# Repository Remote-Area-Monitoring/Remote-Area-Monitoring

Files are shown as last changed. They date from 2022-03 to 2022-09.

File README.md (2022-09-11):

# Remote-Area-Monitoring

# Product Overview
Remote Area Monitoring is a system designed to reduce the risk of forest fires to populated areas. Our system provides forest management personnel with a data rich view of their environment. The data is collected by a mesh network of sensing nodes and recorded to provide a history of environmental conditions. RAM provides granular insight for the area’s most at risk. Our hope is that the information gathered by our system will aid those responsible for forest management in the prevention of forest fires by prompting preventative actions.

# Design Overview
### YouTube Video:
Design Overview (https://youtu.be/89cSm1rO_VM "Remote Area Monitoring - Design Overview")

# Product Demonstration
### YouTube Video:
Project Demonstration (https://youtu.be/TYpCOS8Fa0I "Remote Area Monitoring - Project Demonstration")

#### Additional Note

This project was completed as part of the University of Central Florida, Department of Electrical and Computer Engineering's senior design program. The project was active from the Spring 2022 semester to the Summer 2022 semester.

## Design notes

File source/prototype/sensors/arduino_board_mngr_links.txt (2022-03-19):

http://arduino.esp8266.com/stable/package_esp8266com_index.json
https://arduino.esp8266.com/stable/package_esp8266com_index.json
https://dl.espressif.com/dl/package_esp32_index.json
https://raw.githubusercontent.com/damellis/attiny/ide-1.6.x-boards-manager/package_damellis_attiny_index.json

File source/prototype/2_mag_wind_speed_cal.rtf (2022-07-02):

⸮⸮⸮⸮⸮⸮⸮⸮⸮⸮⸮⸮⸮⸮⸮⸮⸮0
Calibration Factor: 440000
MPH: 0

0
Calibration Factor: 440000
MPH: 0

697669
Calibration Factor: 440000
MPH: 0

46506
Calibration Factor: 440000
MPH: 9

61710
Calibration Factor: 440000
MPH: 7

68220
Calibration Factor: 440000
MPH: 6

76857
Calibration Factor: 440000
MPH: 5

86480
Calibration Factor: 440000
MPH: 5

97868
Calibration Factor: 440000
MPH: 4

110669
Calibration Factor: 440000
MPH: 3

126365
Calibration Factor: 440000
MPH: 3

144545
Calibration Factor: 440000
MPH: 3

171445
Calibration Factor: 440000
MPH: 2

167685
Calibration Factor: 440000
MPH: 2

203662
Calibration Factor: 440000
MPH: 2

198138
Calibration Factor: 440000
MPH: 2

249998
Calibration Factor: 440000
MPH: 1

243616
Calibration Factor: 440000
MPH: 1

324397
Calibration Factor: 440000
MPH: 1

0
Calibration Factor: 440000
MPH: 0

0
Calibration Factor: 440000
MPH: 0

41045
Calibration Factor: 440000
MPH: 10

53567
Calibration Factor: 440000
MPH: 8

60402
Calibration Factor: 440000
MPH: 7

68616
Calibration Factor: 440000
MPH: 6

77975
Calibration Factor: 440000
MPH: 5

88577
Calibration Factor: 440000
MPH: 4

100935
Calibration Factor: 440000
MPH: 4

115527
Calibration Factor: 440000
MPH: 3

132681
Calibration Factor: 440000
MPH: 3

153295
Calibration Factor: 440000
MPH: 2

187713
Calibration Factor: 440000
MPH: 2

183324
Calibration Factor: 440000
MPH: 2

229262
Calibration Factor: 440000
MPH: 1

216572
Calibration Factor: 440000
MPH: 2

284705
Calibration Factor: 440000
MPH: 1

270662
Calibration Factor: 440000
MPH: 1

407159
Calibration Factor: 440000
MPH: 1

39072
Calibration Factor: 440000
MPH: 11

⸮⸮⸮⸮⸮⸮⸮⸮⸮⸮⸮⸮⸮Calibration Factor: 440000
MPH: 1
ADC Value: 264000

Calibration Factor: 440000
MPH: 1
ADC Value: 403740

Calibration Factor: 440000
MPH: 0
ADC Value: 0

Calibration Factor: 440000
MPH: 0
ADC Value: 0

Calibration Factor: 440000
MPH: 0
ADC Value: 0

Calibration Factor: 440000
MPH: 0
ADC Value: 0

Calibration Factor: 440000
MPH: 13
ADC Value: 33238

Calibration Factor: 440000
MPH: 10
ADC Value: 43509

Calibration Factor: 400000
MPH: 8
ADC Value: 49248

Calibration Factor: 440000
MPH: 5
ADC Value: 73870

Calibration Factor: 440000
MPH: 5
ADC Value: 84664

Calibration Factor: 440000
MPH: 4
ADC Value: 97695

Calibration Factor: 440000
MPH: 3
ADC Value: 112899

Calibration Factor: 440000
MPH: 3
ADC Value: 131107

Calibration Factor: 440000
MPH: 2
ADC Value: 154579

Calibration Factor: 440000
MPH: 0
ADC Value: 0

Calibration Factor: 440000
MPH: 1
ADC Value: 229021

Calibration Factor: 440000
MPH: 1
ADC Value: 320995

Calibration Factor: 440000
MPH: 1
ADC Value: 296799

Calibration Factor: 440000
MPH: 0
ADC Value: 0

Calibration Factor: 440000
MPH: 0
ADC Value: 0

Calibration Factor: 440000
MPH: 1
ADC Value: 424197

Calibration Factor: 400
MPH: 0
ADC Value: 0

Calibration Factor: 440000
MPH: 12
ADC Value: 34989

Calibration Factor: 440000
MPH: 9
ADC Value: 45162

Calibration Factor: 440000
MPH: 7
ADC Value: 60333

Calibration Factor: 440000
MPH: 6
ADC Value: 68371

Calibration Factor: 440000
MPH: 5
ADC Value: 78409

Calibration Factor: 440000
MPH: 4
ADC Value: 90128

Calibration Factor: 440000
MPH: 4
ADC Value: 107041

Calibration Factor: 440000
MPH: 3
ADC Value: 120852

Calibration Factor: 440000
MPH: 3
ADC Value: 146591

Calibration Factor: 440000
MPH: 2
ADC Value: 175896

Calibration Factor: 440000
MPH: 2
ADC Value: 167221

Calibration Factor: 440000
MPH: 2
ADC Value: 208370

Calibration Factor: 440000
MPH: 2
ADC Value: 206740

Calibration Factor: 440000
MPH: 1
ADC Value: 279189

Calibration Factor: 440000
MPH: 1
ADC Value: 268962

Calibration Factor: 440000
MPH: 0
ADC Value: 0

⸮⸮⸮⸮⸮⸮⸮⸮⸮⸮⸮⸮⸮⸮⸮⸮
MPH: 0
ADC Value: 0

Calibration Factor: 440000
MPH: 0
ADC Value: 0

Calibration Factor: 440000
MPH: 0
ADC Value: 0

Calibration Factor: 440000
MPH: 0
ADC Value: 0

Calibration Factor: 440000
MPH: 0
ADC Value: 0

Calibration Factor: 440000
MPH: 0
ADC Value: 0

Calibration Factor: 100
MPH: 0
ADC Value: 0

Calibration Factor: 100
MPH: 0
ADC Value: 0

Calibration Factor: 100
MPH: 0
ADC Value: 0

Calibration Factor: 100
MPH: 0
ADC Value: 0

Calibration Factor: 100
MPH: 0
ADC Value: 0

Calibration Factor: 440000
MPH: 0
ADC Value: 0

Calibration Factor: 440000
MPH: 0
ADC Value: 0

Calibration Factor: 440000
MPH: 0
ADC Value: 0

Calibration Factor: 440000
MPH: 0
ADC Value: 0

Calibration Factor: 440000
MPH: 0
ADC Value: 0

Calibration Factor: 440000
MPH: 1
ADC Value: 413428

Calibration Factor: 440000
MPH: 0
ADC Value: 0

Calibration Factor: 440000
MPH: 0
ADC Value: 0

Calibration Factor: 440000
MPH: 0
ADC Value: 0

Calibration Factor: 440000
MPH: 0
ADC Value: 0

Calibration Factor: 440000
MPH: 0
ADC Value: 629723

Calibration Factor: 440000
MPH: 0
ADC Value: 0

Calibration Factor: 440000
MPH: 1
ADC Value: 297886

Calibration Factor: 440000
MPH: 0
ADC Value: 0

Calibration Factor: 440000
MPH: 0
ADC Value: 0

Calibration Factor: 440000
MPH: 0
ADC Value: 0

Calibration Factor: 440000
MPH: 0
ADC Value: 0

Calibration Factor: 440000
MPH: 1
ADC Value: 328663

Calibration Factor: 440000
MPH: 0
ADC Value: 0

Calibration Factor: 440000
MPH: 0
ADC Value: 0

Calibration Factor: 440000
MPH: 0
ADC Value: 0

Calibration Factor: 440000
MPH: 0
ADC Value: 0

Calibration Factor: 440000
MPH: 0
ADC Value: 0

Calibration Factor: 440000
MPH: 0
ADC Value: 0

Calibration Factor: 440000
MPH: 0
ADC Value: 0

Calibration Factor: 440000
MPH: 0
ADC Value: 0

Calibration Factor: 440000
MPH: 0
ADC Value: 0

Calibration Factor: 440000
MPH: 0
ADC Value: 0

Calibration Factor: 440000
MPH: 0
ADC Value: 0

Calibration Factor: 440000
MPH: 0
ADC Value: 0

Calibration Factor: 440000
MPH: 0
ADC Value: 0

Calibration Factor: 440000
MPH: 0
ADC Value: 0

Calibration Factor: 440000
MPH: 0
ADC Value: 0

Calibration Factor: 440000
MPH: 0
ADC Value: 0

Calibration Factor: 440000
MPH: 0
ADC Value: 0

Calibration Factor: 440000
MPH: 0
ADC Value: 0

Calibration Factor: 440000
MPH: 0
ADC Value: 0

Calibration Factor: 440000
MPH: 0
ADC Value: 0

Calibration Factor: 440000
MPH: 0
ADC Value: 0

Calibration Factor: 440000
MPH: 0
ADC Value: 0

Calibration Factor: 440000
MPH: 0
ADC Value: 827596

Calibration Factor: 440000
MPH: 0
ADC Value: 0

Calibration Factor: 440000
MPH: 0
ADC Value: 0

Calibration Factor: 440000
MPH: 0
ADC Value: 0

Calibration Factor: 440000
MPH: 0
ADC Value: 0

Calibration Factor: 440000
MPH: 0
ADC Value: 852647

Calibration Factor: 440000
MPH: 0
ADC Value: 0

Calibration Factor: 440000
MPH: 0
ADC Value: 0

Calibration Factor: 440000
MPH: 0
ADC Value: 0

Calibration Factor: 440000
MPH: 0
ADC Value: 0

Calibration Factor: 440000
MPH: 0
ADC Value: 0

Calibration Factor: 440000
MPH: 0
ADC Value: 0

Calibration Factor: 440000
MPH: 0
ADC Value: 0

Calibration Factor: 440000
MPH: 0
ADC Value: 0

Calibration Factor: 440000
MPH: 0
ADC Value: 0

Calibration Factor: 440000
MPH: 0
ADC Value: 0

Calibration Factor: 440000
MPH: 0
ADC Value: 0

Calibration Factor: 440000
MPH: 0
ADC Value: 0

Calibration Factor: 440000
MPH: 0
ADC Value: 0

Calibration Factor: 440000
MPH: 0
ADC Value: 0

Calibration Factor: 440000
MPH: 0
ADC Value: 0

Calibration Factor: 440000
MPH: 0
ADC Value: 0

Calibration Factor: 440000
MPH: 0
ADC Value: 0

Calibration Factor: 440000
MPH: 0
ADC Value: 0

Calibration Factor: 440000
MPH: 0
ADC Value: 0

Calibration Factor: 440000
MPH: 0
ADC Value: 0

Calibration Factor: 440000
MPH: 1
ADC Value: 297017

Calibration Factor: 440000
MPH: 1
ADC Value: 232478

Calibration Factor: 440000
MPH: 1
ADC Value: 249034

Calibration Factor: 440000
MPH: 1
ADC Value: 337816

Calibration Factor: 440000
MPH: 0
ADC Value: 0

Calibration Factor: 440000
MPH: 0
ADC Value: 0

Calibration Factor: 440000
MPH: 0
ADC Value: 0

Calibration Factor: 440000
MPH: 0
ADC Value: 0

Calibration Factor: 440000
MPH: 0
ADC Value: 0

Calibration Factor: 440000
MPH: 0
ADC Value: 0

Calibration Factor: 440000
MPH: 0
ADC Value: 0

Calibration Factor: 440000
MPH: 0
ADC Value: 0

Calibration Factor: 440000
MPH: 0
ADC Value: 0

Calibration Factor: 440000
MPH: 0
ADC Value: 0

Calibration Factor: 440000
MPH: 0
ADC Value: 0

Calibration Factor: 440000
MPH: 0
ADC Value: 0

Calibration Factor: 440000
MPH: 0
ADC Value: 0

Calibration Factor: 440000
MPH: 3
ADC Value: 138251

Calibration Factor: 440000
MPH: 4
ADC Value: 90866

Calibration Factor: 440000
MPH: 5
ADC Value: 76495

Calibration Factor: 440000
MPH: 6
ADC Value: 68814

Calibration Factor: 440000
MPH: 6
ADC Value: 65779

Calibration Factor: 440000
MPH: 7
ADC Value: 62370

Calibration Factor: 440000
MPH: 6
ADC Value: 63720

Calibration Factor: 440000
MPH: 7
ADC Value: 56697

Calibration Factor: 440000
MPH: 7
ADC Value: 59416

Calibration Factor: 440000
MPH: 8
ADC Value: 54256

Calibration Factor: 440000
MPH: 7
ADC Value: 57383

Calibration Factor: 440000
MPH: 8
ADC Value: 53621

Calibration Factor: 440000
MPH: 7
ADC Value: 57124

Calibration Factor: 440000
MPH: 8
ADC Value: 53689

Calibration Factor: 440000
MPH: 7
ADC Value: 55016

Calibration Factor: 440000
MPH: 9
ADC Value: 47786

Calibration Factor: 440000
MPH: 8
ADC Value: 50380

Calibration Factor: 440000
MPH: 9
ADC Value: 46503

Calibration Factor: 440000
MPH: 8
ADC Value: 51317

Calibration Factor: 440000
MPH: 9
ADC Value: 47460

Calibration Factor: 440000
MPH: 8
ADC Value: 50912

Calibration Factor: 440000
MPH: 9
ADC Value: 48383

Calibration Factor: 440000
MPH: 8
ADC Value: 53628

Calibration Factor: 440000
MPH: 8
ADC Value: 52656

Calibration Factor: 440000
MPH: 8
ADC Value: 54645

Calibration Factor: 440000
MPH: 8
ADC Value: 50753

Calibration Factor: 440000
MPH: 8
ADC Value: 52085

Calibration Factor: 440000
MPH: 8
ADC Value: 49964

Calibration Factor: 440000
MPH: 8
ADC Value: 54000

Calibration Factor: 440000
MPH: 8
ADC Value: 52060

Calibration Factor: 440000
MPH: 7
ADC Value: 57375

Calibration Factor: 440000
MPH: 8
ADC Value: 54666

Calibration Factor: 440000
MPH: 7
ADC Value: 59769

Calibration Factor: 440000
MPH: 8
ADC Value: 53638

Calibration Factor: 440000
MPH: 7
ADC Value: 56216

Calibration Factor: 440000
MPH: 8
ADC Value: 49760

Calibration Factor: 440000
MPH: 8
ADC Value: 51353

Calibration Factor: 440000
MPH: 9
ADC Value: 46710

Calibration Factor: 440000
MPH: 8
ADC Value: 50500

Calibration Factor: 440000
MPH: 8
ADC Value: 48985

Calibration Factor: 440000
MPH: 8
ADC Value: 51606

Calibration Factor: 440000
MPH: 9
ADC Value: 46519

Calibration Factor: 440000
MPH: 8
ADC Value: 50575

Calibration Factor: 440000
MPH: 9
ADC Value: 46438

Calibration Factor: 440000
MPH: 8
ADC Value: 49724

Calibration Factor: 440000
MPH: 9
ADC Value: 45640

Calibration Factor: 440000
MPH: 8
ADC Value: 52134

Calibration Factor: 440000
MPH: 8
ADC Value: 51470

Calibration Factor: 440000
MPH: 7
ADC Value: 56753

Calibration Factor: 440000
MPH: 7
ADC Value: 55058

Calibration Factor: 440000
MPH: 7
ADC Value: 59278

Calibration Factor: 440000
MPH: 7
ADC Value: 56957

Calibration Factor: 440000
MPH: 7
ADC Value: 57993

Calibration Factor: 440000
MPH: 8
ADC Value: 53978

Calibration Factor: 440000
MPH: 7
ADC Value: 55894

Calibration Factor: 440000
MPH: 8
ADC Value: 52595

Calibration Factor: 440000
MPH: 7
ADC Value: 56569

Calibration Factor: 440000
MPH: 8
ADC Value: 52979

Calibration Factor: 440000
MPH: 7
ADC Value: 57048

Calibration Factor: 440000
MPH: 8
ADC Value: 53905

Calibration Factor: 440000
MPH: 7
ADC Value: 57776

Calibration Factor: 440000
MPH: 8
ADC Value: 54166

Calibration Factor: 440000
MPH: 7
ADC Value: 57539

Calibration Factor: 440000
MPH: 8
ADC Value: 54046

Calibration Factor: 440000
MPH: 7
ADC Value: 59211

Calibration Factor: 440000
MPH: 7
ADC Value: 55390

Calibration Factor: 440000
MPH: 7
ADC Value: 59659

Calibration Factor: 440000
MPH: 7
ADC Value: 55741

Calibration Factor: 440000
MPH: 7
ADC Value: 59294

Calibration Factor: 440000
MPH: 8
ADC Value: 54155

Calibration Factor: 440000
MPH: 7
ADC Value: 60061

Calibration Factor: 440000
MPH: 8
ADC Value: 54347

Calibration Factor: 440000
MPH: 7
ADC Value: 57579

Calibration Factor: 440000
MPH: 8
ADC Value: 51984

Calibration Factor: 440000
MPH: 8
ADC Value: 54128

Calibration Factor: 440000
MPH: 8
ADC Value: 49530

Calibration Factor: 440000
MPH: 8
ADC Value: 52668

Calibration Factor: 440000
MPH: 8
ADC Value: 49856

Calibration Factor: 440000
MPH: 7
ADC Value: 55154

Calibration Factor: 440000
MPH: 8
ADC Value: 52337

Calibration Factor: 440000
MPH: 7
ADC Value: 58661

Calibration Factor: 440000
MPH: 8
ADC Value: 53464

Calibration Factor: 440000
MPH: 7
ADC Value: 57097

Calibration Factor: 440000
MPH: 8
ADC Value: 52696

Calibration Factor: 440000
MPH: 7
ADC Value: 55896

Calibration Factor: 440000
MPH: 8
ADC Value: 51822

Calibration Factor: 440000
MPH: 7
ADC Value: 57787

Calibration Factor: 440000
MPH: 7
ADC Value: 55284

Calibration Factor: 440000
MPH: 7
ADC Value: 59953

Calibration Factor: 440000
MPH: 7
ADC Value: 56728

Calibration Factor: 440000
MPH: 7
ADC Value: 61077

Calibration Factor: 440000
MPH: 7
ADC Value: 55896

Calibration Factor: 440000
MPH: 7
ADC Value: 61715

Calibration Factor: 440000
MPH: 7
ADC Value: 57327

Calibration Factor: 440000
MPH: 7
ADC Value: 61162

Calibration Factor: 440000
MPH: 7
ADC Value: 55230

Calibration Factor: 440000
MPH: 7
ADC Value: 59225

Calibration Factor: 440000
MPH: 7
ADC Value: 55996

Calibration Factor: 440000
MPH: 7
ADC Value: 62493

Calibration Factor: 440000
MPH: 6
ADC Value: 63624

Calibration Factor: 440000
MPH: 6
ADC Value: 72723

Calibration Factor: 440000
MPH: 5
ADC Value: 83683

Calibration Factor: 440000
MPH: 4
ADC Value: 98997

Calibration Factor: 440000
MPH: 3
ADC Value: 126621

Calibration Factor: 440000
MPH: 2
ADC Value: 155741

Calibration Factor: 440000
MPH: 2
ADC Value: 189949

Calibration Factor: 440000
MPH: 2
ADC Value: 215852

Calibration Factor: 440000
MPH: 1
ADC Value: 341838

Calibration Factor: 440000
MPH: 0
ADC Value: 0

Calibration Factor: 530000
MPH: 0
ADC Value: 0

Calibration Factor: 530000
MPH: 0
ADC Value: 0

Calibration Factor: 530000
MPH: 0
ADC Value: 0

Calibration Factor: 530000
MPH: 0
ADC Value: 0

Calibration Factor: 530000
MPH: 4
ADC Value: 128226

Calibration Factor: 530000
MPH: 5
ADC Value: 97248

Calibration Factor: 530000
MPH: 5
ADC Value: 94814

Calibration Factor: 530000
MPH: 5
ADC Value: 95546

Calibration Factor: 530000
MPH: 5
ADC Value: 90325

Calibration Factor: 530000
MPH: 5
ADC Value: 89734

Calibration Factor: 530000
MPH: 5
ADC Value: 88677

Calibration Factor: 530000
MPH: 6
ADC Value: 77934

Calibration Factor: 530000
MPH: 7
ADC Value: 68154

Calibration Factor: 530000
MPH: 8
ADC Value: 62226

Calibration Factor: 530000
MPH: 8
ADC Value: 60702

Calibration Factor: 530000
MPH: 8
ADC Value: 64002

Calibration Factor: 530000
MPH: 9
ADC Value: 57741

Calibration Factor: 530000
MPH: 8
ADC Value: 60883

Calibration Factor: 530000
MPH: 9
ADC Value: 54624

Calibration Factor: 530000
MPH: 8
ADC Value: 58916

Calibration Factor: 530000
MPH: 9
ADC Value: 55230

Calibration Factor: 530000
MPH: 8
ADC Value: 58932

Calibration Factor: 530000
MPH: 9
ADC Value: 57962

Calibration Factor: 530000
MPH: 8
ADC Value: 63332

Calibration Factor: 530000
MPH: 8
ADC Value: 61984

Calibration Factor: 530000
MPH: 8
ADC Value: 62073

Calibration Factor: 530000
MPH: 8
ADC Value: 62070

Calibration Factor: 530000
MPH: 8
ADC Value: 63076

Calibration Factor: 530000
MPH: 8
ADC Value: 63835

Calibration Factor: 530000
MPH: 8
ADC Value: 62956

Calibration Factor: 530000
MPH: 8
ADC Value: 61484

Calibration Factor: 530000
MPH: 8
ADC Value: 62117

Calibration Factor: 530000
MPH: 8
ADC Value: 61454

Calibration Factor: 530000
MPH: 8
ADC Value: 64422

Calibration Factor: 530000
MPH: 8
ADC Value: 59221

Calibration Factor: 530000
MPH: 8
ADC Value: 61446

Calibration Factor: 530000
MPH: 9
ADC Value: 58042

Calibration Factor: 530000
MPH: 8
ADC Value: 63765

Calibration Factor: 530000
MPH: 8
ADC Value: 61871

Calibration Factor: 530000
MPH: 7
ADC Value: 68666

Calibration Factor: 530000
MPH: 6
ADC Value: 80689

Calibration Factor: 530000
MPH: 5
ADC Value: 99190

Calibration Factor: 530000
MPH: 4
ADC Value: 118714

Calibration Factor: 530000
MPH: 3
ADC Value: 149599

Calibration Factor: 530000
MPH: 3
ADC Value: 160725

Calibration Factor: 530000
MPH: 4
ADC Value: 131872

Calibration Factor: 530000
MPH: 6
ADC Value: 82141

Calibration Factor: 530000
MPH: 7
ADC Value: 66719

Calibration Factor: 530000
MPH: 8
ADC Value: 59491

Calibration Factor: 530000
MPH: 9
ADC Value: 57498

Calibration Factor: 530000
MPH: 9
ADC Value: 55934

Calibration Factor: 530000
MPH: 8
ADC Value: 60503

Calibration Factor: 530000
MPH: 9
ADC Value: 56987

Calibration Factor: 530000
MPH: 8
ADC Value: 60592

Calibration Factor: 530000
MPH: 9
ADC Value: 53930

Calibration Factor: 530000
MPH: 9
ADC Value: 54839

Calibration Factor: 530000
MPH: 11
ADC Value: 47084

Calibration Factor: 530000
MPH: 10
ADC Value: 48911

Calibration Factor: 530000
MPH: 11
ADC Value: 44825

Calibration Factor: 530000
MPH: 10
ADC Value: 50206

Calibration Factor: 530000
MPH: 11
ADC Value: 45306

Calibration Factor: 530000
MPH: 11
ADC Value: 47292

Calibration Factor: 530000
MPH: 12
ADC Value: 43532

Calibration Factor: 530000
MPH: 11
ADC Value: 47789

Calibration Factor: 530000
MPH: 11
ADC Value: 45996

Calibration Factor: 530000
MPH: 10
ADC Value: 49371

Calibration Factor: 530000
MPH: 11
ADC Value: 47612

Calibration Factor: 530000
MPH: 10
ADC Value: 51307

Calibration Factor: 530000
MPH: 10
ADC Value: 48668

Calibration Factor: 530000
MPH: 10
ADC Value: 52813

Calibration Factor: 530000
MPH: 10
ADC Value: 49965

Calibration Factor: 530000
MPH: 9
ADC Value: 54976

Calibration Factor: 530000
MPH: 10
ADC Value: 50708

Calibration Factor: 530000
MPH: 10
ADC Value: 50898

Calibration Factor: 530000
MPH: 11
ADC Value: 46425

Calibration Factor: 530000
MPH: 11
ADC Value: 47613

Calibration Factor: 530000
MPH: 12
ADC Value: 43031

Calibration Factor: 530000
MPH: 11
ADC Value: 47312

Calibration Factor: 530000
MPH: 11
ADC Value: 45468

Calibration Factor: 530000
MPH: 10
ADC Value: 49294

Calibration Factor: 530000
MPH: 12
ADC Value: 41682

Calibration Factor: 530000
MPH: 11
ADC Value: 45499

Calibration Factor: 530000
MPH: 12
ADC Value: 41766

Calibration Factor: 530000
MPH: 11
ADC Value: 45457

Calibration Factor: 530000
MPH: 12
ADC Value: 42749

Calibration Factor: 530000
MPH: 11
ADC Value: 45678

Calibration Factor: 530000
MPH: 12
ADC Value: 42692

Calibration Factor: 530000
MPH: 10
ADC Value: 49180

Calibration Factor: 530000
MPH: 11
ADC Value: 47774

Calibration Factor: 530000
MPH: 9
ADC Value: 53337

Calibration Factor: 530000
MPH: 10
ADC Value: 50845

Calibration Factor: 530000
MPH: 9
ADC Value: 57886

Calibration Factor: 530000
MPH: 9
ADC Value: 57763

Calibration Factor: 530000
MPH: 7
ADC Value: 70426

Calibration Factor: 530000
MPH: 7
ADC Value: 68802

Calibration Factor: 530000
MPH: 7
ADC Value: 66662

Calibration Factor: 530000
MPH: 9
ADC Value: 57727

Calibration Factor: 530000
MPH: 8
ADC Value: 60089

Calibration Factor: 530000
MPH: 9
ADC Value: 55241

Calibration Factor: 530000
MPH: 8
ADC Value: 59854

Calibration Factor: 530000
MPH: 9
ADC Value: 56344

Calibration Factor: 530000
MPH: 9
ADC Value: 58503

Calibration Factor: 530000
MPH: 9
ADC Value: 55647

Calibration Factor: 530000
MPH: 8
ADC Value: 59715

Calibration Factor: 530000
MPH: 9
ADC Value: 56426

Calibration Factor: 530000
MPH: 8
ADC Value: 61067

Calibration Factor: 530000
MPH: 9
ADC Value: 57389

Calibration Factor: 530000
MPH: 8
ADC Value: 61714

Calibration Factor: 530000
MPH: 9
ADC Value: 55697

Calibration Factor: 530000
MPH: 8
ADC Value: 59572

Calibration Factor: 530000
MPH: 9
ADC Value: 54264

Calibration Factor: 530000
MPH: 9
ADC Value: 58277

Calibration Factor: 530000
MPH: 9
ADC Value: 53387

Calibration Factor: 530000
MPH: 9
ADC Value: 56965

Calibration Factor: 530000
MPH: 9
ADC Value: 54553

Calibration Factor: 530000
MPH: 9
ADC Value: 58480

Calibration Factor: 530000
MPH: 9
ADC Value: 54761

Calibration Factor: 530000
MPH: 8
ADC Value: 59678

Calibration Factor: 570000
MPH: 10
ADC Value: 55684

Calibration Factor: 570000
MPH: 9
ADC Value: 61521

Calibration Factor: 570000
MPH: 9
ADC Value: 60771

Calibration Factor: 570000
MPH: 9
ADC Value: 61604

Calibration Factor: 570000
MPH: 9
ADC Value: 61245

Calibration Factor: 570000
MPH: 9
ADC Value: 60522

Calibration Factor: 570000
MPH: 9
ADC Value: 61024

Calibration Factor: 570000
MPH: 8
ADC Value: 65451

Calibration Factor: 570000
MPH: 7
ADC Value: 72301

Calibration Factor: 570000
MPH: 6
ADC Value: 83826

Calibration Factor: 570000
MPH: 5
ADC Value: 103102

Calibration Factor: 570000
MPH: 4
ADC Value: 132351

Calibration Factor: 570000
MPH: 3
ADC Value: 174855

Calibration Factor: 570000
MPH: 3
ADC Value: 183121

Calibration Factor: 570000
MPH: 3
ADC Value: 173233

Calibration Factor: 580000
MPH: 4
ADC Value: 134309

Calibration Factor: 580000
MPH: 7
ADC Value: 78256

Calibration Factor: 580000
MPH: 8
ADC Value: 70435

Calibration Factor: 580000
MPH: 8
ADC Value: 69094

Calibration Factor: 580000
MPH: 8
ADC Value: 65270

Calibration Factor: 580000
MPH: 8
ADC Value: 65672

Calibration Factor: 580000
MPH: 9
ADC Value: 62444

Calibration Factor: 580000
MPH: 9
ADC Value: 59863

Calibration Factor: 580000
MPH: 9
ADC Value: 61030

Calibration Factor: 580000
MPH: 10
ADC Value: 57414

Calibration Factor: 580000
MPH: 9
ADC Value: 62040

Calibration Factor: 580000
MPH: 10
ADC Value: 57850

Calibration Factor: 580000
MPH: 9
ADC Value: 59508

Calibration Factor: 580000
MPH: 10
ADC Value: 55102

Calibration Factor: 580000
MPH: 9
ADC Value: 59756

Calibration Factor: 580000
MPH: 10
ADC Value: 53017

Calibration Factor: 580000
MPH: 10
ADC Value: 54042

Calibration Factor: 580000
MPH: 11
ADC Value: 49289

Calibration Factor: 580000
MPH: 10
ADC Value: 54350

Calibration Factor: 585000
MPH: 11
ADC Value: 51596

Calibration Factor: 585000
MPH: 10
ADC Value: 55457

Calibration Factor: 585000
MPH: 10
ADC Value: 53212

Calibration Factor: 585000
MPH: 10
ADC Value: 57279

Calibration Factor: 585000
MPH: 10
ADC Value: 54375

Calibration Factor: 585000
MPH: 9
ADC Value: 58738

Calibration Factor: 585000
MPH: 10
ADC Value: 57427

Calibration Factor: 585000
MPH: 9
ADC Value: 60301

Calibration Factor: 585000
MPH: 10
ADC Value: 55475

Calibration Factor: 585000
MPH: 9
ADC Value: 58719

Calibration Factor: 585000
MPH: 11
ADC Value: 52903

Calibration Factor: 585000
MPH: 10
ADC Value: 54161

Calibration Factor: 585000
MPH: 11
ADC Value: 50619

Calibration Factor: 585000
MPH: 11
ADC Value: 53046

Calibration Factor: 585000
MPH: 12
ADC Value: 47472

Calibration Factor: 585000
MPH: 12
ADC Value: 46818

Calibration Factor: 585000
MPH: 14
ADC Value: 39994

Calibration Factor: 585000
MPH: 16
ADC Value: 35616

Calibration Factor: 585000
MPH: 18
ADC Value: 32497

Calibration Factor: 585000
MPH: 19
ADC Value: 30120

Calibration Factor: 585000
MPH: 20
ADC Value: 28617

Calibration Factor: 585000
MPH: 19
ADC Value: 29344

Calibration Factor: 585000
MPH: 21
ADC Value: 27295

Calibration Factor: 585000
MPH: 20
ADC Value: 27869

Calibration Factor: 585000
MPH: 22
ADC Value: 25691

Calibration Factor: 585000
MPH: 21
ADC Value: 26647

Calibration Factor: 585000
MPH: 24
ADC Value: 24315

Calibration Factor: 585000
MPH: 22
ADC Value: 26521

Calibration Factor: 585000
MPH: 24
ADC Value: 24033

Calibration Factor: 585000
MPH: 22
ADC Value: 26520

Calibration Factor: 585000
MPH: 23
ADC Value: 24817

Calibration Factor: 585000
MPH: 21
ADC Value: 27590

Calibration Factor: 585000
MPH: 22
ADC Value: 26087

Calibration Factor: 585000
MPH: 20
ADC Value: 28171

Calibration Factor: 585000
MPH: 22
ADC Value: 26402

Calibration Factor: 585000
MPH: 21
ADC Value: 27345

Calibration Factor: 585000
MPH: 22
ADC Value: 25719

Calibration Factor: 585000
MPH: 20
ADC Value: 28152

Calibration Factor: 585000
MPH: 22
ADC Value: 26369

Calibration Factor: 585000
MPH: 20
ADC Value: 28246

Calibration Factor: 585000
MPH: 21
ADC Value: 27520

Calibration Factor: 585000
MPH: 19
ADC Value: 30419

Calibration Factor: 585000
MPH: 20
ADC Value: 27903

Calibration Factor: 585000
MPH: 19
ADC Value: 30097

Calibration Factor: 585000
MPH: 20
ADC Value: 28017

Calibration Factor: 585000
MPH: 20
ADC Value: 28744

Calibration Factor: 585000
MPH: 21
ADC Value: 26926

Calibration Factor: 585000
MPH: 19
ADC Value: 29551

Calibration Factor: 585000
MPH: 20
ADC Value: 28016

Calibration Factor: 585000
MPH: 19
ADC Value: 30445

Calibration Factor: 585000
MPH: 20
ADC Value: 28189

Calibration Factor: 585000
MPH: 19
ADC Value: 30087

Calibration Factor: 585000
MPH: 20
ADC Value: 29160

Calibration Factor: 585000
MPH: 19
ADC Value: 30461

Calibration Factor: 585000
MPH: 19
ADC Value: 30055

Calibration Factor: 585000
MPH: 19
ADC Value: 30753

Calibration Factor: 585000
MPH: 18
ADC Value: 31006

Calibration Factor: 585000
MPH: 19
ADC Value: 29939

Calibration Factor: 585000
MPH: 19
ADC Value: 29555

Calibration Factor: 585000
MPH: 19
ADC Value: 29257

Calibration Factor: 585000
MPH: 19
ADC Value: 29712

Calibration Factor: 585000
MPH: 19
ADC Value: 29591

Calibration Factor: 585000
MPH: 20
ADC Value: 29065

Calibration Factor: 585000
MPH: 20
ADC Value: 28978

Calibration Factor: 585000
MPH: 19
ADC Value: 29308

Calibration Factor: 585000
MPH: 19
ADC Value: 29288

Calibration Factor: 585000
MPH: 20
ADC Value: 28585

Calibration Factor: 585000
MPH: 19
ADC Value: 30156

Calibration Factor: 585000
MPH: 20
ADC Value: 28362

Calibration Factor: 585000
MPH: 18
ADC Value: 30949

Calibration Factor: 585000
MPH: 18
ADC Value: 31738

Calibration Factor: 585000
MPH: 18
ADC Value: 31993

Calibration Factor: 585000
MPH: 18
ADC Value: 31208

Calibration Factor: 585000
MPH: 19
ADC Value: 30599

Calibration Factor: 585000
MPH: 21
ADC Value: 27780

Calibration Factor: 585000
MPH: 19
ADC Value: 30367

Calibration Factor: 585000
MPH: 19
ADC Value: 29848

Calibration Factor: 585000
MPH: 18
ADC Value: 32167

Calibration Factor: 585000
MPH: 16
ADC Value: 34821

Calibration Factor: 585000
MPH: 14
ADC Value: 40272

Calibration Factor: 585000
MPH: 11
ADC Value: 48891

Calibration Factor: 585000
MPH: 10
ADC Value: 54437

Calibration Factor: 585000
MPH: 8
ADC Value: 72719

Calibration Factor: 585000
MPH: 6
ADC Value: 88122

Calibration Factor: 585000
MPH: 5
ADC Value: 107776

Calibration Factor: 585000
MPH: 4
ADC Value: 123509

Calibration Factor: 585000
MPH: 3
ADC Value: 151420

Calibration Factor: 585000
MPH: 3
ADC Value: 158649

Calibration Factor: 585000
MPH: 3
ADC Value: 188285

Calibration Factor: 585000
MPH: 2
ADC Value: 197718

Calibration Factor: 585000
MPH: 2
ADC Value: 246102

Calibration Factor: 585000
MPH: 2
ADC Value: 276399

Calibration Factor: 585000
MPH: 1
ADC Value: 344962

Calibration Factor: 585000
MPH: 3
ADC Value: 167498

Calibration Factor: 585000
MPH: 7
ADC Value: 75835

Calibration Factor: 585000
MPH: 10
ADC Value: 55669

Calibration Factor: 585000
MPH: 11
ADC Value: 49999

Calibration Factor: 585000
MPH: 11
ADC Value: 50898

Calibration Factor: 585000
MPH: 13
ADC Value: 43787

Calibration Factor: 585000
MPH: 11
ADC Value: 52340

Calibration Factor: 585000
MPH: 11
ADC Value: 52048

Calibration Factor: 585000
MPH: 10
ADC Value: 53888

Calibration Factor: 585000
MPH: 11
ADC Value: 52667

Calibration Factor: 585000
MPH: 9
ADC Value: 64051

Calibration Factor: 585000
MPH: 8
ADC Value: 72136

Calibration Factor: 585000
MPH: 7
ADC Value: 80476

Calibration Factor: 585000
MPH: 6
ADC Value: 95987

Calibration Factor: 585000
MPH: 5
ADC Value: 115744

Calibration Factor: 585000
MPH: 4
ADC Value: 143149

Calibration Factor: 585000
MPH: 3
ADC Value: 157721

Calibration Factor: 585000
MPH: 3
ADC Value: 187558

Calibration Factor: 585000
MPH: 2
ADC Value: 228328

Calibration Factor: 585000
MPH: 2
ADC Value: 285291

Calibration Factor: 585000
MPH: 3
ADC Value: 169607

Calibration Factor: 585000
MPH: 8
ADC Value: 69617

Calibration Factor: 585000
MPH: 10
ADC Value: 53455

Calibration Factor: 585000
MPH: 14
ADC Value: 39226

Calibration Factor: 585000
MPH: 18
ADC Value: 31369

Calibration Factor: 585000
MPH: 21
ADC Value: 26865

Calibration Factor: 585000
MPH: 22
ADC Value: 26372

Calibration Factor: 585000
MPH: 25
ADC Value: 23368

Calibration Factor: 585000
MPH: 28
ADC Value: 20412

Calibration Factor: 585000
MPH: 29
ADC Value: 19923

Calibration Factor: 585000
MPH: 30
ADC Value: 19285

Calibration Factor: 585000
MPH: 29
ADC Value: 19662

Calibration Factor: 585000
MPH: 32
ADC Value: 18044

Calibration Factor: 585000
MPH: 30
ADC Value: 18924

Calibration Factor: 585000
MPH: 35
ADC Value: 16549

Calibration Factor: 585000
MPH: 33
ADC Value: 17679

Calibration Factor: 585000
MPH: 35
ADC Value: 16606

Calibration Factor: 585000
MPH: 34
ADC Value: 16739

Calibration Factor: 585000
MPH: 37
ADC Value: 15696

Calibration Factor: 585000
MPH: 38
ADC Value: 15028

Calibration Factor: 585000
MPH: 43
ADC Value: 13506

Calibration Factor: 585000
MPH: 40
ADC Value: 14513

Calibration Factor: 585000
MPH: 43
ADC Value: 13352

Calibration Factor: 585000
MPH: 39
ADC Value: 14671

Calibration Factor: 585000
MPH: 42
ADC Value: 13771

Calibration Factor: 585000
MPH: 39
ADC Value: 14929

Calibration Factor: 585000
MPH: 42
ADC Value: 13694

Calibration Factor: 585000
MPH: 39
ADC Value: 14914

Calibration Factor: 585000
MPH: 37
ADC Value: 15524

Calibration Factor: 585000
MPH: 37
ADC Value: 15396

Calibration Factor: 585000
MPH: 37
ADC Value: 15423

Calibration Factor: 585000
MPH: 40
ADC Value: 14582

Calibration Factor: 585000
MPH: 42
ADC Value: 13755

Calibration Factor: 585000
MPH: 39
ADC Value: 14874

Calibration Factor: 585000
MPH: 43
ADC Value: 13491

Calibration Factor: 585000
MPH: 39
ADC Value: 14695

Calibration Factor: 585000
MPH: 43
ADC Value: 13491

Calibration Factor: 585000
MPH: 39
ADC Value: 15000

Calibration Factor: 585000
MPH: 43
ADC Value: 13559

Calibration Factor: 585000
MPH: 40
ADC Value: 14620

Calibration Factor: 585000
MPH: 41
ADC Value: 13950

Calibration Factor: 585000
MPH: 40
ADC Value: 14507

Calibration Factor: 585000
MPH: 43
ADC Value: 13433

Calibration Factor: 585000
MPH: 39
ADC Value: 14697

Calibration Factor: 585000
MPH: 41
ADC Value: 14070

Calibration Factor: 585000
MPH: 40
ADC Value: 14361

Calibration Factor: 585000
MPH: 42
ADC Value: 13822

Calibration Factor: 585000
MPH: 39
ADC Value: 14901

Calibration Factor: 585000
MPH: 41
ADC Value: 14150

Calibration Factor: 585000
MPH: 40
ADC Value: 14322

Calibration Factor: 585000
MPH: 41
ADC Value: 14034

Calibration Factor: 585000
MPH: 40
ADC Value: 14325

Calibration Factor: 585000
MPH: 39
ADC Value: 14943

Calibration Factor: 585000
MPH: 39
ADC Value: 14937

Calibration Factor: 585000
MPH: 38
ADC Value: 15346

Calibration Factor: 585000
MPH: 41
ADC Value: 14033

Calibration Factor: 585000
MPH: 41
ADC Value: 14119

Calibration Factor: 585000
MPH: 40
ADC Value: 14573

Calibration Factor: 585000
MPH: 41
ADC Value: 14125

Calibration Factor: 585000
MPH: 40
ADC Value: 14617

Calibration Factor: 585000
MPH: 44
ADC Value: 13271

Calibration Factor: 585000
MPH: 40
ADC Value: 14380

Calibration Factor: 585000
MPH: 43
ADC Value: 13314

Calibration Factor: 585000
MPH: 40
ADC Value: 14408

Calibration Factor: 585000
MPH: 43
ADC Value: 13318

Calibration Factor: 585000
MPH: 40
ADC Value: 14333

Calibration Factor: 585000
MPH: 43
ADC Value: 13389

Calibration Factor: 585000
MPH: 40
ADC Value: 14299

Calibration Factor: 585000
MPH: 43
ADC Value: 13501

Calibration Factor: 585000
MPH: 39
ADC Value: 14873

Calibration Factor: 585000
MPH: 42
ADC Value: 13761

Calibration Factor: 585000
MPH: 39
ADC Value: 14991

Calibration Factor: 585000
MPH: 44
ADC Value: 13036

Calibration Factor: 585000
MPH: 41
ADC Value: 14235

Calibration Factor: 585000
MPH: 43
ADC Value: 13441

Calibration Factor: 585000
MPH: 39
ADC Value: 14957

Calibration Factor: 585000
MPH: 42
ADC Value: 13762

Calibration Factor: 585000
MPH: 41
ADC Value: 14098

Calibration Factor: 585000
MPH: 40
ADC Value: 14483

Calibration Factor: 585000
MPH: 40
ADC Value: 14566

Calibration Factor: 585000
MPH: 40
ADC Value: 14360

Calibration Factor: 585000
MPH: 39
ADC Value: 14793

Calibration Factor: 585000
MPH: 38
ADC Value: 15040

Calibration Factor: 585000
MPH: 38
ADC Value: 15183

Calibration Factor: 585000
MPH: 38
ADC Value: 15094

Calibration Factor: 585000
MPH: 37
ADC Value: 15697

Calibration Factor: 585000
MPH: 38
ADC Value: 15367

Calibration Factor: 585000
MPH: 36
ADC Value: 15977

Calibration Factor: 585000
MPH: 37
ADC Value: 15656

Calibration Factor: 585000
MPH: 36
ADC Value: 15879

Calibration Factor: 585000
MPH: 37
ADC Value: 15657

Calibration Factor: 585000
MPH: 37
ADC Value: 15447

Calibration Factor: 585000
MPH: 38
ADC Value: 15110

Calibration Factor: 585000
MPH: 36
ADC Value: 15955

Calibration Factor: 585000
MPH: 36
ADC Value: 16077

Calibration Factor: 585000
MPH: 33
ADC Value: 17289

Calibration Factor: 585000
MPH: 34
ADC Value: 16766

Calibration Factor: 585000
MPH: 34
ADC Value: 17068

Calibration Factor: 585000
MPH: 35
ADC Value: 16708

Calibration Factor: 585000
MPH: 34
ADC Value: 17015

Calibration Factor: 585000
MPH: 36
ADC Value: 16204

Calibration Factor: 585000
MPH: 34
ADC Value: 17037

Calibration Factor: 585000
MPH: 36
ADC Value: 16045

Calibration Factor: 585000
MPH: 33
ADC Value: 17587

Calibration Factor: 585000
MPH: 36
ADC Value: 15864

Calibration Factor: 585000
MPH: 33
ADC Value: 17466

Calibration Factor: 585000
MPH: 35
ADC Value: 16398

Calibration Factor: 585000
MPH: 33
ADC Value: 17562

Calibration Factor: 585000
MPH: 37
ADC Value: 15480

Calibration Factor: 585000
MPH: 38
ADC Value: 15338

Calibration Factor: 585000
MPH: 39
ADC Value: 14967

Calibration Factor: 585000
MPH: 39
ADC Value: 14987

Calibration Factor: 585000
MPH: 38
ADC Value: 15249

Calibration Factor: 585000
MPH: 37
ADC Value: 15598

Calibration Factor: 585000
MPH: 37
ADC Value: 15485

Calibration Factor: 585000
MPH: 37
ADC Value: 15609

Calibration Factor: 585000
MPH: 38
ADC Value: 15217

Calibration Factor: 585000
MPH: 38
ADC Value: 15028

Calibration Factor: 585000
MPH: 38
ADC Value: 15141

Calibration Factor: 585000
MPH: 39
ADC Value: 14797

Calibration Factor: 585000
MPH: 38
ADC Value: 15082

Calibration Factor: 585000
MPH: 39
ADC Value: 14928

Calibration Factor: 585000
MPH: 38
ADC Value: 15228

Calibration Factor: 585000
MPH: 38
ADC Value: 15156

Calibration Factor: 585000
MPH: 38
ADC Value: 15307

Calibration Factor: 585000
MPH: 39
ADC Value: 14849

Calibration Factor: 585000
MPH: 39
ADC Value: 14960

Calibration Factor: 585000
MPH: 38
ADC Value: 15331

Calibration Factor: 585000
MPH: 38
ADC Value: 15163

Calibration Factor: 585000
MPH: 36
ADC Value: 15847

Calibration Factor: 585000
MPH: 36
ADC Value: 16213

Calibration Factor: 585000
MPH: 33
ADC Value: 17369

Calibration Factor: 585000
MPH: 35
ADC Value: 16372

Calibration Factor: 585000
MPH: 32
ADC Value: 17902

Calibration Factor: 585000
MPH: 34
ADC Value: 16972

Calibration Factor: 585000
MPH: 32
ADC Value: 18172

Calibration Factor: 585000
MPH: 33
ADC Value: 17298

Calibration Factor: 585000
MPH: 30
ADC Value: 19078

Calibration Factor: 585000
MPH: 32
ADC Value: 17985

Calibration Factor: 585000
MPH: 29
ADC Value: 19783

Calibration Factor: 585000
MPH: 31
ADC Value: 18612

Calibration Factor: 585000
MPH: 29
ADC Value: 19620

Calibration Factor: 585000
MPH: 28
ADC Value: 20627

Calibration Factor: 585000
MPH: 27
ADC Value: 21384

Calibration Factor: 585000
MPH: 25
ADC Value: 22853

Calibration Factor: 585000
MPH: 22
ADC Value: 25804

Calibration Factor: 585000
MPH: 22
ADC Value: 25476

Calibration Factor: 585000
MPH: 19
ADC Value: 29889

Calibration Factor: 585000
MPH: 17
ADC Value: 33162

Calibration Factor: 585000
MPH: 17
ADC Value: 34312

Calibration Factor: 585000
MPH: 15
ADC Value: 37626

Calibration Factor: 585000
MPH: 12
ADC Value: 45760

Calibration Factor: 585000
MPH: 12
ADC Value: 48358

Calibration Factor: 585000
MPH: 10
ADC Value: 53449

Calibration Factor: 585000
MPH: 10
ADC Value: 54473

Calibration Factor: 585000
MPH: 10
ADC Value: 57687

Calibration Factor: 585000
MPH: 10
ADC Value: 56068

Calibration Factor: 585000
MPH: 9
ADC Value: 64616

Calibration Factor: 585000
MPH: 9
ADC Value: 61457

Calibration Factor: 585000
MPH: 9
ADC Value: 61163

Calibration Factor: 585000
MPH: 9
ADC Value: 60331

Calibration Factor: 585000
MPH: 10
ADC Value: 55222

Calibration Factor: 585000
MPH: 10
ADC Value: 55512

Calibration Factor: 585000
MPH: 11
ADC Value: 49559

Calibration Factor: 585000
MPH: 11
ADC Value: 50090

Calibration Factor: 585000
MPH: 12
ADC Value: 45136

Calibration Factor: 585000
MPH: 12
ADC Value: 45959

Calibration Factor: 585000
MPH: 14
ADC Value: 41440

Calibration Factor: 585000
MPH: 13
ADC Value: 43027

Calibration Factor: 585000
MPH: 15
ADC Value: 38393

Calibration Factor: 585000
MPH: 16
ADC Value: 36168

Calibration Factor: 585000
MPH: 16
ADC Value: 35146

Calibration Factor: 585000
MPH: 16
ADC Value: 34428

Calibration Factor: 585000
MPH: 18
ADC Value: 32287

Calibration Factor: 585000
MPH: 18
ADC Value: 32137

Calibration Factor: 585000
MPH: 18
ADC Value: 31609

Calibration Factor: 585000
MPH: 19
ADC Value: 30395

Calibration Factor: 585000
MPH: 19
ADC Value: 29731

Calibration Factor: 585000
MPH: 19
ADC Value: 30444

Calibration Factor: 585000
MPH: 19
ADC Value: 30631

Calibration Factor: 585000
MPH: 19
ADC Value: 30502

Calibration Factor: 585000
MPH: 19
ADC Value: 30640

Calibration Factor: 585000
MPH: 18
ADC Value: 31175

Calibration Factor: 585000
MPH: 18
ADC Value: 31347

Calibration Factor: 585000
MPH: 18
ADC Value: 31823

Calibration Factor: 585000
MPH: 18
ADC Value: 31808

Calibration Factor: 585000
MPH: 18
ADC Value: 31551

Calibration Factor: 585000
MPH: 18
ADC Value: 32270

Calibration Factor: 585000
MPH: 17
ADC Value: 32896

Calibration Factor: 585000
MPH: 17
ADC Value: 33391

Calibration Factor: 585000
MPH: 18
ADC Value: 32298

Calibration Factor: 585000
MPH: 18
ADC Value: 32012

Calibration Factor: 585000
MPH: 17
ADC Value: 33527

Calibration Factor: 585000
MPH: 18
ADC Value: 31985

Calibration Factor: 585000
MPH: 18
ADC Value: 31835

Calibration Factor: 585000
MPH: 19
ADC Value: 30507

Calibration Factor: 585000
MPH: 19
ADC Value: 29911

Calibration Factor: 585000
MPH: 19
ADC Value: 29608

Calibration Factor: 585000
MPH: 20
ADC Value: 28857

Calibration Factor: 585000
MPH: 19
ADC Value: 30585

Calibration Factor: 585000
MPH: 20
ADC Value: 29157

Calibration Factor: 585000
MPH: 19
ADC Value: 30275

Calibration Factor: 585000
MPH: 18
ADC Value: 31205

Calibration Factor: 585000
MPH: 18
ADC Value: 30885

Calibration Factor: 585000
MPH: 18
ADC Value: 30834

Calibration Factor: 585000
MPH: 19
ADC Value: 30092

Calibration Factor: 585000
MPH: 19
ADC Value: 29298

Calibration Factor: 585000
MPH: 19
ADC Value: 29522

Calibration Factor: 585000
MPH: 18
ADC Value: 31123

Calibration Factor: 585000
MPH: 18
ADC Value: 31925

Calibration Factor: 585000
MPH: 18
ADC Value: 30972

Calibration Factor: 585000
MPH: 18
ADC Value: 30917

Calibration Factor: 585000
MPH: 19
ADC Value: 30478

Calibration Factor: 585000
MPH: 19
ADC Value: 30576

Calibration Factor: 585000
MPH: 19
ADC Value: 30542

Calibration Factor: 585000
MPH: 19
ADC Value: 30734

Calibration Factor: 585000
MPH: 19
ADC Value: 30119

Calibration Factor: 585000
MPH: 19
ADC Value: 29989

Calibration Factor: 585000
MPH: 19
ADC Value: 29742

Calibration Factor: 585000
MPH: 19
ADC Value: 29710

Calibration Factor: 585000
MPH: 19
ADC Value: 30082

Calibration Factor: 585000
MPH: 19
ADC Value: 30436

Calibration Factor: 585000
MPH: 18
ADC Value: 32119

Calibration Factor: 585000
MPH: 17
ADC Value: 34175

Calibration Factor: 585000
MPH: 16
ADC Value: 36479

Calibration Factor: 585000
MPH: 14
ADC Value: 40900

Calibration Factor: 585000
MPH: 11
ADC Value: 49035

Calibration Factor: 585000
MPH: 10
ADC Value: 53327

⸮⸮⸮⸮⸮⸮⸮⸮⸮⸮⸮⸮⸮⸮⸮⸮⸮
MPH: 13
ADC Value: 43399

Calibration Factor: 585000
MPH: 14
ADC Value: 40350

Calibration Factor: 585000
MPH: 15
ADC Value: 37939

Calibration Factor: 585000
MPH: 16
ADC Value: 35105

Calibration Factor: 585000
MPH: 16
ADC Value: 35248

Calibration Factor: 585000
MPH: 16
ADC Value: 35517

Calibration Factor: 585000
MPH: 16
ADC Value: 36260

Calibration Factor: 585000
MPH: 16
ADC Value: 36301

Calibration Factor: 585000
MPH: 15
ADC Value: 36793

Calibration Factor: 585000
MPH: 16
ADC Value: 36240

Calibration Factor: 585000
MPH: 15
ADC Value: 36792

Calibration Factor: 585000
MPH: 15
ADC Value: 37547

Calibration Factor: 585000
MPH: 15
ADC Value: 37451

Calibration Factor: 585000
MPH: 15
ADC Value: 38260

Calibration Factor: 585000
MPH: 14
ADC Value: 41453

Calibration Factor: 585000
MPH: 12
ADC Value: 46232

Calibration Factor: 585000
MPH: 10
ADC Value: 53333

Calibration Factor: 585000
MPH: 8
ADC Value: 73040

Calibration Factor: 585000
MPH: 6
ADC Value: 97424

Calibration Factor: 585000
MPH: 4
ADC Value: 118383

Calibration Factor: 585000
MPH: 5
ADC Value: 108920

Calibration Factor: 585000
MPH: 6
ADC Value: 91054

Calibration Factor: 585000
MPH: 7
ADC Value: 80081

Calibration Factor: 585000
MPH: 7
ADC Value: 78037

Calibration Factor: 585000
MPH: 7
ADC Value: 75285

Calibration Factor: 585000
MPH: 7
ADC Value: 73194

Calibration Factor: 585000
MPH: 8
ADC Value: 71409

Calibration Factor: 585000
MPH: 8
ADC Value: 67247

Calibration Factor: 585000
MPH: 8
ADC Value: 67877

Calibration Factor: 585000
MPH: 8
ADC Value: 66475

Calibration Factor: 585000
MPH: 8
ADC Value: 67362

Calibration Factor: 585000
MPH: 9
ADC Value: 64516

Calibration Factor: 585000
MPH: 9
ADC Value: 61388

Calibration Factor: 585000
MPH: 9
ADC Value: 63419

Calibration Factor: 585000
MPH: 8
ADC Value: 65705

Calibration Factor: 585000
MPH: 7
ADC Value: 75366

Calibration Factor: 585000
MPH: 7
ADC Value: 79785

Calibration Factor: 585000
MPH: 7
ADC Value: 74956

Calibration Factor: 585000
MPH: 8
ADC Value: 71293

Calibration Factor: 585000
MPH: 8
ADC Value: 68336

Calibration Factor: 585000
MPH: 8
ADC Value: 67985

Calibration Factor: 585000
MPH: 8
ADC Value: 66538

Calibration Factor: 585000
MPH: 8
ADC Value: 65678

Calibration Factor: 585000
MPH: 8
ADC Value: 66671

Calibration Factor: 585000
MPH: 8
ADC Value: 66775

Calibration Factor: 585000
MPH: 9
ADC Value: 63146

Calibration Factor: 585000
MPH: 9
ADC Value: 59806

Calibration Factor: 585000
MPH: 9
ADC Value: 58709

Calibration Factor: 585000
MPH: 9
ADC Value: 59485

Calibration Factor: 585000
MPH: 9
ADC Value: 61690

Calibration Factor: 585000
MPH: 9
ADC Value: 61824

Calibration Factor: 585000
MPH: 8
ADC Value: 65539

Calibration Factor: 585000
MPH: 7
ADC Value: 79836

Calibration Factor: 585000
MPH: 5
ADC Value: 103594

Calibration Factor: 585000
MPH: 5
ADC Value: 116861

Calibration Factor: 585000
MPH: 7
ADC Value: 82475

Calibration Factor: 585000
MPH: 9
ADC Value: 64354

Calibration Factor: 585000
MPH: 11
ADC Value: 51484

Calibration Factor: 585000
MPH: 12
ADC Value: 48540

Calibration Factor: 585000
MPH: 11
ADC Value: 50672

Calibration Factor: 585000
MPH: 11
ADC Value: 51771

Calibration Factor: 585000
MPH: 11
ADC Value: 52781

Calibration Factor: 585000
MPH: 11
ADC Value: 53015

Calibration Factor: 585000
MPH: 10
ADC Value: 55793

Calibration Factor: 585000
MPH: 10
ADC Value: 57602

Calibration Factor: 585000
MPH: 9
ADC Value: 61243

Calibration Factor: 585000
MPH: 8
ADC Value: 65544

Calibration Factor: 585000
MPH: 9
ADC Value: 63558

Calibration Factor: 585000
MPH: 9
ADC Value: 63953

Calibration Factor: 585000
MPH: 9
ADC Value: 61751

Calibration Factor: 585000
MPH: 10
ADC Value: 56210

Calibration Factor: 585000
MPH: 10
ADC Value: 55541

Calibration Factor: 585000
MPH: 10
ADC Value: 57362

Calibration Factor: 585000
MPH: 10
ADC Value: 56881

Calibration Factor: 585000
MPH: 10
ADC Value: 57771

Calibration Factor: 585000
MPH: 9
ADC Value: 59081

Calibration Factor: 585000
MPH: 9
ADC Value: 60349

Calibration Factor: 585000
MPH: 9
ADC Value: 60989

Calibration Factor: 585000
MPH: 9
ADC Value: 61047

Calibration Factor: 585000
MPH: 10
ADC Value: 58468

Calibration Factor: 585000
MPH: 10
ADC Value: 57004

Calibration Factor: 585000
MPH: 10
ADC Value: 57329

Calibration Factor: 585000
MPH: 9
ADC Value: 59797

Calibration Factor: 585000
MPH: 9
ADC Value: 60050

Calibration Factor: 585000
MPH: 9
ADC Value: 59793

Calibration Factor: 585000
MPH: 10
ADC Value: 56374

Calibration Factor: 585000
MPH: 10
ADC Value: 56192

Calibration Factor: 585000
MPH: 9
ADC Value: 60067

Calibration Factor: 585000
MPH: 9
ADC Value: 59235

Calibration Factor: 585000
MPH: 10
ADC Value: 55468

Calibration Factor: 585000
MPH: 9
ADC Value: 58977

Calibration Factor: 585000
MPH: 9
ADC Value: 60958

Calibration Factor: 585000
MPH: 9
ADC Value: 64248

Calibration Factor: 585000
MPH: 8
ADC Value: 68697

Calibration Factor: 585000
MPH: 8
ADC Value: 66418

Calibration Factor: 585000
MPH: 9
ADC Value: 64448

Calibration Factor: 585000
MPH: 8
ADC Value: 65396

Calibration Factor: 585000
MPH: 8
ADC Value: 65696

Calibration Factor: 585000
MPH: 8
ADC Value: 66274

Calibration Factor: 585000
MPH: 9
ADC Value: 64893

Calibration Factor: 585000
MPH: 9
ADC Value: 63831

Calibration Factor: 585000
MPH: 8
ADC Value: 65234

Calibration Factor: 585000
MPH: 8
ADC Value: 65162

Calibration Factor: 585000
MPH: 8
ADC Value: 67069

Calibration Factor: 585000
MPH: 8
ADC Value: 70801

Calibration Factor: 585000
MPH: 7
ADC Value: 75752

Calibration Factor: 585000
MPH: 7
ADC Value: 75163

Calibration Factor: 585000
MPH: 7
ADC Value: 78688

Calibration Factor: 585000
MPH: 7
ADC Value: 75976

Calibration Factor: 585000
MPH: 8
ADC Value: 71701

Calibration Factor: 585000
MPH: 8
ADC Value: 72526

Calibration Factor: 585000
MPH: 7
ADC Value: 74773

Calibration Factor: 670000
MPH: 8
ADC Value: 76050

Calibration Factor: 670000
MPH: 9
ADC Value: 70389

Calibration Factor: 670000
MPH: 10
ADC Value: 63073

Calibration Factor: 670000
MPH: 11
ADC Value: 57022

Calibration Factor: 670000
MPH: 12
ADC Value: 52764

Calibration Factor: 670000
MPH: 13
ADC Value: 48706

Calibration Factor: 670000
MPH: 14
ADC Value: 47778

Calibration Factor: 670000
MPH: 14
ADC Value: 46099

Calibration Factor: 670000
MPH: 14
ADC Value: 45365

Calibration Factor: 670000
MPH: 14
ADC Value: 45763

Calibration Factor: 670000
MPH: 14
ADC Value: 45163

Calibration Factor: 670000
MPH: 14
ADC Value: 46263

Calibration Factor: 670000
MPH: 13
ADC Value: 48847

Calibration Factor: 670000
MPH: 13
ADC Value: 49697

Calibration Factor: 670000
MPH: 14
ADC Value: 46960

Calibration Factor: 670000
MPH: 14
ADC Value: 46958

Calibration Factor: 670000
MPH: 13
ADC Value: 48288

Calibration Factor: 670000
MPH: 12
ADC Value: 51983

Calibration Factor: 670000
MPH: 11
ADC Value: 56477

Calibration Factor: 670000
MPH: 11
ADC Value: 60261

Calibration Factor: 670000
MPH: 10
ADC Value: 65285

Calibration Factor: 670000
MPH: 10
ADC Value: 65661

Calibration Factor: 670000
MPH: 10
ADC Value: 61303

Calibration Factor: 670000
MPH: 12
ADC Value: 55417

Calibration Factor: 670000
MPH: 12
ADC Value: 52186

Calibration Factor: 670000
MPH: 13
ADC Value: 50671

Calibration Factor: 670000
MPH: 13
ADC Value: 51159

Calibration Factor: 670000
MPH: 14
ADC Value: 47493

Calibration Factor: 670000
MPH: 14
ADC Value: 45183

Calibration Factor: 670000
MPH: 14
ADC Value: 45354

Calibration Factor: 670000
MPH: 14
ADC Value: 45498

Calibration Factor: 670000
MPH: 14
ADC Value: 46442

Calibration Factor: 670000
MPH: 13
ADC Value: 49201

Calibration Factor: 670000
MPH: 11
ADC Value: 57595

Calibration Factor: 670000
MPH: 9
ADC Value: 73159

Calibration Factor: 670000
MPH: 7
ADC Value: 84063

Calibration Factor: 670000
MPH: 7
ADC Value: 90995

Calibration Factor: 670000
MPH: 7
ADC Value: 84092

Calibration Factor: 670000
MPH: 9
ADC Value: 73654

Calibration Factor: 670000
MPH: 10
ADC Value: 63593

Calibration Factor: 670000
MPH: 11
ADC Value: 56077

Calibration Factor: 670000
MPH: 12
ADC Value: 55039

Calibration Factor: 670000
MPH: 13
ADC Value: 50782

Calibration Factor: 670000
MPH: 13
ADC Value: 48473

Calibration Factor: 670000
MPH: 14
ADC Value: 46996

Calibration Factor: 670000
MPH: 14
ADC Value: 45446

Calibration Factor: 670000
MPH: 14
ADC Value: 45206

Calibration Factor: 670000
MPH: 14
ADC Value: 44806

Calibration Factor: 670000
MPH: 14
ADC Value: 44703

Calibration Factor: 670000
MPH: 13
ADC Value: 47861

Calibration Factor: 670000
MPH: 13
ADC Value: 49851

Calibration Factor: 670000
MPH: 12
ADC Value: 53849

Calibration Factor: 670000
MPH: 9
ADC Value: 69477

Calibration Factor: 670000
MPH: 7
ADC Value: 89461

Calibration Factor: 670000
MPH: 5
ADC Value: 120286

Calibration Factor: 670000
MPH: 4
ADC Value: 141939

Calibration Factor: 670000
MPH: 6
ADC Value: 111245

Calibration Factor: 670000
MPH: 7
ADC Value: 88834

Calibration Factor: 670000
MPH: 7
ADC Value: 84201

Calibration Factor: 600000
MPH: 7
ADC Value: 78387

Calibration Factor: 600000
MPH: 8
ADC Value: 72063

Calibration Factor: 600000
MPH: 8
ADC Value: 71273

Calibration Factor: 600000
MPH: 8
ADC Value: 68663

Calibration Factor: 600000
MPH: 9
ADC Value: 66616

Calibration Factor: 600000
MPH: 9
ADC Value: 63595

Calibration Factor: 600000
MPH: 10
ADC Value: 59515

Calibration Factor: 600000
MPH: 9
ADC Value: 60003

Calibration Factor: 600000
MPH: 10
ADC Value: 56342

Calibration Factor: 600000
MPH: 11
ADC Value: 53237

Calibration Factor: 600000
MPH: 11
ADC Value: 52879

Calibration Factor: 600000
MPH: 11
ADC Value: 51137

Calibration Factor: 600000
MPH: 12
ADC Value: 49090

Calibration Factor: 600000
MPH: 12
ADC Value: 49894

Calibration Factor: 600000
MPH: 10
ADC Value: 54665

Calibration Factor: 585000
MPH: 9
ADC Value: 58616

Calibration Factor: 585000
MPH: 9
ADC Value: 60132

Calibration Factor: 585000
MPH: 10
ADC Value: 58268

Calibration Factor: 585000
MPH: 10
ADC Value: 57917

Calibration Factor: 585000
MPH: 10
ADC Value: 56763

Calibration Factor: 585000
MPH: 9
ADC Value: 59538

Calibration Factor: 585000
MPH: 9
ADC Value: 60159

Calibration Factor: 585000
MPH: 9
ADC Value: 62365

Calibration Factor: 585000
MPH: 9
ADC Value: 60565

Calibration Factor: 590000
MPH: 10
ADC Value: 56254

Calibration Factor: 590000
MPH: 10
ADC Value: 56556

Calibration Factor: 590000
MPH: 10
ADC Value: 55671

Calibration Factor: 590000
MPH: 10
ADC Value: 55579

Calibration Factor: 590000
MPH: 10
ADC Value: 58873

Calibration Factor: 590000
MPH: 9
ADC Value: 59954

Calibration Factor: 590000
MPH: 10
ADC Value: 56234

Calibration Factor: 590000
MPH: 11
ADC Value: 53492

Calibration Factor: 590000
MPH: 11
ADC Value: 52813

Calibration Factor: 590000
MPH: 11
ADC Value: 52768

Calibration Factor: 590000
MPH: 11
ADC Value: 53338

Calibration Factor: 590000
MPH: 11
ADC Value: 51663

Calibration Factor: 590000
MPH: 11
ADC Value: 52607

Calibration Factor: 590000
MPH: 10
ADC Value: 55705

Calibration Factor: 590000
MPH: 8
ADC Value: 66808

Calibration Factor: 590000
MPH: 8
ADC Value: 67035

Calibration Factor: 590000
MPH: 8
ADC Value: 73007

Calibration Factor: 590000
MPH: 7
ADC Value: 80863

Calibration Factor: 590000
MPH: 7
ADC Value: 83192

Calibration Factor: 590000
MPH: 7
ADC Value: 78034

Calibration Factor: 590000
MPH: 7
ADC Value: 76631

Calibration Factor: 590000
MPH: 7
ADC Value: 78411

Calibration Factor: 590000
MPH: 7
ADC Value: 81014

Calibration Factor: 590000
MPH: 6
ADC Value: 85158

Calibration Factor: 585000
MPH: 7
ADC Value: 81041

Calibration Factor: 585000
MPH: 7
ADC Value: 78065

Calibration Factor: 585000
MPH: 7
ADC Value: 79320

Calibration Factor: 585000
MPH: 7
ADC Value: 79565

Calibration Factor: 585000
MPH: 7
ADC Value: 74605

Calibration Factor: 585000
MPH: 8
ADC Value: 66448

Calibration Factor: 585000
MPH: 11
ADC Value: 52224

Calibration Factor: 585000
MPH: 12
ADC Value: 46470

Calibration Factor: 585000
MPH: 13
ADC Value: 43037

Calibration Factor: 585000
MPH: 13
ADC Value: 42547

Calibration Factor: 585000
MPH: 13
ADC Value: 43186

Calibration Factor: 585000
MPH: 13
ADC Value: 42533

Calibration Factor: 585000
MPH: 14
ADC Value: 41772

Calibration Factor: 585000
MPH: 13
ADC Value: 43722

Calibration Factor: 585000
MPH: 14
ADC Value: 41649

Calibration Factor: 585000
MPH: 14
ADC Value: 40477

Calibration Factor: 585000
MPH: 14
ADC Value: 41706

Calibration Factor: 585000
MPH: 13
ADC Value: 44656

Calibration Factor: 585000
MPH: 12
ADC Value: 48738

Calibration Factor: 585000
MPH: 11
ADC Value: 50516

Calibration Factor: 585000
MPH: 12
ADC Value: 48517

Calibration Factor: 585000
MPH: 11
ADC Value: 50510

Calibration Factor: 585000
MPH: 10
ADC Value: 54459

Calibration Factor: 585000
MPH: 10
ADC Value: 58080

Calibration Factor: 585000
MPH: 10
ADC Value: 56901

Calibration Factor: 585000
MPH: 10
ADC Value: 56920

Calibration Factor: 585000
MPH: 10
ADC Value: 55857

Calibration Factor: 585000
MPH: 10
ADC Value: 56400

Calibration Factor: 585000
MPH: 10
ADC Value: 58331

Calibration Factor: 585000
MPH: 10
ADC Value: 54431

Calibration Factor: 610000
MPH: 12
ADC Value: 50690

Calibration Factor: 610000
MPH: 12
ADC Value: 48918

Calibration Factor: 610000
MPH: 12
ADC Value: 47614

Calibration Factor: 610000
MPH: 13
ADC Value: 44531

Calibration Factor: 610000
MPH: 15
ADC Value: 38993

Calibration Factor: 610000
MPH: 17
ADC Value: 34944

Calibration Factor: 610000
MPH: 18
ADC Value: 32304

Calibration Factor: 610000
MPH: 19
ADC Value: 31147

Calibration Factor: 610000
MPH: 21
ADC Value: 29031

Calibration Factor: 610000
MPH: 21
ADC Value: 28415

Calibration Factor: 610000
MPH: 20
ADC Value: 30017

Calibration Factor: 610000
MPH: 20
ADC Value: 30043

Calibration Factor: 610000
MPH: 19
ADC Value: 30655

Calibration Factor: 610000
MPH: 19
ADC Value: 30660

Calibration Factor: 610000
MPH: 20
ADC Value: 29853

Calibration Factor: 610000
MPH: 19
ADC Value: 31414

Calibration Factor: 610000
MPH: 17
ADC Value: 35329

Calibration Factor: 610000
MPH: 15
ADC Value: 39738

Calibration Factor: 600000
MPH: 13
ADC Value: 46068

Calibration Factor: 600000
MPH: 7
ADC Value: 77079

Calibration Factor: 600000
MPH: 6
ADC Value: 99450

Calibration Factor: 600000
MPH: 6
ADC Value: 96175

Calibration Factor: 600000
MPH: 8
ADC Value: 73923

Calibration Factor: 600000
MPH: 9
ADC Value: 64542

Calibration Factor: 600000
MPH: 10
ADC Value: 55938

Calibration Factor: 600000
MPH: 11
ADC Value: 51711

Calibration Factor: 600000
MPH: 13
ADC Value: 44887

Calibration Factor: 600000
MPH: 15
ADC Value: 38550

Calibration Factor: 600000
MPH: 18
ADC Value: 33294

Calibration Factor: 600000
MPH: 19
ADC Value: 30365

Calibration Factor: 600000
MPH: 22
ADC Value: 27151

Calibration Factor: 600000
MPH: 24
ADC Value: 24397

Calibration Factor: 600000
MPH: 25
ADC Value: 23528

Calibration Factor: 600000
MPH: 27
ADC Value: 21849

Calibration Factor: 600000
MPH: 28
ADC Value: 20702

Calibration Factor: 600000
MPH: 28
ADC Value: 20897

Calibration Factor: 600000
MPH: 27
ADC Value: 22098

Calibration Factor: 600000
MPH: 26
ADC Value: 22890

Calibration Factor: 600000
MPH: 25
ADC Value: 23864

Calibration Factor: 600000
MPH: 24
ADC Value: 24155

Calibration Factor: 600000
MPH: 24
ADC Value: 24353

Calibration Factor: 600000
MPH: 25
ADC Value: 23536

Calibration Factor: 600000
MPH: 25
ADC Value: 23558

Calibration Factor: 600000
MPH: 25
ADC Value: 23491

Calibration Factor: 600000
MPH: 26
ADC Value: 22670

Calibration Factor: 600000
MPH: 27
ADC Value: 22025

Calibration Factor: 600000
MPH: 28
ADC Value: 21372

Calibration Factor: 600000
MPH: 28
ADC Value: 21128

Calibration Factor: 600000
MPH: 27
ADC Value: 21455

Calibration Factor: 600000
MPH: 26
ADC Value: 22326

Calibration Factor: 600000
MPH: 26
ADC Value: 22875

Calibration Factor: 600000
MPH: 26
ADC Value: 22414

Calibration Factor: 600000
MPH: 26
ADC Value: 22397

Calibration Factor: 600000
MPH: 26
ADC Value: 22227

Calibration Factor: 600000
MPH: 27
ADC Value: 21631

Calibration Factor: 600000
MPH: 26
ADC Value: 22486

Calibration Factor: 585000
MPH: 25
ADC Value: 22666

Calibration Factor: 585000
MPH: 26
ADC Value: 21995

Calibration Factor: 585000
MPH: 26
ADC Value: 22355

Calibration Factor: 585000
MPH: 25
ADC Value: 23274

Calibration Factor: 585000
MPH: 25
ADC Value: 22965

Calibration Factor: 585000
MPH: 24
ADC Value: 23576

Calibration Factor: 585000
MPH: 24
ADC Value: 23453

Calibration Factor: 585000
MPH: 25
ADC Value: 23275

Calibration Factor: 585000
MPH: 24
ADC Value: 23728

Calibration Factor: 585000
MPH: 23
ADC Value: 25279

Calibration Factor: 590000
MPH: 21
ADC Value: 27020

Calibration Factor: 590000
MPH: 16
ADC Value: 35899

Calibration Factor: 590000
MPH: 12
ADC Value: 45534

Calibration Factor: 590000
MPH: 9
ADC Value: 61845

Calibration Factor: 590000
MPH: 7
ADC Value: 80658

Calibration Factor: 590000
MPH: 5
ADC Value: 103334

Calibration Factor: 590000
MPH: 5
ADC Value: 102597

Calibration Factor: 590000
MPH: 7
ADC Value: 81542

Calibration Factor: 590000
MPH: 9
ADC Value: 60580

Calibration Factor: 590000
MPH: 12
ADC Value: 46794

Calibration Factor: 590000
MPH: 14
ADC Value: 39845

Calibration Factor: 590000
MPH: 17
ADC Value: 33233

Calibration Factor: 590000
MPH: 19
ADC Value: 29830

Calibration Factor: 590000
MPH: 22
ADC Value: 26654

Calibration Factor: 590000
MPH: 23
ADC Value: 25469

Calibration Factor: 590000
MPH: 23
ADC Value: 24753

Calibration Factor: 590000
MPH: 25
ADC Value: 23434

Calibration Factor: 590000
MPH: 27
ADC Value: 21287

Calibration Factor: 590000
MPH: 29
ADC Value: 20017

Calibration Factor: 590000
MPH: 30
ADC Value: 19146

Calibration Factor: 590000
MPH: 32
ADC Value: 18200

Calibration Factor: 590000
MPH: 34
ADC Value: 17147

Calibration Factor: 590000
MPH: 35
ADC Value: 16836

Calibration Factor: 590000
MPH: 35
ADC Value: 16435

Calibration Factor: 590000
MPH: 37
ADC Value: 15703

Calibration Factor: 590000
MPH: 37
ADC Value: 15702

Calibration Factor: 590000
MPH: 41
ADC Value: 14331

Calibration Factor: 590000
MPH: 41
ADC Value: 14164

Calibration Factor: 590000
MPH: 40
ADC Value: 14435

Calibration Factor: 590000
MPH: 39
ADC Value: 14766

Calibration Factor: 590000
MPH: 39
ADC Value: 14769

Calibration Factor: 590000
MPH: 39
ADC Value: 14942

Calibration Factor: 590000
MPH: 42
ADC Value: 13839

Calibration Factor: 590000
MPH: 44
ADC Value: 13407

Calibration Factor: 590000
MPH: 43
ADC Value: 13460

Calibration Factor: 590000
MPH: 42
ADC Value: 13839

Calibration Factor: 590000
MPH: 41
ADC Value: 14129

Calibration Factor: 590000
MPH: 40
ADC Value: 14419

Calibration Factor: 590000
MPH: 40
ADC Value: 14628

Calibration Factor: 590000
MPH: 41
ADC Value: 14212

Calibration Factor: 590000
MPH: 41
ADC Value: 14164

Calibration Factor: 590000
MPH: 41
ADC Value: 14358

Calibration Factor: 590000
MPH: 40
ADC Value: 14398

Calibration Factor: 590000
MPH: 40
ADC Value: 14479

Calibration Factor: 590000
MPH: 40
ADC Value: 14556

Calibration Factor: 590000
MPH: 40
ADC Value: 14571

Calibration Factor: 590000
MPH: 41
ADC Value: 14372

Calibration Factor: 590000
MPH: 40
ADC Value: 14454

Calibration Factor: 590000
MPH: 39
ADC Value: 14813

Calibration Factor: 590000
MPH: 41
ADC Value: 14304

Calibration Factor: 590000
MPH: 39
ADC Value: 14794

Calibration Factor: 590000
MPH: 39
ADC Value: 14924

Calibration Factor: 590000
MPH: 38
ADC Value: 15223

Calibration Factor: 590000
MPH: 39
ADC Value: 15080

Calibration Factor: 590000
MPH: 39
ADC Value: 14978

Calibration Factor: 590000
MPH: 39
ADC Value: 14918

Calibration Factor: 590000
MPH: 39
ADC Value: 14812

Calibration Factor: 590000
MPH: 38
ADC Value: 15210

Calibration Factor: 590000
MPH: 38
ADC Value: 15265

Calibration Factor: 590000
MPH: 39
ADC Value: 14882

Calibration Factor: 590000
MPH: 39
ADC Value: 14957

Calibration Factor: 590000
MPH: 39
ADC Value: 15068

Calibration Factor: 590000
MPH: 37
ADC Value: 15614

Calibration Factor: 590000
MPH: 40
ADC Value: 14433

Calibration Factor: 590000
MPH: 41
ADC Value: 14074

Calibration Factor: 590000
MPH: 42
ADC Value: 13764

Calibration Factor: 590000
MPH: 42
ADC Value: 13958

Calibration Factor: 590000
MPH: 41
ADC Value: 14120

Calibration Factor: 590000
MPH: 40
ADC Value: 14445

Calibration Factor: 590000
MPH: 42
ADC Value: 13851

Calibration Factor: 590000
MPH: 41
ADC Value: 14130

Calibration Factor: 590000
MPH: 39
ADC Value: 14764

Calibration Factor: 590000
MPH: 39
ADC Value: 15025

Calibration Factor: 590000
MPH: 39
ADC Value: 14752

Calibration Factor: 590000
MPH: 40
ADC Value: 14515

Calibration Factor: 590000
MPH: 41
ADC Value: 14263

Calibration Factor: 590000
MPH: 40
ADC Value: 14584

Calibration Factor: 590000
MPH: 40
ADC Value: 14599

Calibration Factor: 590000
MPH: 40
ADC Value: 14487

Calibration Factor: 590000
MPH: 41
ADC Value: 14241

Calibration Factor: 590000
MPH: 40
ADC Value: 14697

Calibration Factor: 590000
MPH: 39
ADC Value: 14913

Calibration Factor: 590000
MPH: 38
ADC Value: 15154

Calibration Factor: 590000
MPH: 38
ADC Value: 15340

Calibration Factor: 590000
MPH: 38
ADC Value: 15317

Calibration Factor: 590000
MPH: 37
ADC Value: 15761

Calibration Factor: 590000
MPH: 38
ADC Value: 15519

Calibration Factor: 590000
MPH: 38
ADC Value: 15423

Calibration Factor: 590000
MPH: 37
ADC Value: 15663

Calibration Factor: 590000
MPH: 37
ADC Value: 15821

Calibration Factor: 590000
MPH: 38
ADC Value: 15261

Calibration Factor: 590000
MPH: 38
ADC Value: 15507

Calibration Factor: 590000
MPH: 39
ADC Value: 15081

Calibration Factor: 590000
MPH: 40
ADC Value: 14571

Calibration Factor: 590000
MPH: 41
ADC Value: 14375

Calibration Factor: 590000
MPH: 41
ADC Value: 14307

Calibration Factor: 590000
MPH: 43
ADC Value: 13611

Calibration Factor: 590000
MPH: 44
ADC Value: 13375

Calibration Factor: 590000
MPH: 45
ADC Value: 13007

Calibration Factor: 590000
MPH: 44
ADC Value: 13150

Calibration Factor: 590000
MPH: 45
ADC Value: 13072

Calibration Factor: 590000
MPH: 44
ADC Value: 13364

Calibration Factor: 600000
MPH: 46
ADC Value: 12894

Calibration Factor: 600000
MPH: 49
ADC Value: 12107

Calibration Factor: 600000
MPH: 48
ADC Value: 12249

Calibration Factor: 600000
MPH: 49
ADC Value: 12009

Calibration Factor: 600000
MPH: 48
ADC Value: 12344

Calibration Factor: 600000
MPH: 48
ADC Value: 12389

Calibration Factor: 600000
MPH: 48
ADC Value: 12334

Calibration Factor: 600000
MPH: 49
ADC Value: 12061

Calibration Factor: 600000
MPH: 48
ADC Value: 12385

Calibration Factor: 600000
MPH: 47
ADC Value: 12519

Calibration Factor: 600000
MPH: 48
ADC Value: 12445

Calibration Factor: 600000
MPH: 49
ADC Value: 12008

Calibration Factor: 600000
MPH: 49
ADC Value: 12239

Calibration Factor: 600000
MPH: 48
ADC Value: 12456

Calibration Factor: 600000
MPH: 47
ADC Value: 12605

Calibration Factor: 600000
MPH: 46
ADC Value: 12773

Calibration Factor: 600000
MPH: 47
ADC Value: 12729

Calibration Factor: 600000
MPH: 47
ADC Value: 12722

Calibration Factor: 600000
MPH: 48
ADC Value: 12402

Calibration Factor: 600000
MPH: 46
ADC Value: 12905

Calibration Factor: 600000
MPH: 46
ADC Value: 12935

Calibration Factor: 600000
MPH: 47
ADC Value: 12709

Calibration Factor: 600000
MPH: 46
ADC Value: 12914

Calibration Factor: 600000
MPH: 46
ADC Value: 12949

Calibration Factor: 600000
MPH: 48
ADC Value: 12415

Calibration Factor: 600000
MPH: 49
ADC Value: 12228

Calibration Factor: 600000
MPH: 48
ADC Value: 12413

Calibration Factor: 600000
MPH: 49
ADC Value: 12205

Calibration Factor: 600000
MPH: 49
ADC Value: 12212

Calibration Factor: 600000
MPH: 49
ADC Value: 12234

Calibration Factor: 600000
MPH: 47
ADC Value: 12546

Calibration Factor: 600000
MPH: 49
ADC Value: 12232

Calibration Factor: 600000
MPH: 48
ADC Value: 12324

Calibration Factor: 600000
MPH: 47
ADC Value: 12562

Calibration Factor: 595000
MPH: 47
ADC Value: 12524

Calibration Factor: 595000
MPH: 46
ADC Value: 12800

Calibration Factor: 595000
MPH: 45
ADC Value: 12935

Calibration Factor: 595000
MPH: 46
ADC Value: 12854

Calibration Factor: 595000
MPH: 47
ADC Value: 12499

Calibration Factor: 595000
MPH: 48
ADC Value: 12280

Calibration Factor: 595000
MPH: 48
ADC Value: 12292

Calibration Factor: 595000
MPH: 48
ADC Value: 12366

Calibration Factor: 595000
MPH: 47
ADC Value: 12488

Calibration Factor: 595000
MPH: 46
ADC Value: 12707

Calibration Factor: 595000
MPH: 47
ADC Value: 12480

Calibration Factor: 595000
MPH: 44
ADC Value: 13419

Calibration Factor: 595000
MPH: 41
ADC Value: 14355

Calibration Factor: 595000
MPH: 39
ADC Value: 15059

Calibration Factor: 595000
MPH: 39
ADC Value: 14989

Calibration Factor: 595000
MPH: 36
ADC Value: 16308

Calibration Factor: 595000
MPH: 34
ADC Value: 17189

Calibration Factor: 595000
MPH: 30
ADC Value: 19199

Calibration Factor: 595000
MPH: 27
ADC Value: 21647

Calibration Factor: 595000
MPH: 24
ADC Value: 24448

Calibration Factor: 595000
MPH: 20
ADC Value: 28334

Calibration Factor: 595000
MPH: 17
ADC Value: 33418

Calibration Factor: 595000
MPH: 14
ADC Value: 42137

Calibration Factor: 595000
MPH: 10
ADC Value: 54334

Calibration Factor: 595000
MPH: 9
ADC Value: 61836

Calibration Factor: 595000
MPH: 9
ADC Value: 60722

Calibration Factor: 595000
MPH: 10
ADC Value: 58526

Calibration Factor: 595000
MPH: 11
ADC Value: 50992

Calibration Factor: 595000
MPH: 13
ADC Value: 43655

Calibration Factor: 595000
MPH: 15
ADC Value: 38616

Calibration Factor: 595000
MPH: 16
ADC Value: 35855

Calibration Factor: 595000
MPH: 17
ADC Value: 34692

Calibration Factor: 595000
MPH: 17
ADC Value: 33665

Calibration Factor: 595000
MPH: 18
ADC Value: 32623

Calibration Factor: 595000
MPH: 18
ADC Value: 31791

Calibration Factor: 595000
MPH: 19
ADC Value: 30033

Calibration Factor: 595000
MPH: 20
ADC Value: 29233

Calibration Factor: 595000
MPH: 20
ADC Value: 29270

Calibration Factor: 595000
MPH: 20
ADC Value: 28945

Calibration Factor: 595000
MPH: 20
ADC Value: 29411

Calibration Factor: 595000
MPH: 20
ADC Value: 29424

Calibration Factor: 595000
MPH: 20
ADC Value: 28787

Calibration Factor: 595000
MPH: 20
ADC Value: 28583

Calibration Factor: 595000
MPH: 20
ADC Value: 29372

Calibration Factor: 595000
MPH: 18
ADC Value: 31549

Calibration Factor: 595000
MPH: 16
ADC Value: 35177

Calibration Factor: 595000
MPH: 14
ADC Value: 40967

Calibration Factor: 595000
MPH: 12
ADC Value: 46848

Calibration Factor: 595000
MPH: 10
ADC Value: 56286

Calibration Factor: 595000
MPH: 10
ADC Value: 58937

Calibration Factor: 595000
MPH: 10
ADC Value: 58316

Calibration Factor: 595000
MPH: 11
ADC Value: 52572

Calibration Factor: 595000
MPH: 13
ADC Value: 45544

Calibration Factor: 595000
MPH: 14
ADC Value: 39986

Calibration Factor: 595000
MPH: 16
ADC Value: 35436

Calibration Factor: 595000
MPH: 17
ADC Value: 33309

Calibration Factor: 595000
MPH: 18
ADC Value: 31436

Calibration Factor: 595000
MPH: 20
ADC Value: 29235

Calibration Factor: 595000
MPH: 21
ADC Value: 28008

Calibration Factor: 595000
MPH: 21
ADC Value: 27252

Calibration Factor: 595000
MPH: 22
ADC Value: 25897

Calibration Factor: 595000
MPH: 23
ADC Value: 25859

Calibration Factor: 595000
MPH: 22
ADC Value: 26074

Calibration Factor: 595000
MPH: 22
ADC Value: 26721

Calibration Factor: 595000
MPH: 22
ADC Value: 26731

Calibration Factor: 595000
MPH: 20
ADC Value: 29032

Calibration Factor: 595000
MPH: 20
ADC Value: 29651

Calibration Factor: 595000
MPH: 19
ADC Value: 29758

Calibration Factor: 595000
MPH: 20
ADC Value: 28728

Calibration Factor: 595000
MPH: 20
ADC Value: 28943

Calibration Factor: 595000
MPH: 20
ADC Value: 29727

Calibration Factor: 595000
MPH: 19
ADC Value: 30056

Calibration Factor: 595000
MPH: 19
ADC Value: 30025

Calibration Factor: 595000
MPH: 19
ADC Value: 31000

Calibration Factor: 595000
MPH: 18
ADC Value: 31584

Calibration Factor: 595000
MPH: 19
ADC Value: 30667

Calibration Factor: 595000
MPH: 19
ADC Value: 29955

Calibration Factor: 595000
MPH: 19
ADC Value: 29951

Calibration Factor: 595000
MPH: 19
ADC Value: 30197

Calibration Factor: 595000
MPH: 19
ADC Value: 30848

Calibration Factor: 595000
MPH: 18
ADC Value: 32548

Calibration Factor: 595000
MPH: 16
ADC Value: 35044

Calibration Factor: 595000
MPH: 17
ADC Value: 34825

Calibration Factor: 595000
MPH: 16
ADC Value: 36428

Calibration Factor: 595000
MPH: 15
ADC Value: 37676

Calibration Factor: 595000
MPH: 14
ADC Value: 41419

Calibration Factor: 595000
MPH: 13
ADC Value: 44341

Calibration Factor: 595000
MPH: 11
ADC Value: 51466

Calibration Factor: 595000
MPH: 8
ADC Value: 66989

Calibration Factor: 595000
MPH: 7
ADC Value: 81234

Calibration Factor: 595000
MPH: 5
ADC Value: 101271

Calibration Factor: 595000
MPH: 5
ADC Value: 118175

Calibration Factor: 595000
MPH: 6
ADC Value: 87059

Calibration Factor: 595000
MPH: 9
ADC Value: 65035

Calibration Factor: 595000
MPH: 10
ADC Value: 55973

Calibration Factor: 595000
MPH: 11
ADC Value: 52063

Calibration Factor: 595000
MPH: 11
ADC Value: 49719

Calibration Factor: 595000
MPH: 12
ADC Value: 47891

Calibration Factor: 595000
MPH: 10
ADC Value: 58295

Calibration Factor: 595000
MPH: 8
ADC Value: 72416

Calibration Factor: 595000
MPH: 6
ADC Value: 91429

Calibration Factor: 595000
MPH: 6
ADC Value: 94370

Calibration Factor: 595000
MPH: 8
ADC Value: 72541

Calibration Factor: 595000
MPH: 9
ADC Value: 60110

Calibration Factor: 595000
MPH: 10
ADC Value: 54690

Calibration Factor: 595000
MPH: 12
ADC Value: 48911

Calibration Factor: 595000
MPH: 12
ADC Value: 48262

Calibration Factor: 595000
MPH: 14
ADC Value: 41798

Calibration Factor: 595000
MPH: 14
ADC Value: 40240

Calibration Factor: 595000
MPH: 14
ADC Value: 41004

Calibration Factor: 595000
MPH: 13
ADC Value: 43579

Calibration Factor: 595000
MPH: 13
ADC Value: 44402

Calibration Factor: 595000
MPH: 13
ADC Value: 44089

Calibration Factor: 595000
MPH: 12
ADC Value: 47426

Calibration Factor: 595000
MPH: 11
ADC Value: 50818

Calibration Factor: 595000
MPH: 10
ADC Value: 57243

Calibration Factor: 595000
MPH: 8
ADC Value: 68914

Calibration Factor: 595000
MPH: 7
ADC Value: 78318

Calibration Factor: 595000
MPH: 8
ADC Value: 73246

Calibration Factor: 595000
MPH: 8
ADC Value: 69010

Calibration Factor: 595000
MPH: 9
ADC Value: 62298

Calibration Factor: 595000
MPH: 12
ADC Value: 49126

Calibration Factor: 595000
MPH: 14
ADC Value: 42274

Calibration Factor: 595000
MPH: 15
ADC Value: 38005

Calibration Factor: 595000
MPH: 16
ADC Value: 35495

Calibration Factor: 595000
MPH: 17
ADC Value: 33889

Calibration Factor: 595000
MPH: 18
ADC Value: 32685

Calibration Factor: 595000
MPH: 18
ADC Value: 31599

Calibration Factor: 595000
MPH: 18
ADC Value: 31359

Calibration Factor: 595000
MPH: 19
ADC Value: 30855

Calibration Factor: 595000
MPH: 19
ADC Value: 30899

Calibration Factor: 595000
MPH: 19
ADC Value: 30328

Calibration Factor: 595000
MPH: 19
ADC Value: 30141

Calibration Factor: 595000
MPH: 19
ADC Value: 31029

Calibration Factor: 595000
MPH: 20
ADC Value: 29273

Calibration Factor: 595000
MPH: 20
ADC Value: 29496

Calibration Factor: 595000
MPH: 20
ADC Value: 29403

Calibration Factor: 595000
MPH: 19
ADC Value: 29950

Calibration Factor: 595000
MPH: 20
ADC Value: 29270

Calibration Factor: 595000
MPH: 20
ADC Value: 28402

Calibration Factor: 595000
MPH: 21
ADC Value: 27280

Calibration Factor: 595000
MPH: 20
ADC Value: 29394

Calibration Factor: 595000
MPH: 18
ADC Value: 31504

Calibration Factor: 595000
MPH: 17
ADC Value: 33182

Calibration Factor: 595000
MPH: 17
ADC Value: 33418

Calibration Factor: 595000
MPH: 18
ADC Value: 31543

Calibration Factor: 595000
MPH: 18
ADC Value: 31490

Calibration Factor: 595000
MPH: 18
ADC Value: 31376

Calibration Factor: 595000
MPH: 18
ADC Value: 31666

Calibration Factor: 595000
MPH: 18
ADC Value: 33032

Calibration Factor: 595000
MPH: 16
ADC Value: 36381

Calibration Factor: 595000
MPH: 15
ADC Value: 39167

Calibration Factor: 595000
MPH: 14
ADC Value: 41315

Calibration Factor: 595000
MPH: 13
ADC Value: 43268

Calibration Factor: 595000
MPH: 12
ADC Value: 45912

Calibration Factor: 595000
MPH: 11
ADC Value: 50474

Calibration Factor: 595000
MPH: 10
ADC Value: 57025

Calibration Factor: 595000
MPH: 9
ADC Value: 64228

Calibration Factor: 595000
MPH: 7
ADC Value: 79828

Calibration Factor: 595000
MPH: 5
ADC Value: 105002

Calibration Factor: 595000
MPH: 4
ADC Value: 143460

Calibration Factor: 595000
MPH: 3
ADC Value: 176728

Calibration Factor: 595000
MPH: 5
ADC Value: 108872

Calibration Factor: 595000
MPH: 3
ADC Value: 160041

Calibration Factor: 595000
MPH: 0
ADC Value: 0

Calibration Factor: 595000
MPH: 0
ADC Value: 0

Calibration Factor: 595000
MPH: 0
ADC Value: 0

Calibration Factor: 595000
MPH: 2
ADC Value: 212454

Calibration Factor: 595000
MPH: 3
ADC Value: 166015

Calibration Factor: 595000
MPH: 3
ADC Value: 156990

Calibration Factor: 595000
MPH: 3
ADC Value: 168958

Calibration Factor: 595000
MPH: 0
ADC Value: 0

Calibration Factor: 595000
MPH: 0
ADC Value: 0

Calibration Factor: 595000
MPH: 0
ADC Value: 0

Calibration Factor: 595000
MPH: 2
ADC Value: 290031

Calibration Factor: 595000
MPH: 0
ADC Value: 0

Calibration Factor: 595000
MPH: 0
ADC Value: 0

Calibration Factor: 595000
MPH: 0
ADC Value: 0

Calibration Factor: 595000
MPH: 0
ADC Value: 0

Calibration Factor: 595000
MPH: 1
ADC Value: 352504

Calibration Factor: 595000
MPH: 0
ADC Value: 0

Calibration Factor: 595000
MPH: 0
ADC Value: 0

Calibration Factor: 595000
MPH: 0
ADC Value: 0

Calibration Factor: 595000
MPH: 0
ADC Value: 0

Calibration Factor: 595000
MPH: 0
ADC Value: 0

Calibration Factor: 595000
MPH: 0
ADC Value: 0

Calibration Factor: 595000
MPH: 0
ADC Value: 0

Calibration Factor: 595000
MPH: 0
ADC Value: 0

Calibration Factor: 595000
MPH: 0
ADC Value: 0

Calibration Factor: 595000
MPH: 0
ADC Value: 0

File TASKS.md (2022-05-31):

# Prep for Demo

## Hardware
- Take / store pictures of hardware creation
- discuss what is working 
- discuss what is not working
## Website
### Pages for Demo
- Map View
  - Point map of all nodes 
  - hexagon map
  - gradient map?
  - any others?
- Graph View
  - line over time 
  - scatter plot with trend line 
- Management 
  - node table 
  - edit node
  - add node 
  - remove node

# Development Tasks
These tasks will be in support of developing our system

## Logging
### Development
Logging is an *integral* part of the development process. The tools developed for this task will be used across all 
modules. 
An easy way to think of logging is as a *replacement for print statements*. 
Each time a log event occurs, the time, date, module, and message are recorded to a *non-volatile* file.
This allows us as developers to look back at the log files and view any issues our program runs into when we are not 
actively monitoring it. 

#### Requirements

| RID | Name | Description |
| --- | ---- | --- |
| 00 | Available from any module | the ability to write events to the/a log file should be available from any module |
| 01 | Organized | whether the logs save to a single file or multiple, the origin module, time and date need to be clear |
| 02 | single instantiation | The logging module should be instantiated once at the beginning of the module creating logs |
| 03 | simple to use | The complexity of use should be no more than a print statement |
| 04 | capture tracebacks | stretch goal -- tracebacks may be created during try/except blocks, look into the details that may be collected to aid the debugging process |

#### Resources

- [Stack Overflow - Logging across modules](https://stackoverflow.com/questions/15727420/using-logging-in-multiple-modules)
- [Python Docs - Logging](https://docs.python.org/3/library/logging.html)
- [Python Docs - Logging Config](https://docs.python.org/3/library/logging.config.html)

## Maps
### Web

Much of the data we will be collecting will need to be displayed on maps. We need to decide what graphs will be useful
(or look useful) and attempt to build them. For now, we may use fake data to verify the functionality of the maps.

The preferred method for creating these maps is to use Plotly. The reason is the integration with dash is fairly 
seamless. Additionally, Plotly has several of the maps built in. 

This task is complex and has many parts. Please dig in and see what we can do with the maps available in the resources 
link. 

#### Requirements

| RID | Name | Description |
| --- | ---- | --- |
| 00 | Examples of useful maps | gradient maps, map of nodes as points, etc |
| 01 | Simple to create | each type of map should be created using a function in the maps module taking the required data as arguments |
| 03 | stretch goal - increased interactivity | look into clickable points for nodes or other data that may be displayed when hovering over an area or point |
| 04 | stretch goal - animated maps | animate the changes over time - like a weather map [see ecample - second map](https://plotly.com/python/bubble-maps/) |
| 05 | stretch goal - one click change map view | [see second map for example - polotical candidate analysis](https://plotly.com/python/mapbox-county-choropleth/)

#### Resources

- [Plotly Documentation](https://plotly.com/python/maps/)
- [Map Module](source/website/map.py)

## Graphs
### Web 

Graphs are another way we may display the data to users. Plotly has an extensive library of graphs. 

The objective of this investigation is two parts.

- Look through the available graphs and determine which graphs may be good for displaying the data we collect
- Create a function to create each type of graph and demonstrate the result with example data

#### Resources
- [Plotly Overview](https://plotly.com/python/)

## Database
### Backend

This task is mainly creating queries for specific cases within the database. 

An example would be to get the temperature values for all nodes in an area between a start and end date. 

We are using a document based database called TinyDB. The specific queries will be developed over the course of the 
project as required. 

#### Resources
- [TinyDB Documentation](https://tinydb.readthedocs.io/en/latest/)
- [Dictionaries in Python](https://www.w3schools.com/python/python_dictionaries.asp)
- [List of Dictionaries in Python](https://pythonexamples.org/python-list-of-dictionaries/)

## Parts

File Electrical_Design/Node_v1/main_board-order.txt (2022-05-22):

Order list for C:/Code_Projects/Remote-Area-Monitoring/Electrical_Design/Node_v1/main_board.sch
Exported from EAGLE with DesignLink

Quantity	Value	Package	Order code	Manufacturer	Manuf. Code	Availability	Price (from)	Description
2	4.7uF	C1206	03AC2666	MURATA	GRM188R61E475KE11D	360000	0.057	MURATA - GRM188R61E475KE11D - CAP, 4.7µF, 25V, 10%, X5R, 0603
2	10uF	C1206	65AH7093	MURATA	GRM188C80G106ME47D	4000	0.03	MURATA - GRM188C80G106ME47D - CAP, 10UF, 4VDC, MLCC, 0603 ROHS COMPLIANT: YES
4	0.1uF	C1206	92AH4371	KEMET	C0805C104M5RACAUTO	56000	0.022	KEMET - C0805C104M5RACAUTO - CAP, AEC-Q200, 0.1UF, 50V, MLCC, 0805 ROHS COMPLIANT: YES
1	0.1uF	R0402	92AH4371	KEMET	C0805C104M5RACAUTO	56000	0.022	KEMET - C0805C104M5RACAUTO - CAP, AEC-Q200, 0.1UF, 50V, MLCC, 0805 ROHS COMPLIANT: YES
1	0.22uF	C1206	71AH3221	TDK	C1005X7R1V224K050BE	19970	0.065	TDK - C1005X7R1V224K050BE - CAP, 0.22UF, 35V, MLCC, 0402 ROHS COMPLIANT: YES
2	T489A106K010ATA2K2	T489A	82AH9186	KEMET	T489A106K010ATA2K2	0	0.531	KEMET - T489A106K010ATA2K2 - CAP, 10UF, 10V, TANT, CASE A ROHS COMPLIANT: YES
1	TP4056	SOP-8	unknown					
1	REG1117	SOT223	unknown		REG1117			
1	DS18B20U+	SOP65P490X110-8N	73Y1392	MAXIM INTEGRATED / ANALOG DEVICES	DS18B20U+T&R	0	3.02	MAXIM INTEGRATED / ANALOG DEVICES - DS18B20U+T&R - Temperature Sensor IC, Digital, &#177; 0.5&#176;C, -55 &#176;C, 125 &#176;C, &#181;SOP, 8 Pins
2		1X02	unknown					
1		1X08	23AK8353	L-COM	PP5P-08BSS-155N	0	229.68	L-COM - PP5P-08BSS-155N - PASSIVE PLC FIELD UNIT PLC SPLITTER, 1X08 STANDARD
2		1X03	06AC4491	APEM	1X03	0	0.576	APEM - 1X03 - MEC SWITCH 10G ROHS COMPLIANT: YES
1		1X06	06AC4492	APEM	1X06	0	0.576	APEM - 1X06 - MEC SWITCH 10G ROHS COMPLIANT: YES
1		1X07	unknown					
2		1X05	unknown					
1	B82462G4472M	B82462G4472M	92AH4102	EPCOS	B82462G4472M000	4500	1.05	EPCOS - B82462G4472M000 - INDUCTOR, 4.7UH, SHIELDED, 2A ROHS COMPLIANT: YES
1	GREEN	CHIPLED_1206	40K0121	BROADCOM	HSMG-C170	3393	0.237	BROADCOM - HSMG-C170 - LED, Green, SMD, 1.25mm x 1.4mm, 20 mA, 2.2 V, 572 nm
1	RED	CHIPLED_1206	96Y9625	ROHM	SML-S13RTT86	1500	0.28	ROHM - SML-S13RTT86 - LED, INFRARED, 850NM, SMD, 1206
1	976k	R1206	24W2533	VISHAY	CRCW0402976KFKED	20000	0.005	VISHAY - CRCW0402976KFKED - Surface Mount Thick Film Resistor, AEC-Q200 CRCW Series, 976 kohm, 63 mW, - 1%, 50 V RoHS Compliant: Yes
1	309k	R1206	85Y6391	PANASONIC	ERJPA3F3093V	78	0.085	PANASONIC - ERJPA3F3093V - RES, 309K, 1%, THICK FILM
1	1M	R1206	47AC0009	MULTICOMP PRO	MCHVR02JTEY1004	20000	0.006	MULTICOMP PRO - MCHVR02JTEY1004 - RES, 1M, 5%, 0.063W, 0402, THICK FILM
3	1k	R1206	96Y9448	VISHAY	MCT06030D1001BP500	3227	0.19	VISHAY - MCT06030D1001BP500 - RES, 1K, 0.1%, 0.1W, 0603, THIN FILM
1	1.2k	R1206	82AH8972	YAGEO	RT0603DRE071K2L	5000	0.02	YAGEO - RT0603DRE071K2L - RES, 1K2, 0.5%, 0.1W, 0603, THIN FILM ROHS COMPLIANT: YES
1	100	R1206	76AH6132	DIODES INC.	ZSR1000GTA	999	0.84	DIODES INC. - ZSR1000GTA - VOLT REG, FIXED, 10V, 0.2A, 125DEG C ROHS COMPLIANT: YES
7	10k	R1206	82AH8869	YAGEO	RT0603BRB0710KL	3713	0.207	YAGEO - RT0603BRB0710KL - RES, 10K, 0.1%, 0.1W, 0603, THIN FILM ROHS COMPLIANT: YES
1	0.1R ±1%(PT2512FK-070R1L)	R2512	82AH7716	YAGEO	PT2512FK-070R1L	0	0.173	YAGEO - PT2512FK-070R1L - RES, AEC-Q200, 0R1, 1%, 1W, 2512 ROHS COMPLIANT: YES
7	4.7k	R1206	54AH6417	MULTICOMP PRO	MP000527	9090	0.01	MULTICOMP PRO - MP000527 - RES, 4K7, 1%, 0.1W, 0402, THICK FILM
2	222AMVAAR	222AMVAAR	unknown					
30	TPPAD1-13	P1-13	unknown					
1	DW01A	SOT23-6	unknown					
1	FS8205A	TSSOP8	unknown					
1	MCP1642B	MCP1642B	29Y7746	MICROCHIP	MCP1642B-ADJI/MS	47	1.02	MICROCHIP - MCP1642B-ADJI/MS - DC-DC Switching Synchronous Boost Regulator, Adjustable, 0.65 V-5.5 V in, 1.8-5.5 V/0.8 A out, MSOP
1	SPARKFUN_HMC5883LSMD	SPARKFUN_16LPCC	unknown					
1		SOT23-8	81Y9547	MAXIM INTEGRATED / ANALOG DEVICES	MAX6369KA+T	180	2.78	MAXIM INTEGRATED / ANALOG DEVICES - MAX6369KA+T - Watchdog Timer, Open Drain, 2.5 V to 5.5 V Supply, 100ms Pulse Width, 1ms to 60s Delay, SOT23-8
1	ESP-WROOM-32	ESP-WROOM-32	unknown					
1	BME280	BME280_LGA	77Y5291	ADAFRUIT	2652	0	14.95	ADAFRUIT - 2652 - Adafruit BME280 I2C or SPI Temperature Humidity Pressure Sensor - STEMMA QT
1	CCS811	LGA10	48AC8695	ADAFRUIT	3566	0	19.95	ADAFRUIT - 3566 - Adafruit CCS811 Air Quality Sensor Breakout - VOC and eCO2 - STEMMA QT / Qwiic

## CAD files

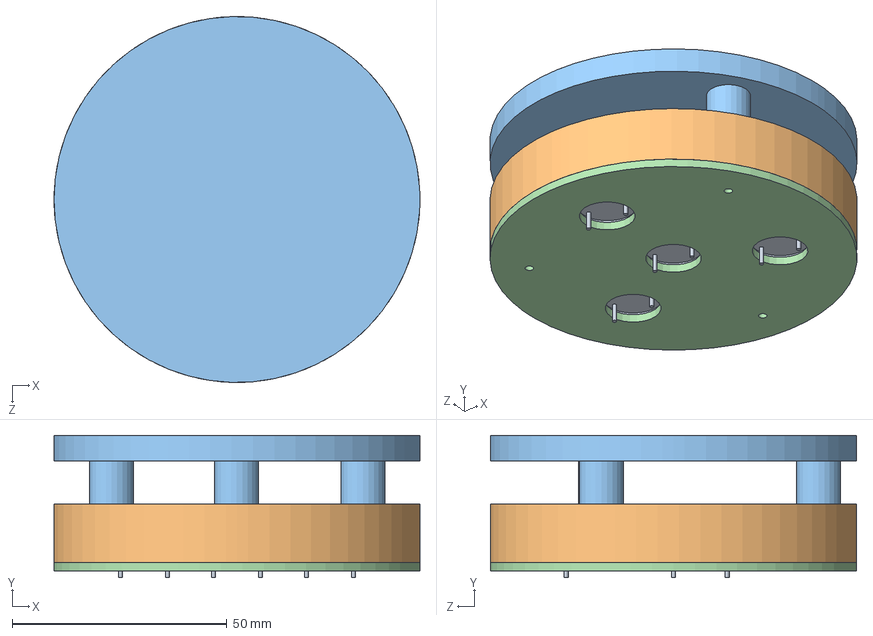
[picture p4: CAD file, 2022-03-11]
3D_Models/Prototype/ultrasonic_anemometer.SLDASM
85.2 x 33.1 x 85.2 mm
ultrasonic_sensor_standalone x 4
ua_body^ultrasonic_anemometer
ua_reflector^ultrasonic_anemometer
ua_lid^ultrasonic_anemometer

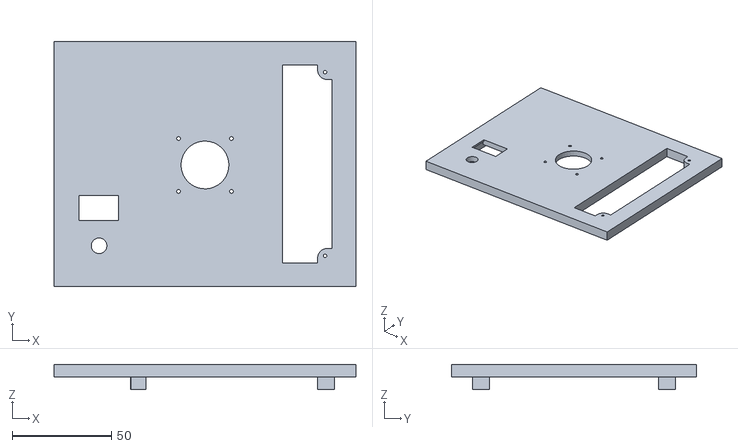
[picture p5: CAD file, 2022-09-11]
3D_Models/Final_Design/main_box_bottom.STL
152.5 x 123.7 x 12.7

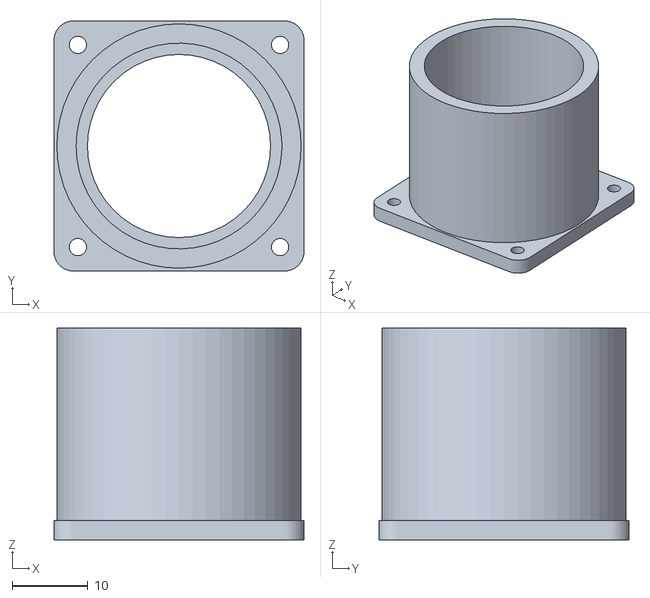
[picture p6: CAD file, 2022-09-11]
3D_Models/Final_Design/pipe mount.STL
33.0 x 33.0 x 27.9

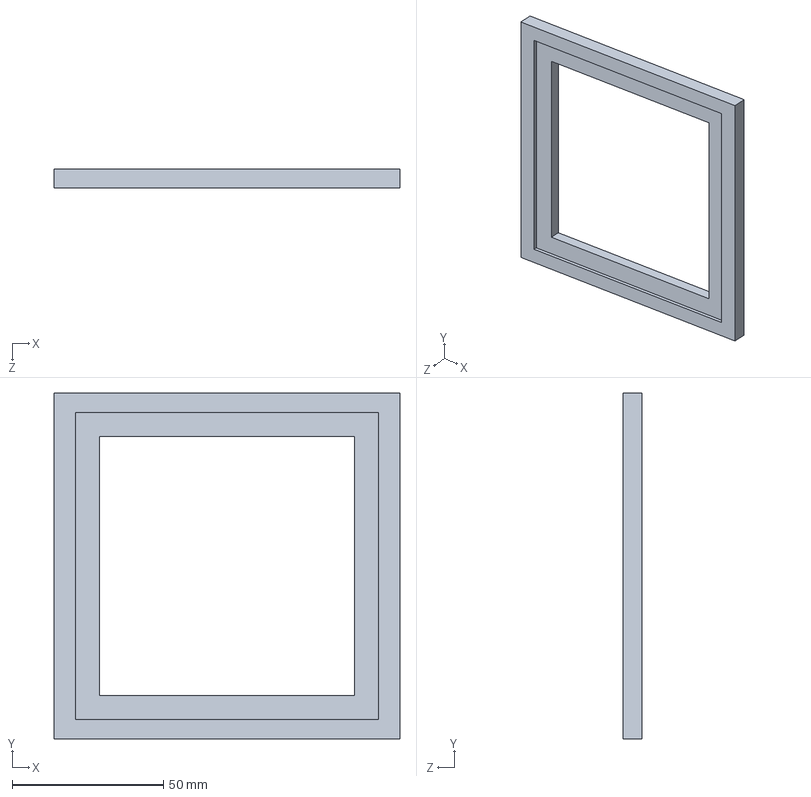
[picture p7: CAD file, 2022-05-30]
3D_Models/tooling/solder_paste_frame.SLDPRT
114.3 x 114.3 x 6.35 mm

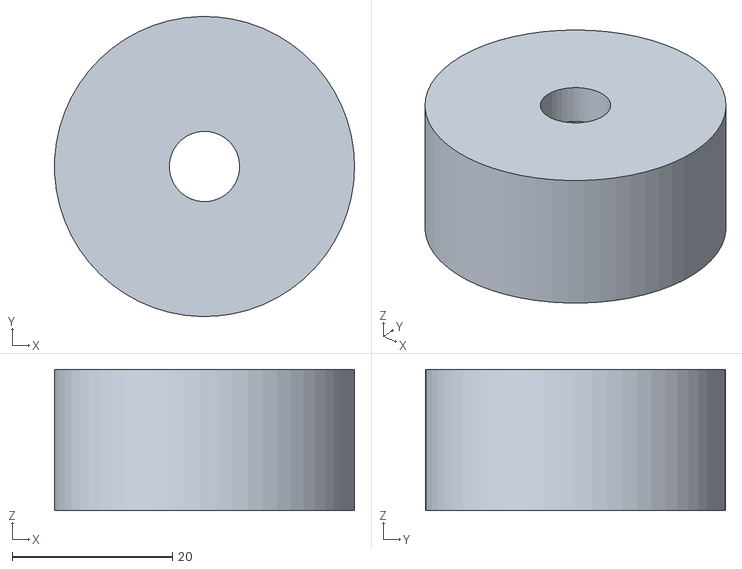
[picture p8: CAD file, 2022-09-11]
3D_Models/Final_Design/berring_mount.STL
37.4 x 37.4 x 17.6

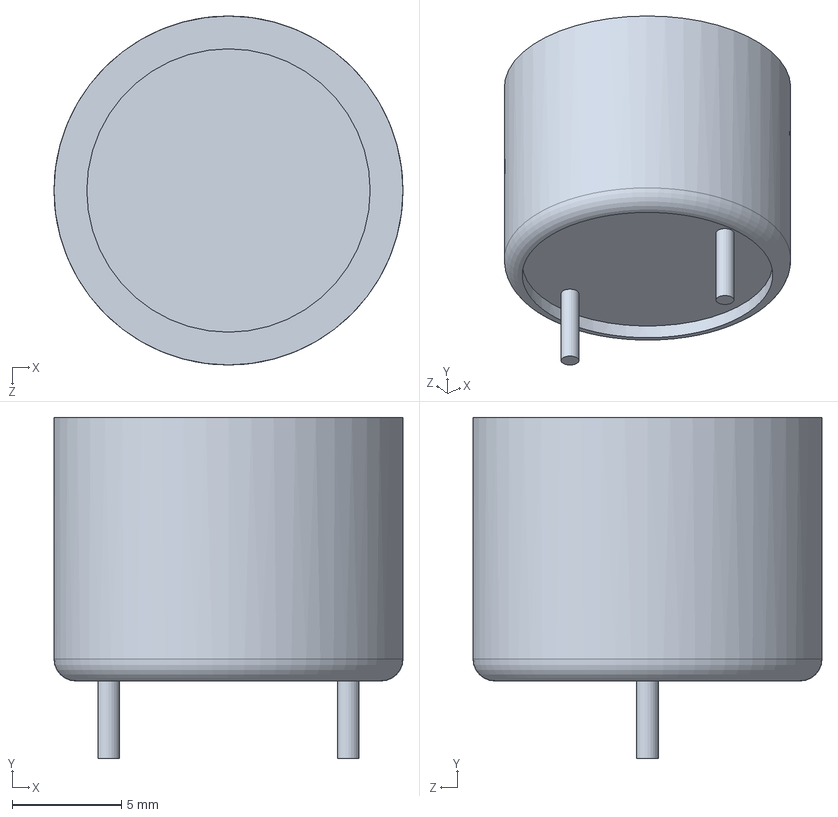
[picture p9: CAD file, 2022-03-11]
3D_Models/Prototype/ultrasonic_sensor_standalone.SLDPRT
15.9 x 15.6 x 15.9 mm

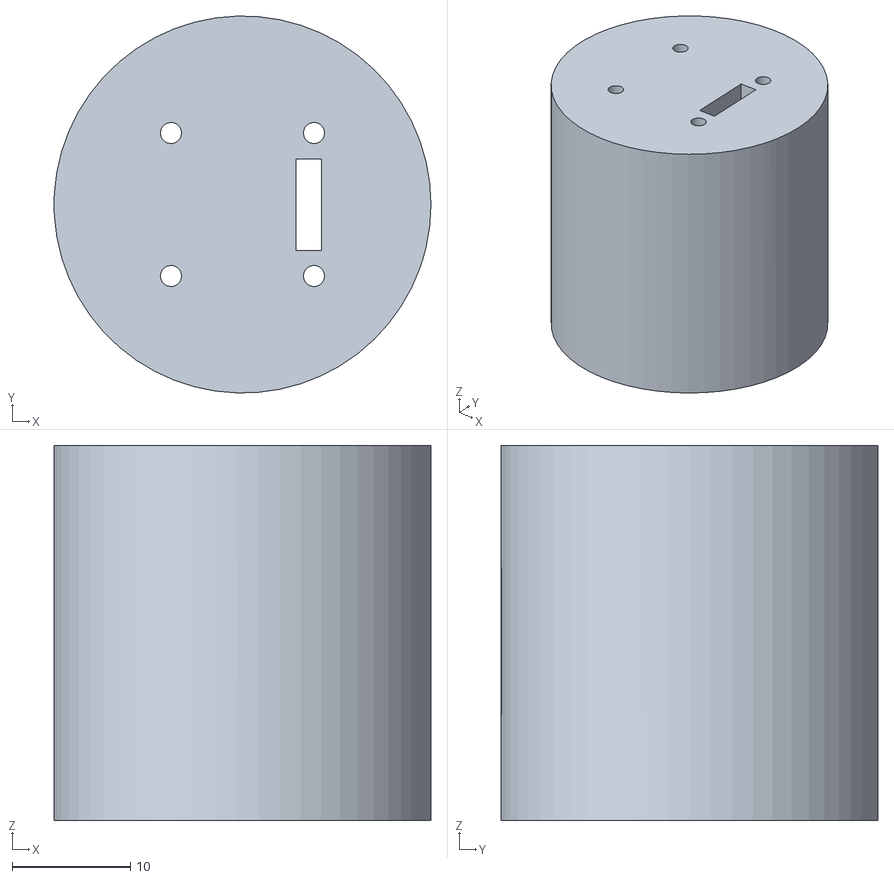
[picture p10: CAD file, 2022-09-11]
3D_Models/Final_Design/an_pole_mount.STL
31.9 x 31.9 x 31.8

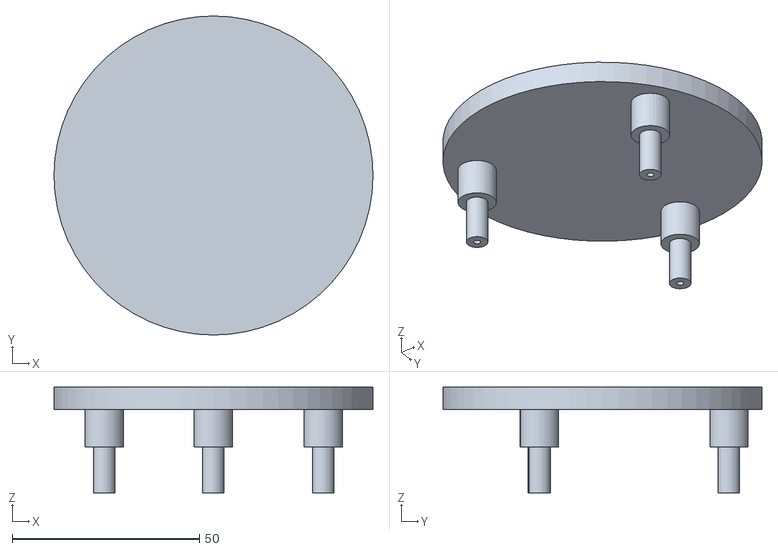
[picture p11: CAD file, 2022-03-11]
3D_Models/Prototype/ua_reflector^ultrasonic_anemometer.STL
85.2 x 85.2 x 28.2

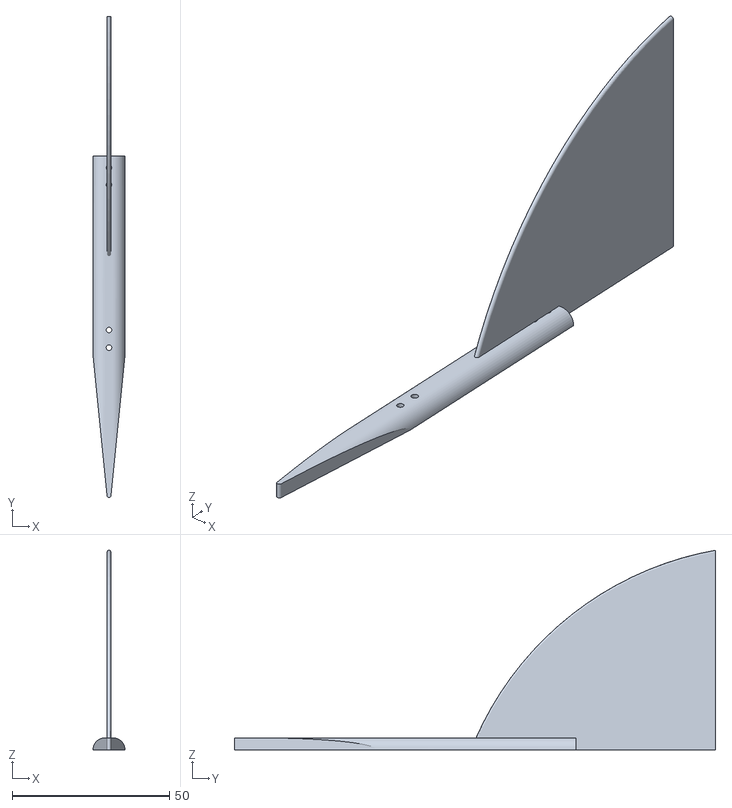
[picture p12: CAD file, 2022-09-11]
3D_Models/Final_Design/an_fin.STL
10.2 x 153.0 x 63.5

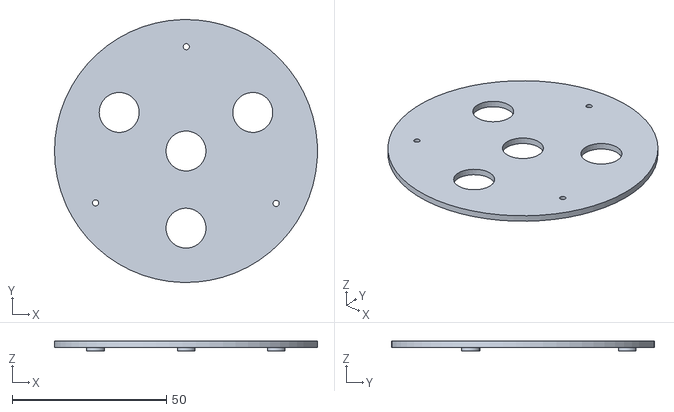
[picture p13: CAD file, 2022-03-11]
3D_Models/Prototype/ua_lid^ultrasonic_anemometer.STL
85.2 x 85.2 x 3.15

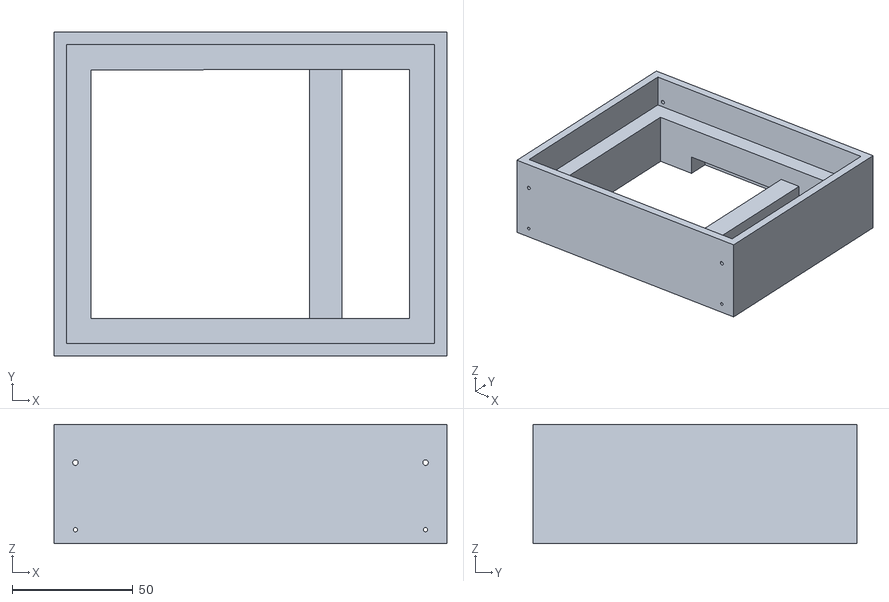
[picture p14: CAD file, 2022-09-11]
3D_Models/Final_Design/box insert.STL
162.9 x 134.1 x 49.3

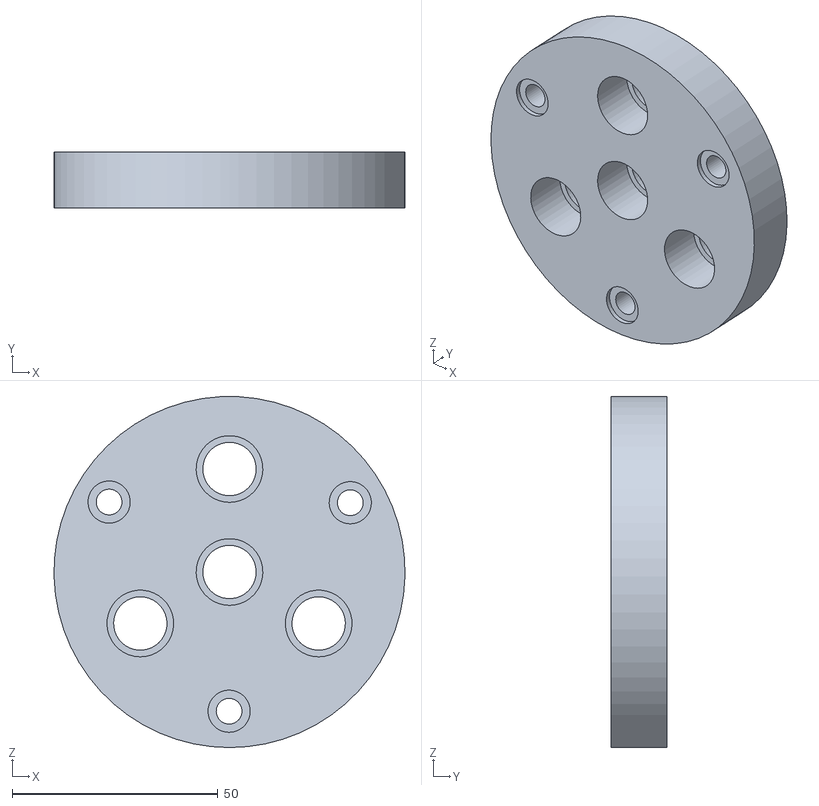
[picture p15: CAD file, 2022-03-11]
3D_Models/Prototype/ua_body^ultrasonic_anemometer.STL
85.2 x 13.6 x 85.2

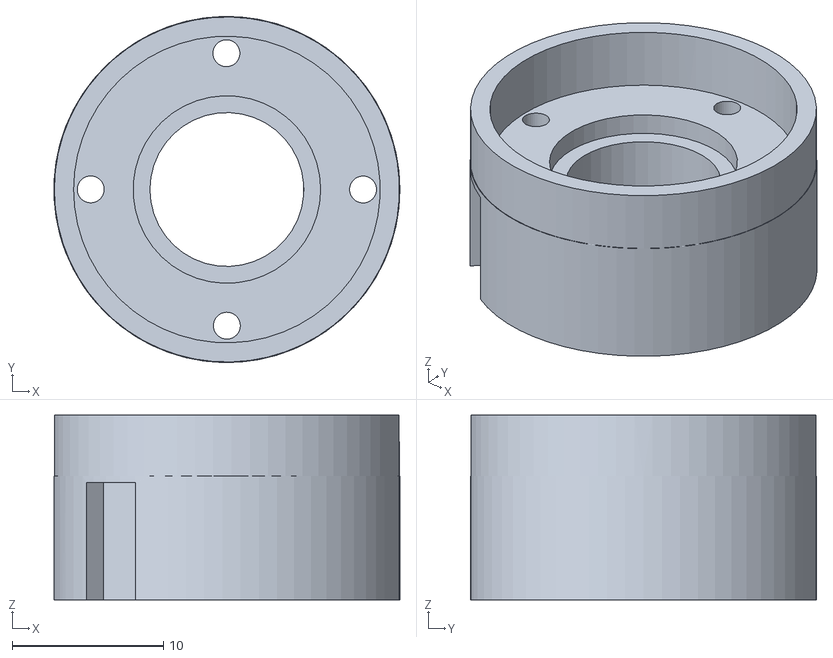
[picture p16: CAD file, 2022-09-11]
3D_Models/Final_Design/an_bearing_holder.STL
22.8 x 22.9 x 12.2

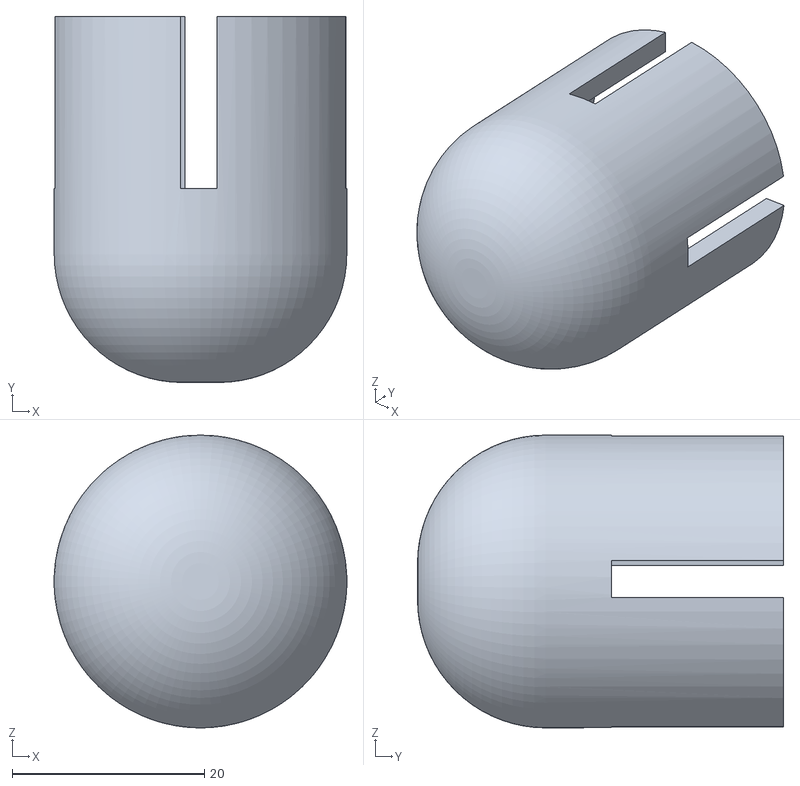
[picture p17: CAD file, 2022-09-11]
3D_Models/Final_Design/Part3^anemometer rev2.STL
30.5 x 38.1 x 30.5

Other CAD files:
3D_Models/Final_Design/box_bottom_a.STL
3D_Models/Final_Design/wind_fin_pipeMnt.STL
3D_Models/Final_Design/aggregator_bottom.STL
3D_Models/Final_Design/cap2mag.STL
3D_Models/Final_Design/Copy of Part1^anemometer rev2.STL
3D_Models/Final_Design/Copy of Part1^anemometer rev3.STL
3D_Models/Final_Design/Copy of Part1^anemometer rev4.STL
3D_Models/Final_Design/Part2^anemometer.STL
3D_Models/Final_Design/Part6^anemo rev3.STL
3D_Models/Final_Design/Part6^anemometer rev2.STL
3D_Models/Final_Design/Part6^anemometer rev3.STL
3D_Models/Final_Design/Part6^anemometer rev4.STL
3D_Models/Final_Design/Part6^anemometer.STL
3D_Models/Final_Design/Top_box.STL
3D_Models/Final_Design/aggregator_top.STL
3D_Models/Final_Design/an_cap.STL
3D_Models/Final_Design/an_cup.STL
3D_Models/Final_Design/an_fin_mount.STL
3D_Models/Final_Design/an_hub.STL
3D_Models/Final_Design/an_sensor_holder.STL
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

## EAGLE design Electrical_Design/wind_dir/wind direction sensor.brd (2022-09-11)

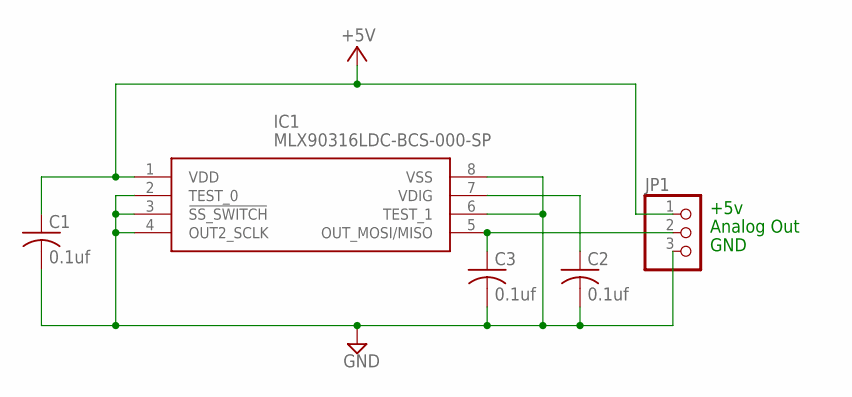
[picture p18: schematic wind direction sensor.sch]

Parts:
C1, C2, C3: 0.1uf; C1206K
IC1: MLX90316LDC-BCS-000-SP; SOIC127P600X172-8N
JP1: PINHD-1X3; 1X03

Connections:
+5V: C1.1, IC1.1 (VDD), JP1.1
GND: C1.2, C2.2, C3.2, IC1.2 (TEST_0), IC1.3 (!SS_SWITCH), IC1.4 (OUT2_SCLK), IC1.6 (TEST_1), IC1.8 (VSS), JP1.3
unnamed: C3.1, IC1.5 (OUT_MOSI/MISO), JP1.2
unnamed: C2.1, IC1.7 (VDIG)

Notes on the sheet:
Analog Out
+5v
GND

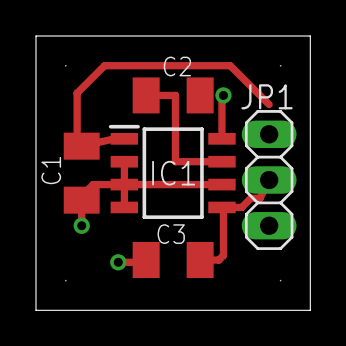
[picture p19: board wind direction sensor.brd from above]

Board: 2 copper layers, 15.2 x 15.2 mm, 5 parts (0 on the bottom side), 4 nets.

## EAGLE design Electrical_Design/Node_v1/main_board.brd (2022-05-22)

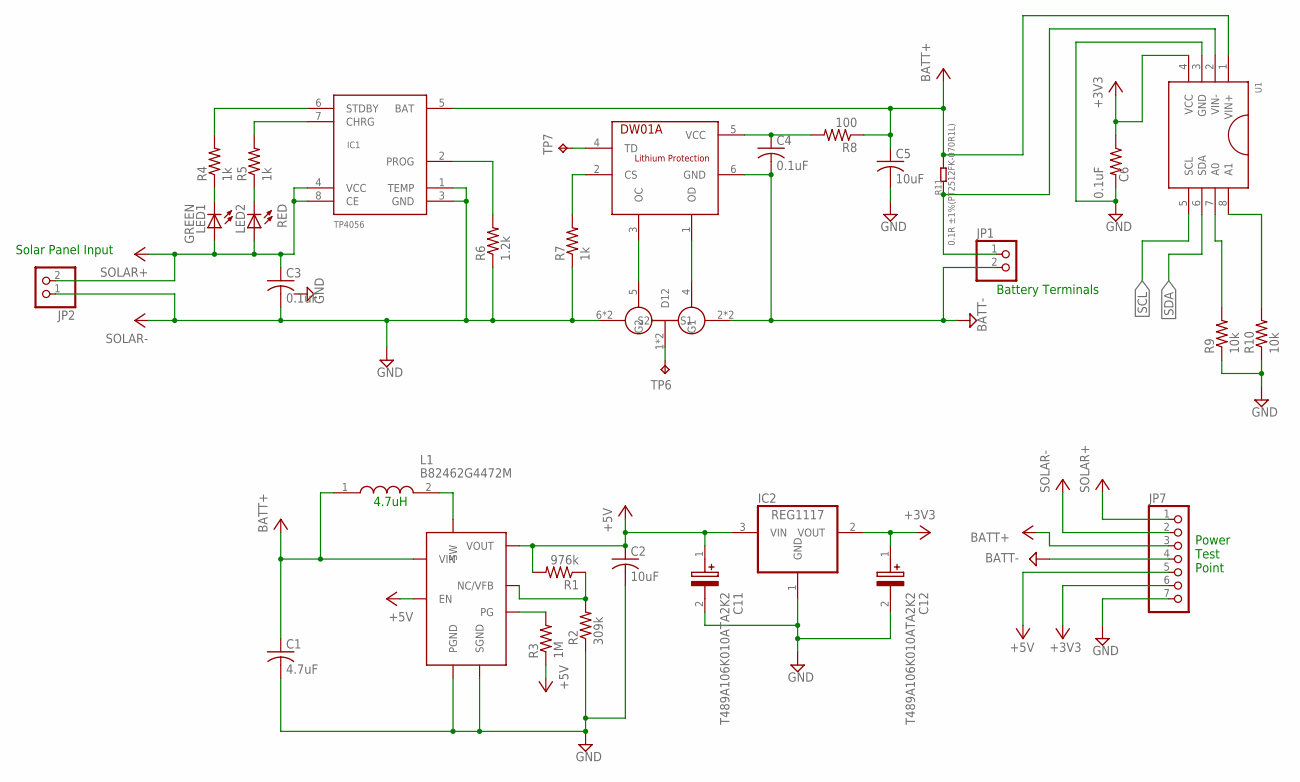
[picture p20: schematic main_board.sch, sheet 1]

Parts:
C1: 4.7uF; C1206; MPN GRM188R61E475KE11D
C2, C5: 10uF; C1206; MPN GRM188C80G106ME47D
C3, C4: 0.1uF; C1206; MPN C0805C104M5RACAUTO
C6: 0.1uF; R0402; MPN C0805C104M5RACAUTO
C11, C12: T489A106K010ATA2K2; T489A; MPN T489A106K010ATA2K2
IC1: TP4056; SOP-8
IC2: REG1117; SOT223
JP1, JP2: PINHD-1X2; 1X02
JP7: PINHD-1X7; 1X07
L1: B82462G4472M; MPN B82462G4472M000
LED1: GREEN; CHIPLED_1206; MPN HSMG-C170
LED2: RED; CHIPLED_1206; MPN SML-S13RTT86
R1: 976k; R1206; MPN CRCW0402976KFKED
R2: 309k; R1206; MPN ERJPA3F3093V
R3: 1M; R1206; MPN MCHVR02JTEY1004
R4, R5, R7: 1k; R1206; MPN MCT06030D1001BP500
R6: 1.2k; R1206; MPN RT0603DRE071K2L
R8: 100; R1206; MPN ZSR1000GTA
R9, R10: 10k; R1206; MPN RT0603BRB0710KL
R11: 0.1R ±1%(PT2512FK-070R1L); R2512; MPN PT2512FK-070R1L
TP6, TP7: TPPAD1-13; P1-13
U1: INA219; SOT23-8; MPN MAX6369KA+T
U$1: DW01A; SOT23-6
U$2: FS8205A; TSSOP8
U$3: MCP1642B; MPN MCP1642B-ADJI/MS

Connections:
+3V3: C6.1, C12.1 (+), IC2.2 (VOUT), JP7.6, U1.4 (VCC); also elsewhere on the board
+5V: C2.1, C11.1 (+), IC2.3 (VIN), JP7.5, R1.2, R3.1, U$3.EN, U$3.VOUT; also elsewhere on the board
BATT+: C1.1, C5.1, IC1.5 (BAT), JP7.3, L1.1, R8.1, R11.2, U1.1 (VIN+), U$3.VIN
BATT-: C4.2, JP1.2, JP7.4, U$1.6 (GND), U$2.2 (S1), U$2.3 (S1)
GND: C1.2, C2.2, C3.2, C5.2, C6.2, C11.2 (-), C12.2 (-), IC1.1 (TEMP), IC1.3 (GND), IC2.1 (GND), JP2.1, JP7.7, R2.1, R6.1, R7.1, R9.1, R10.1, U1.3 (GND), U$2.6 (S2), U$2.7 (S2), U$3.PGND, U$3.SGND; also elsewhere on the board
unnamed: R1.1, R2.2, U$3.NC (NC/VFB)
unnamed: R3.2, U$3.PG
unnamed: L1.2, U$3.SW
unnamed: IC1.6 (STDBY), R4.2
unnamed: IC1.7 (CHRG), R5.2
unnamed: LED2.C, R5.1
unnamed: LED1.C, R4.1
unnamed: U$1.3 (OC), U$2.5 (G2)
unnamed: U$1.1 (OD), U$2.4 (G1)
unnamed: IC1.2 (PROG), R6.2
unnamed: R7.2, U$1.2 (CS)
unnamed: C4.1, R8.2, U$1.5 (VCC)
unnamed: JP1.1, R11.1, U1.2 (VIN-)
unnamed: TP7.TP, U$1.4 (TD)
unnamed: TP6.TP, U$2.1 (D12), U$2.8 (D12)
unnamed: R9.2, U1.7 (A0)
unnamed: R10.2, U1.8 (A1)
SCL: U1.5 (SCL); also elsewhere on the board
SDA: U1.6 (SDA); also elsewhere on the board
SOLAR+: C3.1, IC1.4 (VCC), IC1.8 (CE), JP2.2, JP7.1, LED1.A, LED2.A
SOLAR-: JP7.2

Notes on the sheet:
4.7uH
Solar Panel Input
Battery Terminals
Power Test Point

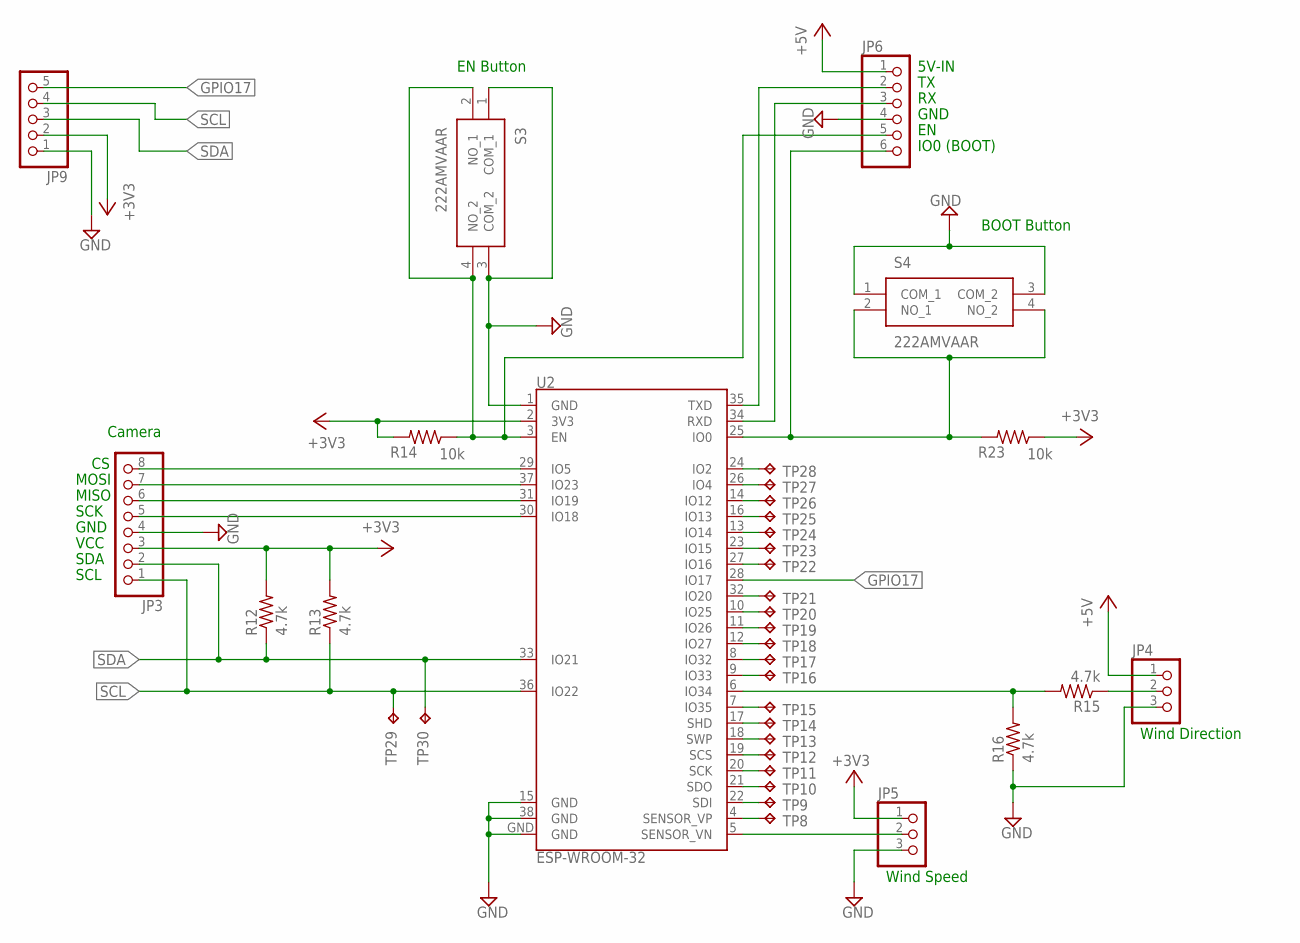
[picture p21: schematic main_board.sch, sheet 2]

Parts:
JP3: PINHD-1X8; 1X08; MPN PP5P-08BSS-155N
JP4, JP5: PINHD-1X3; 1X03; MPN 1X03
JP6: PINHD-1X6; 1X06; MPN 1X06
JP9: PINHD-1X5; 1X05
R12, R13, R15, R16: 4.7k; R1206; MPN MP000527
R14, R23: 10k; R1206; MPN RT0603BRB0710KL
S3, S4: 222AMVAAR
TP8, TP9, TP10, TP11, TP12, TP13, TP14, TP15, TP16, TP17, TP18, TP19, TP20, TP21, TP22, TP23, TP24, TP25, TP26, TP27, TP28, TP29, TP30: TPPAD1-13; P1-13
U2: ESP-WROOM-32

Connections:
+3V3: JP3.3, JP5.1, JP9.2, R12.2, R13.2, R14.2, R23.1, U2.2 (3V3); also elsewhere on the board
+5V: JP4.1, JP6.1; also elsewhere on the board
GND: JP3.4, JP4.3, JP5.3, JP6.4, JP9.1, R16.1, S3.1 (COM_1), S3.3 (COM_2), S4.1 (COM_1), S4.3 (COM_2), U2.1 (GND), U2.15 (GND), U2.38 (GND), U2.GND; also elsewhere on the board
GPIO17: JP9.5, U2.28 (IO17); also elsewhere on the board
unnamed: JP3.8, U2.29 (IO5)
unnamed: JP3.7, U2.37 (IO23)
unnamed: JP3.6, U2.31 (IO19)
unnamed: JP3.5, U2.30 (IO18)
unnamed: JP6.5, R14.1, S3.2 (NO_1), S3.4 (NO_2), U2.3 (EN)
unnamed: JP6.2, U2.35 (TXD)
unnamed: JP6.3, U2.34 (RXD)
unnamed: JP5.2, U2.5 (SENSOR_VN)
unnamed: JP6.6, R23.2, S4.2 (NO_1), S4.4 (NO_2), U2.25 (IO0)
unnamed: JP4.2, R15.1
unnamed: R15.2, R16.2, U2.6 (IO34)
unnamed: TP28.TP, U2.24 (IO2)
unnamed: TP27.TP, U2.26 (IO4)
unnamed: TP26.TP, U2.14 (IO12)
unnamed: TP25.TP, U2.16 (IO13)
unnamed: TP24.TP, U2.13 (IO14)
unnamed: TP23.TP, U2.23 (IO15)
unnamed: TP22.TP, U2.27 (IO16)
unnamed: TP21.TP, U2.32 (IO20)
unnamed: TP20.TP, U2.10 (IO25)
unnamed: TP19.TP, U2.11 (IO26)
unnamed: TP18.TP, U2.12 (IO27)
unnamed: TP17.TP, U2.8 (IO32)
unnamed: TP16.TP, U2.9 (IO33)
unnamed: TP15.TP, U2.7 (IO35)
unnamed: TP14.TP, U2.17 (SHD)
unnamed: TP13.TP, U2.18 (SWP)
unnamed: TP12.TP, U2.19 (SCS)
unnamed: TP11.TP, U2.20 (SCK)
unnamed: TP10.TP, U2.21 (SDO)
unnamed: TP9.TP, U2.22 (SDI)
unnamed: TP8.TP, U2.4 (SENSOR_VP)
SCL: JP3.1, JP9.4, R13.1, TP29.TP, U2.36 (IO22); also elsewhere on the board
SDA: JP3.2, JP9.3, R12.1, TP30.TP, U2.33 (IO21); also elsewhere on the board

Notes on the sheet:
Camera
MOSI
MISO
SCK
GND
VCC
SDA
SCL
5V-IN
IO0 (BOOT)
EN Button
BOOT Button
Wind Speed
Wind Direction

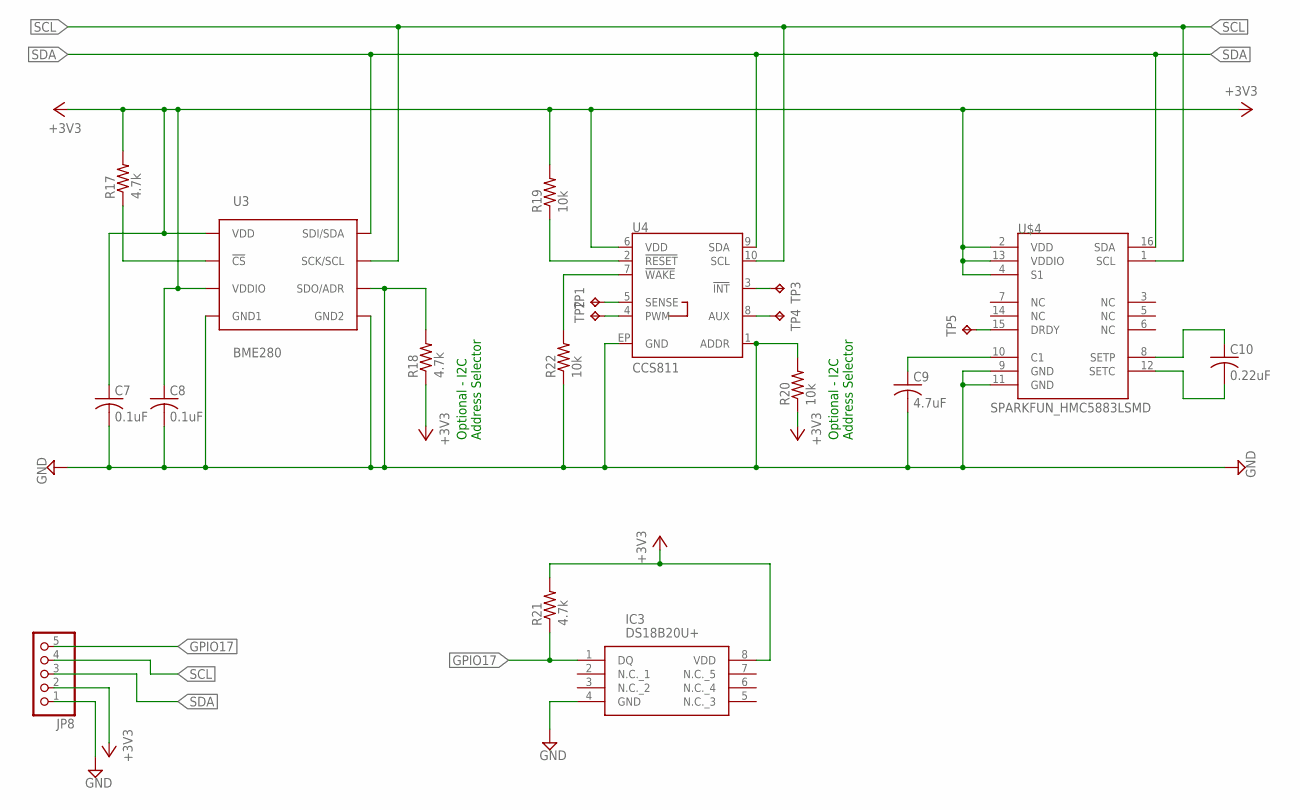
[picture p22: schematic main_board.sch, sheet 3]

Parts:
C7, C8: 0.1uF; C1206; MPN C0805C104M5RACAUTO
C9: 4.7uF; C1206; MPN GRM188R61E475KE11D
C10: 0.22uF; C1206; MPN C1005X7R1V224K050BE
IC3: DS18B20U+; SOP65P490X110-8N; MPN DS18B20U+T&R
JP8: PINHD-1X5; 1X05
R17, R18, R21: 4.7k; R1206; MPN MP000527
R19, R20, R22: 10k; R1206; MPN RT0603BRB0710KL
TP1, TP2, TP3, TP4, TP5: TPPAD1-13; P1-13
U3: BME280; BME280_LGA; MPN 2652
U4: CCS811; LGA10; MPN 3566
U$4: SPARKFUN_HMC5883LSMD; SPARKFUN_16LPCC

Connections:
+3V3: C7.1, C8.1, IC3.8 (VDD), JP8.2, R17.2, R18.1, R19.2, R20.1, R21.2, U3.P$6 (VDDIO), U3.P$8 (VDD), U4.6 (VDD), U$4.2 (VDD), U$4.4 (S1), U$4.13 (VDDIO); also elsewhere on the board
GND: C7.2, C8.2, C9.2, IC3.4 (GND), JP8.1, R18.2, R20.2, R22.1, U3.P$1 (GND1), U3.P$5 (SDO/ADR), U3.P$7 (GND2), U4.1 (ADDR), U4.EP (GND), U$4.9 (GND), U$4.11 (GND); also elsewhere on the board
GPIO17: IC3.1 (DQ), JP8.5, R21.1; also elsewhere on the board
unnamed: R17.1, U3.P$2 (!CS)
unnamed: R19.1, U4.2 (!RESET!)
unnamed: C10.1, U$4.8 (SETP)
unnamed: C10.2, U$4.12 (SETC)
unnamed: R22.2, U4.7 (!WAKE!)
unnamed: C9.1, U$4.10 (C1)
unnamed: TP1.TP, U4.5 (SENSE)
unnamed: TP2.TP, U4.4 (PWM)
unnamed: TP3.TP, U4.3 (!INT!)
unnamed: TP4.TP, U4.8 (AUX)
unnamed: TP5.TP, U$4.15 (DRDY)
SCL: JP8.4, U3.P$4 (SCK/SCL), U4.10 (SCL), U$4.1 (SCL); also elsewhere on the board
SDA: JP8.3, U3.P$3 (SDI/SDA), U4.9 (SDA), U$4.16 (SDA); also elsewhere on the board

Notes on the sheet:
Optional - I2C Address Selector

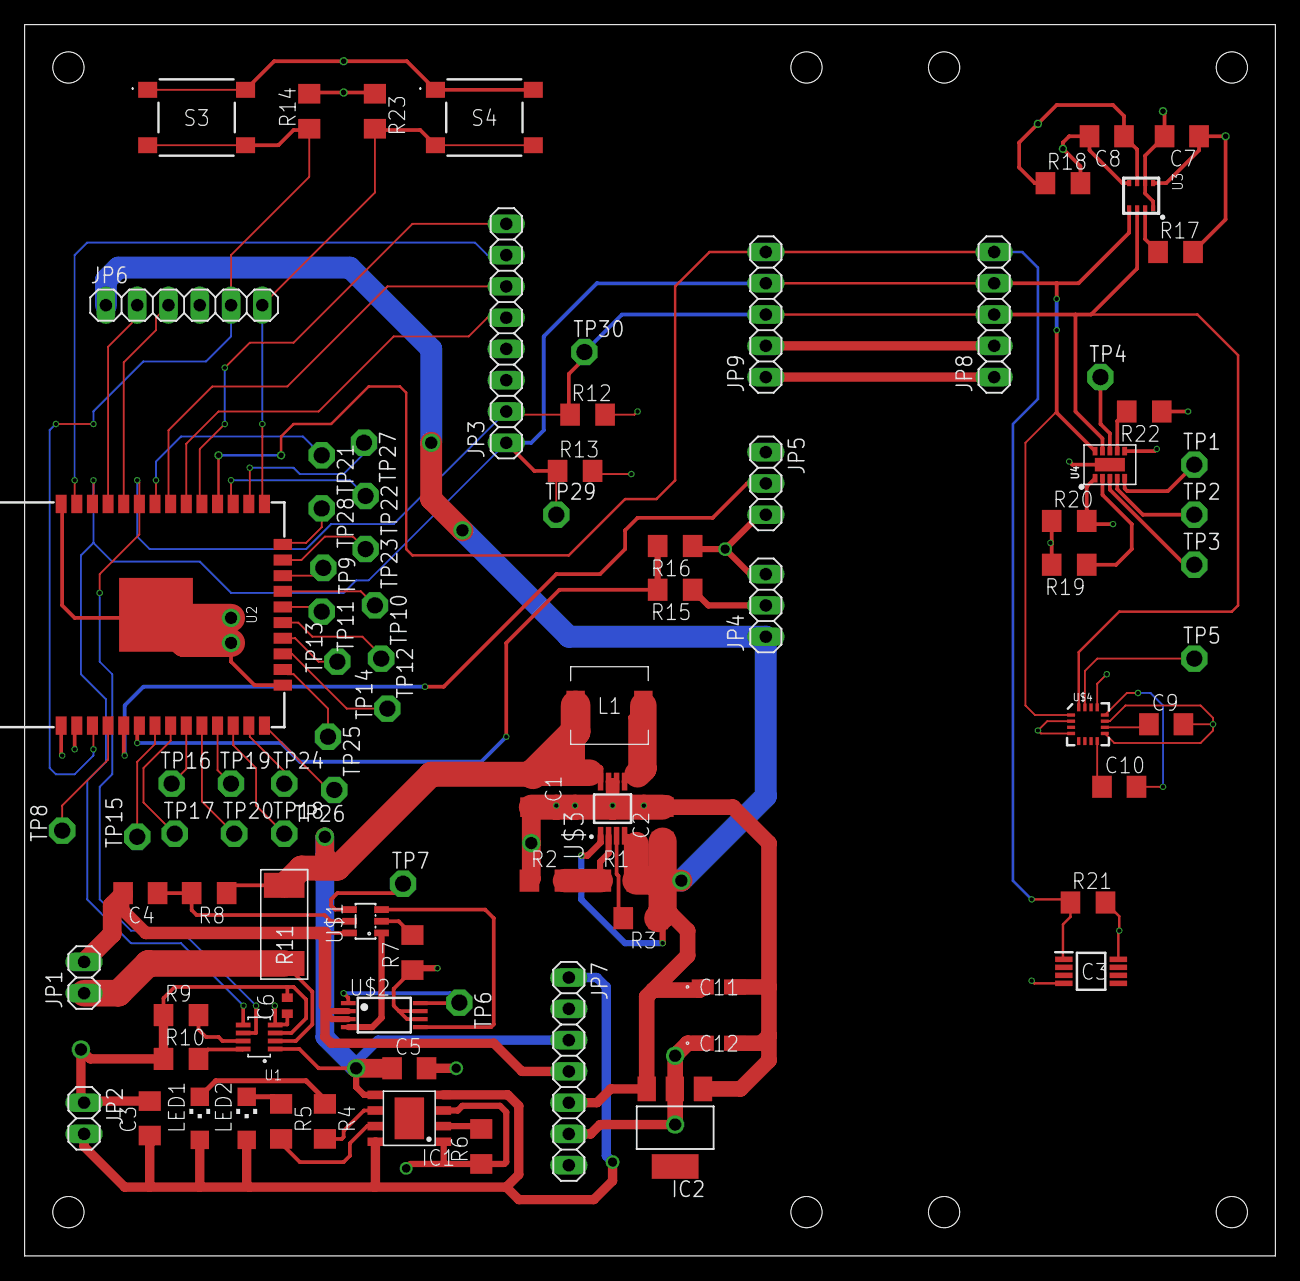
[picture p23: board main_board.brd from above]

Board: 2 copper layers, 101.6 x 100.0 mm, 90 parts (0 on the bottom side), 69 nets.

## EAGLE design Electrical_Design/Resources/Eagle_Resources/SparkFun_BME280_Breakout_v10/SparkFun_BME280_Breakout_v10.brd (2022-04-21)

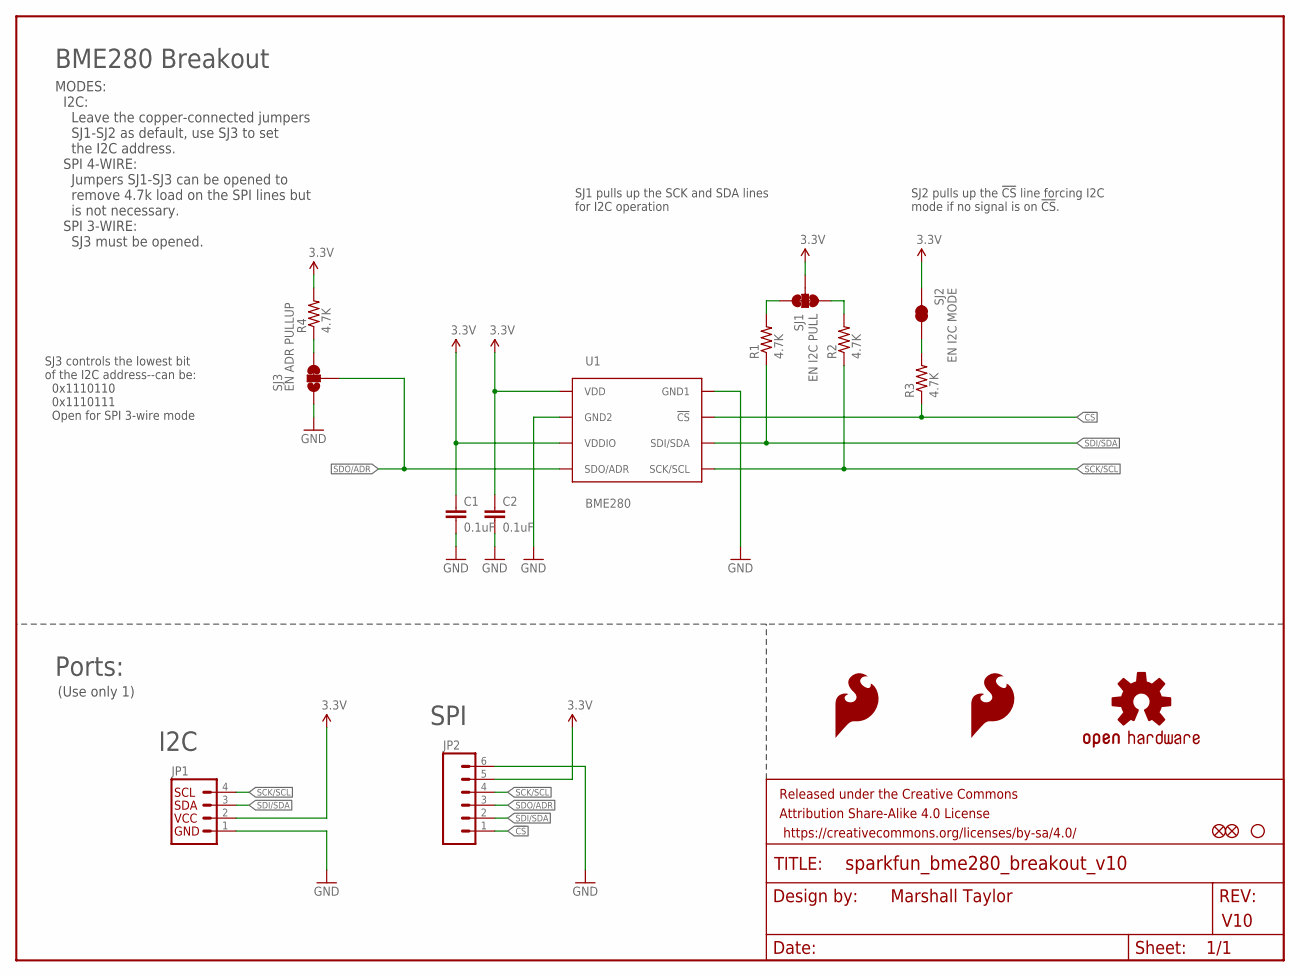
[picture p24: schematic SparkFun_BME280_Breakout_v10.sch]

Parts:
C1, C2: 0.1uF; 0603-CAP
FID1, FID2: FIDUCIAL1X2; FIDUCIAL-1X2
FRAME1: FRAME-LETTER; CREATIVE_COMMONS
JP1: I2C_STANDARD_NO_SILK; 1X04_NO_SILK
JP2: M06NO_SILK_FEMALE_PTH; 1X06_NO_SILK
LOGO1, LOGO2: SFE_LOGO_FLAME.1_INCH; SFE_LOGO_FLAME_.1
LOGO3: OSHW-LOGOS; OSHW-LOGO-S
R1, R2, R3, R4: 4.7K; 0603-RES
SJ1: EN I2C PULL; PAD-JUMPER-3-3OF3_NC_BY_TRACE_YES_SILK_FULL_BOX
SJ2: EN I2C MODE; PAD-JUMPER-2-NC_BY_TRACE_YES_SILK
SJ3: EN ADR PULLUP; PAD-JUMPER-3-2OF3_NC_BY_TRACE_YES_SILK_FULL_BOX
STANDOFF4: STAND-OFF
U1: BME280; BME280_LGA

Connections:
3.3V: C1.1, C2.1, JP1.2, JP2.5, R4.2, SJ1.2, SJ2.2, U1.P$6 (VDDIO), U1.P$8 (VDD)
!CS: JP2.1, R3.1, U1.P$2 (!CS)
GND: C1.2, C2.2, JP1.1, JP2.6, SJ3.1, U1.P$1 (GND1), U1.P$7 (GND2)
unnamed: R1.2, SJ1.3
unnamed: R2.2, SJ1.1
unnamed: R3.2, SJ2.1
unnamed: R4.1, SJ3.3
SCK/SCL: JP1.4, JP2.4, R2.1, U1.P$4 (SCK/SCL)
SDI/SDA: JP1.3, JP2.2, R1.1, U1.P$3 (SDI/SDA)
SDO/ADR: JP2.3, SJ3.2, U1.P$5 (SDO/ADR)

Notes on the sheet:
Marshall Taylor
V10
BME280 Breakout
SJ3 controls the lowest bit of the I2C address--can be: 0x1110110 0x1110111 Open for SPI 3-wire mode
SJ1 pulls up the SCK and SDA lines for I2C operation
Ports:
(Use only 1)
I2C
SPI
MODES: I2C: Leave the copper-connected jumpers SJ1-SJ2 as default, use SJ3 to set the I2C address. SPI 4-WIRE: Jumpers SJ1-SJ3 can be opened to remove 4.7k load on the SPI lines but is not necessary. SPI 3-WIRE: SJ3 must be opened.
SJ2 pulls up the !CS! line forcing I2C mode if no signal is on !CS!.

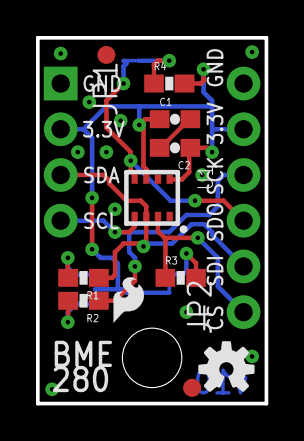
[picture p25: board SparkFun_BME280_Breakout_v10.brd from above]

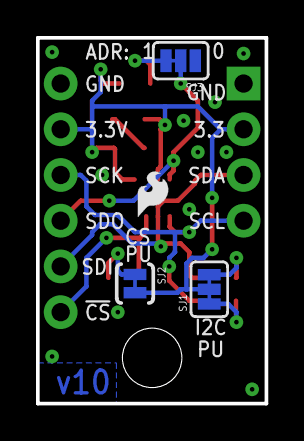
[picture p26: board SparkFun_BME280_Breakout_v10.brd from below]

Board: 2 copper layers, 12.7 x 20.3 mm, 19 parts (4 on the bottom side), 10 nets.

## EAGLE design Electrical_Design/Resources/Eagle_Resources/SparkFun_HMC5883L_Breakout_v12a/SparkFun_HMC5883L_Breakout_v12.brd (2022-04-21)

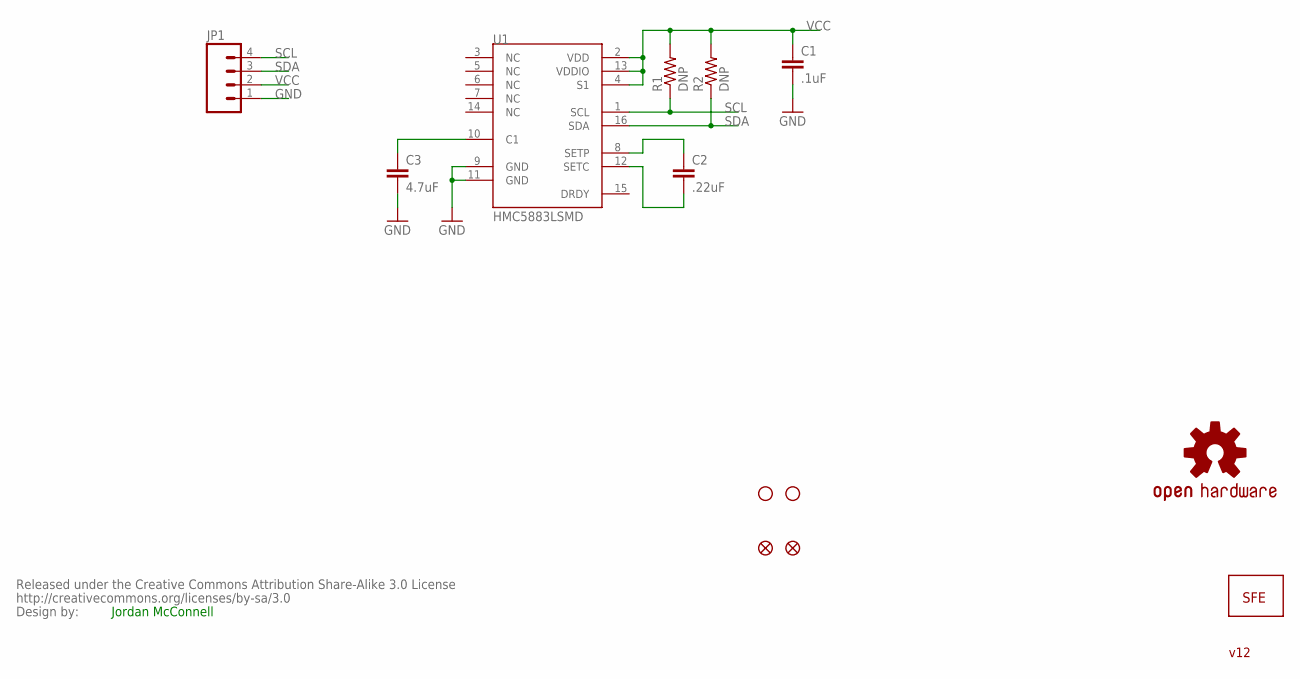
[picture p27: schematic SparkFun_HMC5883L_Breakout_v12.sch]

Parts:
C1: .1uF; 0402-CAP
C2: .22uF; 0402-CAP
C3: 4.7uF; 0402-CAP
JP1: M04PTH; 1X04
JP2, JP3: STAND-OFF
JP4: LOGO-SFESK; SFE-LOGO-FLAME
JP5, JP6: FIDUCIAL1X2.5; FIDUCIAL-1X2.5
R1, R2: DNP; 0402-RES
U1: HMC5883LSMD; 16LPCC
U$1: CREATIVE_COMMONS
U$2: OSHW-LOGOM; OSHW-LOGO-M

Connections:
GND: C1.2, C3.2, JP1.1, U1.9 (GND), U1.11 (GND)
unnamed: C3.1, U1.10 (C1)
unnamed: C2.1, U1.8 (SETP)
unnamed: C2.2, U1.12 (SETC)
SCL: JP1.4, R1.1, U1.1 (SCL)
SDA: JP1.3, R2.1, U1.16 (SDA)
VCC: C1.1, JP1.2, R1.2, R2.2, U1.2 (VDD), U1.4 (S1), U1.13 (VDDIO)

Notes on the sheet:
Jordan McConnell
v12

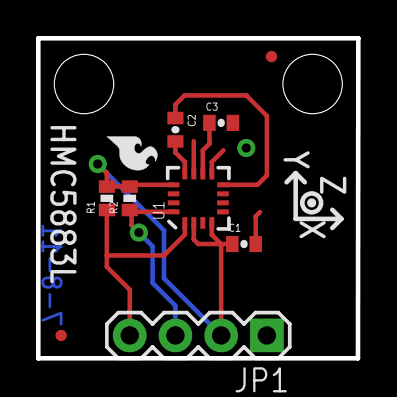
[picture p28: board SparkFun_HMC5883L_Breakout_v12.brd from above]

Board: 2 copper layers, 17.8 x 17.8 mm, 14 parts (1 on the bottom side), 7 nets.

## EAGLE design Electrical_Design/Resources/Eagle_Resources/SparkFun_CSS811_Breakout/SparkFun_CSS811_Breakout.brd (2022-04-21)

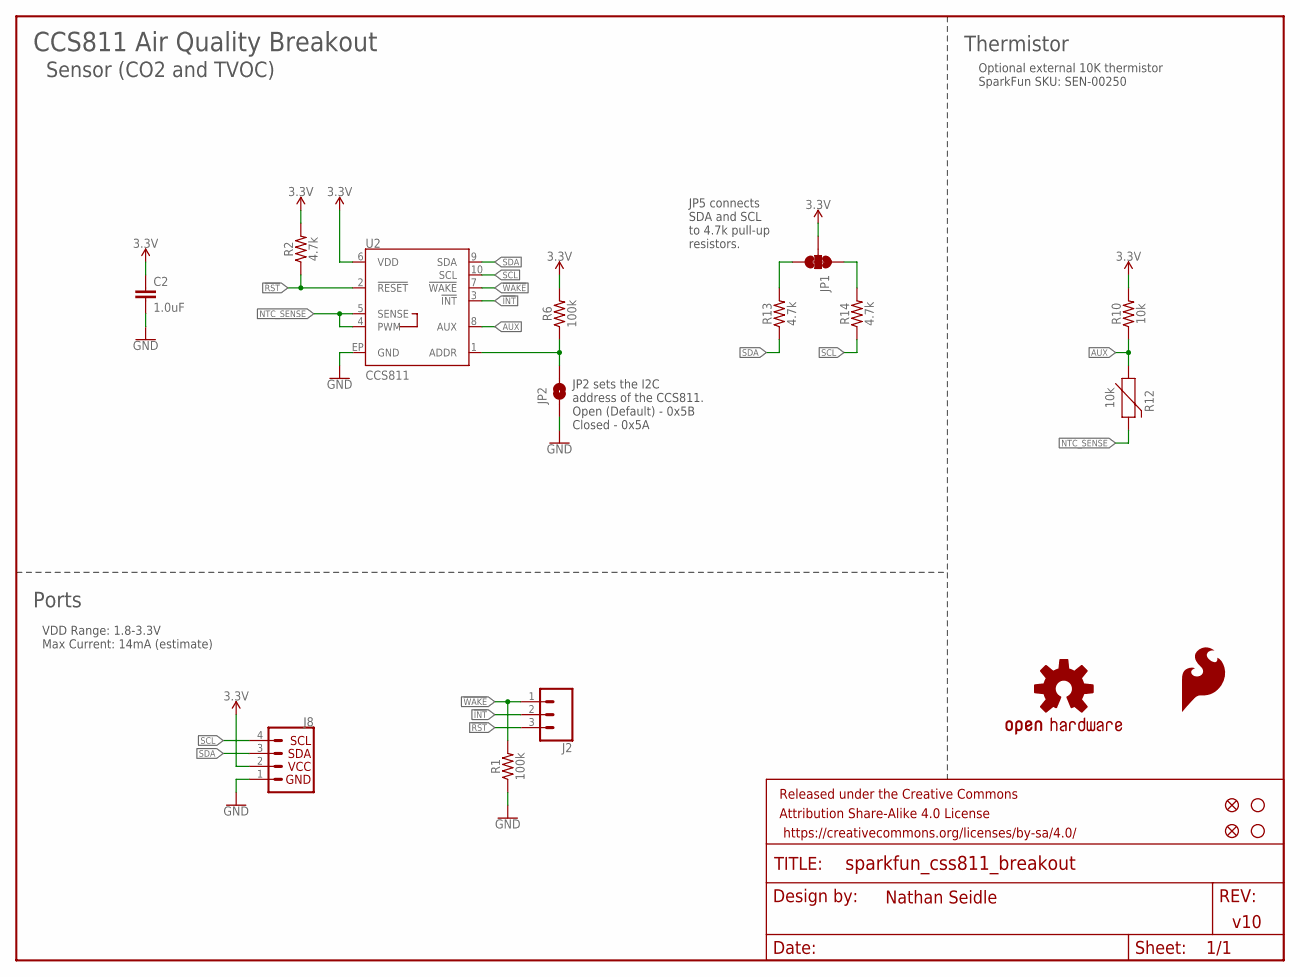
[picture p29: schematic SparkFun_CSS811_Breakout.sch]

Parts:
C2: 1.0uF; 0603
FD1, FD2: FIDUCIAL1X2; FIDUCIAL-1X2
FRAME1: FRAME-LETTER; CREATIVE_COMMONS
H2, H4: STAND-OFF
J2: CONN_031X03_NO_SILK; 1X03_NO_SILK
J8: I2C_STANDARD_NO_SILK; 1X04_NO_SILK
JP1: JUMPER-SMT_3_2-NC_TRACE_SILK; SMT-JUMPER_3_2-NC_TRACE_SILK
JP2: JUMPER-SMT_2_NO_SILK; SMT-JUMPER_2_NO_SILK
LOGO1: SFE_LOGO_FLAME.2_INCH; SFE_LOGO_FLAME_.2
LOGO4: OSHW-LOGOS; OSHW-LOGO-S
R1, R6: 100k; 0603
R2, R13, R14: 4.7k; 0603
R10: 10k; 0603
R12: 10k; AXIAL-0.1
U2: CCS811; LGA10

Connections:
3.3V: C2.1, J8.2, JP1.2, R2.2, R6.2, R10.2, U2.6 (VDD)
!INT: J2.2, U2.3 (!INT!)
!RST: J2.3, R2.1, U2.2 (!RESET!)
!WAKE: J2.1, R1.2, U2.7 (!WAKE!)
AUX: R10.1, R12.P$1 (1), U2.8 (AUX)
CCS811_ADDR: JP2.2, R6.1, U2.1 (ADDR)
GND: C2.2, J8.1, JP2.1, R1.1, U2.EP (GND)
unnamed: JP1.3, R13.2
unnamed: JP1.1, R14.2
NTC_SENSE: R12.P$2 (2), U2.4 (PWM), U2.5 (SENSE)
SCL: J8.4, R14.1, U2.10 (SCL)
SDA: J8.3, R13.1, U2.9 (SDA)

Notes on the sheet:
VDD Range: 1.8-3.3V Max Current: 14mA (estimate)
CCS811 Air Quality Breakout
JP2 sets the I2C address of the CCS811. Open (Default) - 0x5B Closed - 0x5A
JP5 connects SDA and SCL to 4.7k pull-up resistors.
v10
Nathan Seidle
Optional external 10K thermistor SparkFun SKU: SEN-00250
Ports
Thermistor
Sensor (CO2 and TVOC)



Board: 2 copper layers, 17.8 x 17.8 mm, 20 parts (4 on the bottom side), 12 nets.

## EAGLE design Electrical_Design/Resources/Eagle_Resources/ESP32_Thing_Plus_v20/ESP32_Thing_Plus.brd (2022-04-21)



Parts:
C1: 10uF; 0603
C6, C19: 4.7uF; 0603
C7: 1.0uF; 0603
C10: 1.0uF; 0402
D1: Yellow; LED-0603
D2: 1A/23V/620mV; SOD-323
D3: BLUE; LED-0603
FD1, FD2, FD3, FD4: FIDUCIALUFIDUCIAL; FIDUCIAL-MICRO
FRAME1: FRAME-LEDGER; CREATIVE_COMMONS
H1, H2: STAND-OFFTIGHT; STAND-OFF-TIGHT
J2: CONN_12SM_SQ_NO_SILK; 1X12_SM_SQ_NOSILK
J3: QWIIC_CONNECTORJS-1MM; 1X04_1MM_RA
J4: CONN_161X16_SM_SQ_NOSILK; 1X16_SM_SQ_NOSILK
J5: USB_MICRO-B_HALF_PTH_MILL; USB-MICROB-PTH-MILL
JP2: LiPo; JST-2-SMD
LOGO1: SFE_LOGO_FLAME.1_INCH; SFE_LOGO_FLAME_.1
LOGO2: OSHW-LOGOMINI; OSHW-LOGO-MINI
LOGO3: SFE_LOGO_NAME_FLAME.1_INCH; SFE_LOGO_NAME_FLAME_.1
LOGO4: FOUR_LAYER_WARNING
Q1: 2.5A/30V; SOT23-3@1
Q2: MBT3904DW1T1; SC70-6
R1, R4: 1k; 0603
R2, R7, R17, R18: 10k; 0603
R3: 1K; 0603
R5: 10; 0603
R6: 2.0k; 0603
R8: 100K; 0402
S1: RESET; TACTILE_SWITCH_SMD_4.6X2.8MM
S2: 0; TACTILE_SWITCH_SMD_4.6X2.8MM
TP1: TEST-POINTTP_15TH_THRU; TP_15TH
U1: MCP73831; SOT23-5
U2: ESP-WROOM-32NARROW; ESP-WROOM-32-NARROW
U3: AP2112K-3.3V; SOT23-5
U4: CP2102N; QFN24

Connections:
0: Q2.6 (C), S2.4, TP1.P$1, U2.25 (IO0)
3.3V: C1.1, C10.1, J3.2, J4.2, R1.1, R2.2, U2.2 (3V3), U3.5 (OUT), U4.5 (VIO), U4.6 (VDD)
12: J2.5, U2.14 (IO12)
13: J2.4, R4.1, U2.16 (IO13)
14: J2.10, U2.13 (IO14)
15: J2.8, U2.23 (IO15)
16: J4.14, U2.27 (IO16)
17: J4.15, U2.28 (IO17)
20: U2.32 (IO20)
21: J4.16, U2.33 (IO21)
27: J2.6, U2.12 (IO27)
32: J2.9, U2.8 (IO32)
33: J2.7, U2.9 (IO33)
A0: J4.5, U2.11 (IO26)
A1: J4.6, U2.10 (IO25)
A2: J4.7, U2.6 (IO34)
A3: J4.8, U2.5 (SENSOR_VN)
A4: J4.9, U2.4 (SENSOR_VP)
A5: J4.10, U2.26 (IO4)
CHG: D1.C, U1.1 (STAT)
CHIP_PU: J4.1, Q2.3 (C), R2.1, S1.4, U2.3 (EN)
D+: J5.D+, U4.3 (D+)
D-: J5.D-, U4.4 (D-)
DTR: Q2.1 (E), R17.1, U4.23 (DTR)
EN: J2.2, R8.2, U3.3 (EN)
GND: C1.2, C6.2, C7.2, C10.2, C19.2, D3.C, J3.1, J4.4, J5.GND, JP2.1 (2), R6.1, R7.1, S1.1, S2.1, U1.2 (VSS), U2.1 (GND), U2.15 (GND), U2.38 (GND), U2.GND, U3.2 (GND), U4.2 (GND), U4.PAD (GND)
MISO: J4.13, U2.31 (IO19)
MOSI: J4.12, U2.30 (IO18)
unnamed: R1.2, U4.9 (!RSTB)
unnamed: D3.A, R4.2
unnamed: R5.2, U4.7 (VREGIN), U4.8 (VBUS)
unnamed: Q2.5 (B), R17.2
unnamed: Q2.2 (B), R18.2
unnamed: R6.2, U1.5 (PROG)
unnamed: D1.A, R3.2
RTS: Q2.4 (E), R18.1, U4.19 (RTS)
RX: U2.35 (TXD), U4.20 (RXD)
SCK: J4.11, U2.29 (IO5)
SCL: J2.11, J3.4, U2.36 (IO22)
SDA: J2.12, J3.3, U2.37 (IO23)
TX: U2.34 (RXD), U4.21 (TXD)
VIN: C7.1, D2.C, Q1.2 (S), R8.1, U3.1 (IN)
V_BATT: C6.1, J2.1, JP2.2 (1), Q1.3 (D), U1.3 (VBAT)
V_USB: C19.1, D2.A, J2.3, J5.VBUS, Q1.1 (G), R3.1, R5.1, R7.2, U1.4 (VIN)

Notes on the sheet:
Boot Mode Configuration Pin Default Boot Download GPIO0 1 1 0 U0TXD 1 1 x GPIO2 0 x 0 GPIO4 0 x x MTDO 1 x x GPIO5 1 1 x If U0TXD, GPIO2, GPIO5 are floating, GPIO0 determines boot mode
CP2102N (USB-to-Serial Converter)
V_BATT should be a single- cell LiPo battery.
Charge current: I_CHG = 1000 / R_PROG R_PROG=2k : I_CHG=500mA
Voltage Regulator and Battery Charger
Lithium-Polymer Battery Charger (1-cell)
600mA out 6V max in
Auto-Reset
Espressif ESP32
Reset Button
Headers
v20
Original ESP32 Thing by Jim Lindblom
If DTR is LOW, toggling RTS from HIGH to LOW resets to run mode. If RTS is HIGH, toggling DTR from LOW to HIGH resets to bootloader.
QWIIC Connector
Mike Hord
GPIO13 LED
GPIO0 Button
Revised by: Alex Wende
V_USB - 6V MAX V_BATT - Single Cell (4.2V MAX)

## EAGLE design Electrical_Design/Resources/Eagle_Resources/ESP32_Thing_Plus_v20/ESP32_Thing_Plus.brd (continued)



Board: 4 copper layers, 22.9 x 58.4 mm, 107 parts (32 on the bottom side), 43 nets.

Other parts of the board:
U$1: #RESET0
U$2: 3V31
U$3: 1323
U$4: 1417
U$5: 1519
U$6: 16#RX11
U$7: 17#TX10
U$8: 121
U$9: 210
U$10: 2721
U$11: 3218
U$12: 3320
U$13: A03
U$14: A14
U$15: A25
U$16: A36
U$17: A47
U$18: A58
U$19: EN26
U$20: GND2
U$21: 22#SCL1
U$22: 23#SDA0
U$23: QWIIC27
U$27: VBAT25
U$28: VUSB24
U$29: SDA1
U$30: SCL0
U$31: 142
U$32: 323
U$33: 154
U$34: 335
U$35: 276
U$36: 127
U$37: 138
U$38: 219
U$39: 1710
U$40: 1611
U$41: A515
U$42: A416
U$43: A317
U$44: A218
U$45: A119
U$46: A020
U$47: SCK20
U$48: GND21
U$49: NC22
U$50: VUSB8
U$51: EN9
U$52: VBAT10
U$53: 137
U$54: MISO0
U$55: MOSI1
U$56: CHG1
U$57: RESET0
U$58, U$65: ESP32_THING_PLUS0
U$59: ORDERING_INSTRUCTIONS
U$60: 3V323
U$61: RST24
U$62: 00
U$63: 5#SCK2
U$64: NC0
U$66: 18#MOSI1
U$67: 19#MISO0

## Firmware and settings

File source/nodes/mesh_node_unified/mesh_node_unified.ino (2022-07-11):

#include <Wire.h>
#include <Adafruit_Sensor.h>
#include <Adafruit_BME280.h>
#include <Adafruit_CCS811.h>
#include <Adafruit_INA219.h>
#include <QMC5883LCompass.h>
#include <painlessMesh.h>
#include <DallasTemperature.h>
#include <ArduCAM.h>
#include <SPI.h>
#include "memorysaver.h"`
//#include <ArduinoJson.h>

#define   MESH_PREFIX     "ram"
#define   MESH_PASSWORD   "SeniorDesign1"
#define   MESH_PORT       5555

#define WIND_SPEED_PIN 39
#define WIND_DIR_PIN 34
#define SOIL_PIN 36
#define DS18_PIN 17
#define CAMERA_CS 5

Scheduler userScheduler;
painlessMesh mesh;
Adafruit_INA219 ina;
Adafruit_BME280 bme;
Adafruit_CCS811 ccs;
QMC5883LCompass compass;
OneWire oneWire(DS18_PIN);
DallasTemperature ds18(&oneWire);

#if !(defined OV2640_MINI_2MP_PLUS)
  #error Please select the hardware platform and camera module in the ../libraries/ArduCAM/memorysaver.h file
#endif

ArduCAM myCAM( OV2640, CAMERA_CS );
uint8_t read_fifo_burst(ArduCAM myCAM);

bool is_header = false;
int mode = 0;
uint8_t start_capture = 0;

//DynamicJsonDocument pixelData(16384);
StaticJsonDocument<25000> pixelData;
JsonArray pixels = pixelData.createNestedArray("pixels");

DynamicJsonDocument data(4096);

volatile unsigned int pulses = 0;
const float WIND_SPEED_CONST = 1.0;

const float WIND_DIR_MIN = 0.0;
const float WIND_DIR_MAX = 4000.0;
const float WIND_DIR_DEG_PER_COUNT = 1.0;

void getNodeIdData();
void getConnectionStrength();
void getPowerData();
void getAtmosphericData();
void getAirQualityData();
void getSoilMoisture();
void getWindSpeed();
void getWindDirection();
void getCompassData();
float getCalibratrionTemperature();

void(* resetFunc) (void) = 0;

void send_pixel_stats(uint32_t from, int packetNumber);
int capture();
void send_pixel_packet(uint32_t from);

String allSensorDataString();

// Needed for painless library
void receivedCallback( uint32_t from, String &msg ) {
  Serial.printf("Received from %u msg=%s\n", from, msg.c_str());
  Serial.println(msg);
//  String message = (String)msg;
//  Serial.println(message);
  if (msg == "image")
  {
    Serial.println("Starting Capture");
    capture(from);
  }
  else if (msg == "reset")
  {
    resetFunc();
  }
  else
  {
    mesh.sendSingle(from, allSensorDataString());
  }
  
}


void setup() 
{
  uint8_t vid, pid;
  uint8_t temp;
  
  Wire.begin();
  Serial.begin(115200);

  ina.begin();
  bme.begin(0x76); // pass the default address otherwise the sensor is not found
  ccs.begin();
  compass.init();
  ds18.begin();

  pinMode(WIND_SPEED_PIN, INPUT);

  pinMode(WIND_DIR_PIN, INPUT);

  pinMode(SOIL_PIN, INPUT);
  
  pinMode(CAMERA_CS, OUTPUT);
  digitalWrite(CAMERA_CS, HIGH);
  SPI.begin();

  
  bme.setSampling(Adafruit_BME280::MODE_NORMAL,
                    Adafruit_BME280::SAMPLING_X2,  // temperature
                    Adafruit_BME280::SAMPLING_X16, // pressure
                    Adafruit_BME280::SAMPLING_X1,  // humidity
                    Adafruit_BME280::FILTER_X16,
                    Adafruit_BME280::STANDBY_MS_0_5 );

  //Reset the CPLD
  myCAM.write_reg(0x07, 0x80);
  delay(100);
  myCAM.write_reg(0x07, 0x00);
  delay(100);

  for (int i = 0; i < 15; i++)
  {
    //Check if the ArduCAM SPI bus is OK
    myCAM.write_reg(ARDUCHIP_TEST1, 0x55);
    temp = myCAM.read_reg(ARDUCHIP_TEST1);
    if (temp != 0x55){
      Serial.println(F("ACK CMD SPI interface Error! END"));
      delay(1000);continue;
    }else{
      Serial.println(F("ACK CMD SPI interface OK. END"));break;
    }
  }

  #if defined (OV2640_MINI_2MP_PLUS)
    for (int i = 0; i < 15; i++)
    {
      //Check if the camera module type is OV2640
      myCAM.wrSensorReg8_8(0xff, 0x01);
      myCAM.rdSensorReg8_8(OV2640_CHIPID_HIGH, &vid);
      myCAM.rdSensorReg8_8(OV2640_CHIPID_LOW, &pid);
      if ((vid != 0x26 ) && (( pid != 0x41 ) || ( pid != 0x42 ))){
        Serial.println(F("ACK CMD Can't find OV2640 module! END"));
        delay(1000);continue;
      }
      else{
        Serial.println(F("ACK CMD OV2640 detected. END"));break;
      } 
    }
  #endif

  myCAM.set_format(JPEG);
  myCAM.InitCAM();
  myCAM.OV2640_set_JPEG_size(OV2640_352x288);
  delay(1000);
  myCAM.clear_fifo_flag();
  #if !(defined (OV2640_MINI_2MP_PLUS))
    myCAM.write_reg(ARDUCHIP_FRAMES,0x00);
  #endif
//  myCAM.set_bit(ARDUCHIP_GPIO,GPIO_PWDN_MASK);  


  mesh.setDebugMsgTypes( ERROR | STARTUP | CONNECTION );  // set before init() so that you can see startup messages
  mesh.init( MESH_PREFIX, MESH_PASSWORD, &userScheduler, MESH_PORT );
  mesh.setContainsRoot(true);
  mesh.onReceive(&receivedCallback);
  Serial.print("Node_ID: ");
  Serial.println(mesh.getNodeId());

  ccs.setDriveMode(CCS811_DRIVE_MODE_60SEC);
}

void loop() 
{
  uint8_t temp = 0xff, temp_last = 0;
  bool is_header = false;

  mesh.update();

}


String allSensorDataString()
{
  getNodeIdData();
  getConnectionStrength();
  getPowerData();
  getAtmosphericData();
  getAirQualityData();
  getSoilMoisture();
  getWindSpeed();
  getWindDirection();
  getCompassData();
  getCalibrationTemperature();

  String str = "";
  serializeJson(data, str);
  return str;
}

void getNodeIdData()
{
  data["node_id"] = mesh.getNodeId();
}

void getConnectionStrength()
{
  data["connection_strength"] = WiFi.RSSI(0);
}

void getPowerData()
{
  data["bus_voltage_V"] = ina.getBusVoltage_V();
  data["shunt_voltage_mV"] = ina.getShuntVoltage_mV();
  data["current_mA"] = ina.getCurrent_mA();
  data["power_mW"] = ina.getPower_mW();
}

void getAtmosphericData()
{
//  getTemperatureOffset();
//  bme.setTemperatureCompensation(data["offset_temperature"]);
//  data["bme_offset_temperature"] = bme.getTemperatureCompensation();
  bme.takeForcedMeasurement();
  float temperature = bme.readTemperature();
  float humidity = bme.readHumidity();
  data["air_temperature_C"] = temperature;
  data["humidity"] = humidity;
  data["air_pressure_Pa"] = bme.readPressure();
  ccs.setEnvironmentalData(humidity, temperature);
}

void getAirQualityData()
{
  ccs.readData();
  data["co2_ppm"] = ccs.geteCO2();
  data["tvoc_ppb"] = ccs.getTVOC();
}

void getSoilMoisture()
{
  data["soil_moisture_adc"] = analogRead(SOIL_PIN);
}

void countPulses()
{
  pulses++;
}

void getWindSpeed()
{
  unsigned long timeout = 1000000;
//  int cal_factor = 585000;
  int count = 2;
  String raw_data = "";
  
  for (int i = 0; i < count; i++)
  {
    raw_data += String(pulseIn(WIND_SPEED_PIN, LOW, timeout));
    if (i < count - 1)
    {
      raw_data += "?";
    }
  }

  data["wind_speed_raw"] = raw_data;
}

void getWindDirection()
{
  unsigned long timeout = 1000000;
  int count = 2;
  String raw_data = "";

  for (int i = 0; i < count; i++)
  {
    raw_data += String(pulseIn(WIND_DIR_PIN, LOW, timeout));
    if (i < count - 1)
    {
      raw_data += "?";
    }
  }
  data["wind_direction_raw"] = raw_data;
}

void getCompassData()
{
  char direction[3];
  compass.read();
  data["azimuth"] = compass.getAzimuth(); 
  data["bearing"] = compass.getBearing(data["azimuth"]); // This will divide the 360 range of the compass into 16 parts and return a value of 0-15 in clockwise order
  // compass.getDirection(direction, data["azimuth"]); // NSEW letters
  // data["direction"] = String(direction);
}

void getCalibrationTemperature()
{
  ds18.requestTemperatures();
  float temp = ds18.getTempCByIndex(0);
  data["calibration_temperature"] = temp;
//  if (temp == DEVICE_DISCONNECTED_C)
//  {
//    data["calibration_temperature"] = false;
//    return bme.readTemperature();
//  }
//  else
//  {
//    data["calibration_temperature"] = temp;
//    return temp;
//  }
}

//float getTemperatureOffset()
//{
//  float bme_temp = bme.readTemperature();
//  data["air_temperature_C"] = bme_temp;
//  float offset = getCalibrationTemperature() - bme_temp;
//  data["offset_temperature"] = offset;
//  return offset;
//}


int capture(uint32_t from)
{
//  myCAM.clear_bit(ARDUCHIP_GPIO,GPIO_PWDN_MASK);
//  delay(50);
  myCAM.OV2640_set_Light_Mode(Auto);
  uint8_t temp = 0xff;
  uint8_t temp_last = 0;
  uint32_t length = 0;
  //Check if the ArduCAM SPI bus is OK
  myCAM.write_reg(ARDUCHIP_TEST1, 0x55);
  temp = myCAM.read_reg(ARDUCHIP_TEST1);
  if (temp != 0x55){
    Serial.println(F("ACK CMD SPI interface Error! END"));
    delay(1000);
  }else{
    Serial.println(F("ACK CMD SPI interface OK. END"));
  }
  temp = 0xff;
  myCAM.flush_fifo();
  myCAM.clear_fifo_flag();
  //Start capture
  myCAM.OV2640_set_Light_Mode(Auto);
  Serial.println("Capture Start");
  myCAM.start_capture();
  delay(500);
  Serial.print("Status Bit:");
  Serial.println(myCAM.get_bit(ARDUCHIP_TRIG, CAP_DONE_MASK));

  if (myCAM.get_bit(ARDUCHIP_TRIG, CAP_DONE_MASK))
  {
    Serial.println(F("ACK CMD CAM Capture Done. END"));delay(50);
    temp = 0;
    length = myCAM.read_fifo_length();
    Serial.println(length, DEC);
    if (length >= MAX_FIFO_SIZE) //512 kb
    {
      Serial.println(F("ACK CMD Over size. END"));
      return 0;
    }
    if (length == 0 ) //0 kb
    {
      Serial.println(F("ACK CMD Size is 0. END"));
      return 0;
    }
    myCAM.CS_LOW();
    myCAM.set_fifo_burst();//Set fifo burst mode
    temp =  SPI.transfer(0x00);
    length --;
    int count = 0;
    int packetNumber = 0;
    initialize_pixel_data(0);
    while ( length-- )
    {
      if (count >= 1000)
      {
        send_pixel_packet(from);
        packetNumber++;
        initialize_pixel_data(packetNumber);
        count = 0;
      }
      temp_last = temp;
      temp =  SPI.transfer(0x00);
      if (is_header == true)
      {
//        Serial.write(temp);
        pixels.add(temp);
        count++;
      }
      else if ((temp == 0xD8) & (temp_last == 0xFF))
      {
        is_header = true;
//        Serial.println(F("ACK IMG END"));
//        Serial.write(temp_last);
        pixels.add(temp_last);
        count++;
//        Serial.write(temp);
        pixels.add(temp);
        count++;
      }
      if ( (temp == 0xD9) && (temp_last == 0xFF) ) //If find the end ,break while,
      {
        send_pixel_packet(from);
        send_pixel_stats(from, packetNumber);
        break;
      }
      delayMicroseconds(15);
    }
    myCAM.CS_HIGH();
    is_header = false;
    myCAM.clear_fifo_flag();
    delay(20);
//    myCAM.set_bit(ARDUCHIP_GPIO,GPIO_PWDN_MASK);  
  }
  return 1;
}


void initialize_pixel_data(long packetNumber)
{
  pixelData.clear();
  pixelData["node_id"] = mesh.getNodeId();
  pixelData["packet_number"] = packetNumber;
  pixels = pixelData.createNestedArray("pixels");
}


void send_pixel_packet(uint32_t from)
{
  String str = "";
  serializeJson(pixelData, str);
  Serial.println(str);
  mesh.sendSingle(from, str);
}

void send_pixel_stats(uint32_t from, int packetNumber)
{
  String message = "{\"node_id\": ";
  message = message + mesh.getNodeId() + ", \"total_packets_sent\": " + packetNumber + "}";
  mesh.sendSingle(from, message);
}

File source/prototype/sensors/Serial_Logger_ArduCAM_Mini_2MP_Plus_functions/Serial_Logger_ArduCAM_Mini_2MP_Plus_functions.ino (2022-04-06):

// ArduCAM Mini demo (C)2017 Lee
// Web: http://www.ArduCAM.com
// This program is a demo of how to use most of the functions
// of the library with ArduCAM Mini camera, and can run on any Arduino platform.
// This demo was made for ArduCAM_Mini_2MP_Plus.
// It needs to be used in combination with PC software.
// It can test OV2640 functions
// This program requires the ArduCAM V4.0.0 (or later) library and ArduCAM_Mini_2MP_Plus
// and use Arduino IDE 1.6.8 compiler or above
#include <Wire.h>
#include <ArduCAM.h>
#include <SPI.h>
#include "memorysaver.h"

uint8_t serialLog[1024];
int logIndex = 0;

//This demo can only work on OV2640_MINI_2MP_PLUS platform.
#if !(defined OV2640_MINI_2MP_PLUS)
  #error Please select the hardware platform and camera module in the ../libraries/ArduCAM/memorysaver.h file
#endif
#define BMPIMAGEOFFSET 66
const char bmp_header[BMPIMAGEOFFSET] PROGMEM =
{
  0x42, 0x4D, 0x36, 0x58, 0x02, 0x00, 0x00, 0x00, 0x00, 0x00, 0x42, 0x00, 0x00, 0x00, 0x28, 0x00,
  0x00, 0x00, 0x40, 0x01, 0x00, 0x00, 0xF0, 0x00, 0x00, 0x00, 0x01, 0x00, 0x10, 0x00, 0x03, 0x00,
  0x00, 0x00, 0x00, 0x58, 0x02, 0x00, 0xC4, 0x0E, 0x00, 0x00, 0xC4, 0x0E, 0x00, 0x00, 0x00, 0x00,
  0x00, 0x00, 0x00, 0x00, 0x00, 0x00, 0x00, 0xF8, 0x00, 0x00, 0xE0, 0x07, 0x00, 0x00, 0x1F, 0x00,
  0x00, 0x00
};
// set pin 7 as the slave select for the digital pot:
const int CS = 5;
bool is_header = false;
int mode = 0;
uint8_t start_capture = 0;
#if defined (OV2640_MINI_2MP_PLUS)
  ArduCAM myCAM( OV2640, CS );
#else
  ArduCAM myCAM( OV5642, CS );
#endif
uint8_t read_fifo_burst(ArduCAM myCAM);
void setup() {
// put your setup code here, to run once:
uint8_t vid, pid;
uint8_t temp;
#if defined(__SAM3X8E__)
  Wire1.begin();
  Serial.begin(115200);
#else
  Wire.begin();
  Serial.begin(115200);
#endif
Serial.println(F("ACK CMD ArduCAM Start! END"));
// set the CS as an output:
pinMode(CS, OUTPUT);
digitalWrite(CS, HIGH);
// initialize SPI:
SPI.begin();
  //Reset the CPLD
myCAM.write_reg(0x07, 0x80);
delay(100);
myCAM.write_reg(0x07, 0x00);
delay(100);
while(1){
  //Check if the ArduCAM SPI bus is OK
  myCAM.write_reg(ARDUCHIP_TEST1, 0x55);
  temp = myCAM.read_reg(ARDUCHIP_TEST1);
  if (temp != 0x55){
    Serial.println(F("ACK CMD SPI interface Error! END"));
    delay(1000);continue;
  }else{
    Serial.println(F("ACK CMD SPI interface OK. END"));break;
  }
}

#if defined (OV2640_MINI_2MP_PLUS)
  while(1){
    //Check if the camera module type is OV2640
    myCAM.wrSensorReg8_8(0xff, 0x01);
    myCAM.rdSensorReg8_8(OV2640_CHIPID_HIGH, &vid);
    myCAM.rdSensorReg8_8(OV2640_CHIPID_LOW, &pid);
    if ((vid != 0x26 ) && (( pid != 0x41 ) || ( pid != 0x42 ))){
      Serial.println(F("ACK CMD Can't find OV2640 module! END"));
      delay(1000);continue;
    }
    else{
      Serial.println(F("ACK CMD OV2640 detected. END"));break;
    } 
  }
#else
  while(1){
    //Check if the camera module type is OV5642
    myCAM.wrSensorReg16_8(0xff, 0x01);
    myCAM.rdSensorReg16_8(OV5642_CHIPID_HIGH, &vid);
    myCAM.rdSensorReg16_8(OV5642_CHIPID_LOW, &pid);
    if((vid != 0x56) || (pid != 0x42)){
      Serial.println(F("ACK CMD Can't find OV5642 module! END"));
      delay(1000);continue;
    }
    else{
      Serial.println(F("ACK CMD OV5642 detected. END"));break;
    } 
  }
#endif
//Change to JPEG capture mode and initialize the OV5642 module
myCAM.set_format(JPEG);
myCAM.InitCAM();
#if defined (OV2640_MINI_2MP_PLUS)
  myCAM.OV2640_set_JPEG_size(OV2640_320x240);
#else
  myCAM.write_reg(ARDUCHIP_TIM, VSYNC_LEVEL_MASK);   //VSYNC is active HIGH
  myCAM.OV5642_set_JPEG_size(OV5642_320x240);
#endif
delay(1000);
myCAM.clear_fifo_flag();
#if !(defined (OV2640_MINI_2MP_PLUS))
myCAM.write_reg(ARDUCHIP_FRAMES,0x00);
#endif
}
void loop() {
// put your main code here, to run repeatedly:
uint8_t temp = 0xff, temp_last = 0;
bool is_header = false;
if (Serial.available())
{
  temp = Serial.read();
  serialLog[logIndex] = temp;
  logIndex++;
  if (logIndex >= 1024)
  {
    logIndex = 0;
  }
  Serial.println("--- Begin Serial Log Dump ---");
  for (int i = 0; i < logIndex; i++)
  {
    Serial.println(serialLog[i]);
  }
  Serial.println("--- End Serial Log Dump ---");
  
  switch (temp)
  {
    case 0:
      myCAM.OV2640_set_JPEG_size(OV2640_160x120);delay(1000);
      Serial.println(F("ACK CMD switch to OV2640_160x120 END"));
     temp = 0xff;
    break;
    case 1:
      myCAM.OV2640_set_JPEG_size(OV2640_176x144);delay(1000);
      Serial.println(F("ACK CMD switch to OV2640_176x144 END"));
    temp = 0xff;
    break;
    case 2: 
      myCAM.OV2640_set_JPEG_size(OV2640_320x240);delay(1000);
      Serial.println(F("ACK CMD switch to OV2640_320x240 END"));
    temp = 0xff;
    break;
    case 3:
    myCAM.OV2640_set_JPEG_size(OV2640_352x288);delay(1000);
    Serial.println(F("ACK CMD switch to OV2640_352x288 END"));
   temp = 0xff;
    break;
    case 4:
      myCAM.OV2640_set_JPEG_size(OV2640_640x480);delay(1000);
      Serial.println(F("ACK CMD switch to OV2640_640x480 END"));
    temp = 0xff;
    break;
    case 5:
    myCAM.OV2640_set_JPEG_size(OV2640_800x600);delay(1000);
    Serial.println(F("ACK CMD switch to OV2640_800x600 END"));
    temp = 0xff;
    break;
    case 6:
     myCAM.OV2640_set_JPEG_size(OV2640_1024x768);delay(1000);
     Serial.println(F("ACK CMD switch to OV2640_1024x768 END"));
    temp = 0xff;
    break;
    case 7:
    myCAM.OV2640_set_JPEG_size(OV2640_1280x1024);delay(1000);
    Serial.println(F("ACK CMD switch to OV2640_1280x1024 END"));
    temp = 0xff;
    break;
    case 8:
    myCAM.OV2640_set_JPEG_size(OV2640_1600x1200);delay(1000);
    Serial.println(F("ACK CMD switch to OV2640_1600x1200 END"));
     temp = 0xff;
    break;
    case 0x10:
    mode = 1;
    temp = 0xff;
    start_capture = 1;
    Serial.println(F("ACK CMD CAM start single shoot. END"));
    break;
    case 0x11: 
    temp = 0xff;
    myCAM.set_format(JPEG);
    myCAM.InitCAM();
    #if !(defined (OV2640_MINI_2MP_PLUS))
    myCAM.set_bit(ARDUCHIP_TIM, VSYNC_LEVEL_MASK);
    #endif
    break;
    case 0x20:
    mode = 2;
    temp = 0xff;
    start_capture = 2;
    Serial.println(F("ACK CMD CAM start video streaming. END"));
    break;
    case 0x30:
    mode = 3;
    temp = 0xff;
    start_capture = 3;
    Serial.println(F("ACK CMD CAM start single shoot. END"));
    break;
    case 0x31:
    temp = 0xff;
    myCAM.set_format(BMP);
    myCAM.InitCAM();
    #if !(defined (OV2640_MINI_2MP_PLUS))        
    myCAM.clear_bit(ARDUCHIP_TIM, VSYNC_LEVEL_MASK);
    #endif
    myCAM.wrSensorReg16_8(0x3818, 0x81);
    myCAM.wrSensorReg16_8(0x3621, 0xA7);
    break;
    case 0x40:
    myCAM.OV2640_set_Light_Mode(Auto);temp = 0xff;
    Serial.println(F("ACK CMD Set to Auto END"));break;
     case 0x41:
    myCAM.OV2640_set_Light_Mode(Sunny);temp = 0xff;
    Serial.println(F("ACK CMD Set to Sunny END"));break;
     case 0x42:
    myCAM.OV2640_set_Light_Mode(Cloudy);temp = 0xff;
    Serial.println(F("ACK CMD Set to Cloudy END"));break;
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

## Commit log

2022-03-11 Adds prototype ultrasonic anemometer v1 assembly -- Adds standalone ultrasonic sensor -- Adds UA STL files for printing
    [ua_body^ultrasonic_anemometer.STL, ua_lid^ultrasonic_anemometer.STL, ua_reflector^ultrasonic_anemometer.STL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]
2022-03-12 Adds source files -- Adds arduino board manager links for ESP boards
2022-03-19 Adds basic networking prototype for the aggregator and a node using painless mesh
2022-04-01 Adds source for solar chargin testing
    [solar_data_20220329_182313.csv, solar_data_20220329_182313.xlsx]
2022-04-02 Adds mesh node prototype with all sensors
2022-04-02 Adds basic parser for sensor mesh proto
2022-04-02 Updates mesh node - adds soil sensor - fixes pin numbers -- Fixes crash in python parser when garbage data arrives
    [current_monitor_aggregator.ino, mesh_node_all_sensors.ino, proto_all_sensors.py]
2022-04-02 Adds node ID to solar current sensor node message
2022-04-04 node_all_sensors.ino deprecated - replaced with mesh_node_all_sensors.ino
    [node_all_sensors.ino]
2022-04-04 Updates dev notes - hall effect sensor for wind speed - testing notes
2022-04-04 Adds early dev tool for visualizing sensor data -- example data graph
2022-04-04 Adds basic script for measuring ADC value from Melexis rotary position sensor
2022-04-04 Adds method for reading hall effect sensor RPM -- The pulses factor is a calculated value for 10,000rpm only - there are noise issues with the sensor itself - see dev_notes
    [hall_wind_speed.ino]
2022-04-05 Proof of concept for Arducam mini camera module - camera communicates - bytes are recieved - need to interpret data and save to correctly formatted file
    [cam_test.py]
2022-04-06 Script to read file in and print bytes -- used to get begining and end byte pattern of jpg
2022-04-06 Adds basic sketch to get soil moisture reading in ADC counts
2022-04-06 Adds sketch to print serial bytes
2022-04-06 Adds example graph of solar data with most of the outliers removed -- resulting data causes y axis scales to change - results in harder to read data - need to set a fixed scale
2022-04-06 Adds com port reverse engineering steps to camera section
2022-04-21 Adds Eagle Project -- Completes power system schematics
    [main_board.sch]
2022-04-21 Adds eagle libraries and reference schematics
    [B82462G4472M.stp, ESP32_Thing_Plus.brd, ESP32_Thing_Plus.sch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]
2022-04-21 Adds current sensor to power page -- Adds microcontroller page
    [EDI2CAP.CFG, MLX90316EGO-BCG-000-SP.stl, MLX90316EGO-BCG-000-SP.stp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]
2022-04-22 Completes schematic layout
    [main_board.sch]
2022-04-23 Begins main board layout
    [main_board.brd, main_board.sch]
2022-04-23 restored backup save file
    [main_board.brd, main_board_old.brd]
2022-04-24 Completes main board layout -- outstanding - isolate planes from divider line - remove planes from under esp antenna - generatre drc report
    [main_board.brd, main_board.sch]
2022-05-22 Updates Schematics - adds BOM
    [main_board.brd, main_board.sch]
2022-05-24 Adds module for controlling the mesh network - getting sensor data from nodes and inserting to database
2022-05-24 Adds initial database module for inserting and basic queries of databases -- adds sensor database for storing data from the nodes of the mesh network -- adds nodes database to store the configuration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
2022-05-30 Adds 3d model for circuit board solder paste fixture
    [solder_paste_frame.SLDPRT, solder_paste_frame.STL]
2022-05-31 Updates from day 1 of prototype build
    [main_board.sch]
2022-06-03 Adds ds18b20 temperature sensor -- Adds offset to bme280 temperature
2022-06-16 Updates main to loop getting sensor data instead of manually re-running
2022-06-16 First revision of single shot camera code
2022-06-17 Final camera only proto for sending packetized pixel data over mesh network - may need to mess with pixel data size on arduino for ram allocation
2022-06-17 Updates receive pixel data method - port.readall for pixel packets to avoid data loss -- Updates get image data for new format of packets - includes and adds metadata -- Updates method to update came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
    [mesh.py]
2022-06-22 Full Node Code - camera and all sensors
2022-06-22 Updates image example to print the most recent image for all nodes
2022-06-22 updates sleep modes for camera module -- changes duration of some delays for mesh timing
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2022-06-23 Adds copy/paste commands for using arduino serial monitor to debug python commands
2022-06-23 reduces image resolution to increase mesh stability
    [mesh_node_unified.ino]
2022-06-23 Adds dev tool for testing sending a full image as a single message - the result is that at 640x480 the compiler prevents the needed allocation of memory for the size of the message - the network may 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
    [mesh_img_single_msg.ino]
2022-06-24 Adds proto sensor data command
2022-06-24 Modifgies receive pixel data to prevent duplicate data on retry
    [mesh.py]
2022-06-24 Adds record of printouts during data duplication
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2022-06-25 Adds check to suspend image capture during nighttime -- fixes interval bug in development data gathering loop
    [mesh.py]
2022-06-25 Adds module to manipulate node sensor data for node details page
2022-06-25 Adds min and mak values for current sensor
2022-06-25 Adds method to update connected nodes config file -- temporarily disables sunlight check for suntime bug with sunset
    [mesh.py]
2022-06-26 Single Magnet - Updates calibration sketches with calibration constants
2022-06-27 Fixes bug - unpacking image data and metadata
    [mesh.py]
2022-06-27 Fixes bug - too many concurrent calls for temperature on BME280
    [mesh_node_unified.ino]
2022-06-27 Adds methods for humidity and pressure
2022-06-27 Adds methods - get date adjustable graph - get 24 hour temperature graph
2022-06-29 Comments out camera updater for night time
2022-06-29 Adds method to get min max and average by hour -- adds graph for min max and averate - only temperature implimented
2022-06-30 Adds connection strength for root node -- fixes bug on get topology retry where none type object was itterated
    [mesh.py]
2022-06-30 Adds signal strength to sensor data packet
2022-06-30 Adds custom css style for dbc radio-buttongroup
2022-06-30 Adds remaining graph types to get all select graph method -- reorders traces to fix key order
2022-07-01 Adds polling setting check to enable/disable sensor and image polling individually
2022-07-01 Adds methods to get node network status graph -- adds proto heatmap
2022-07-01 Updates navbar - logo - removes unused buttons - new styling -- adds mesh manager to paths -- adds callbacks for mesh management page
2022-07-02 Adds size printout to example images div
2022-07-02 Adds empty method for getting animated heatmap
2022-07-02 Adds config check and timestamp last updated for image and sensor update methods -- Fixes none type itteration in connection strength method
    [mesh.py]
2022-07-02 Updates bme280 mode - removes calibration - changes mode to forced as indoor navigation
2022-07-02 Adds image and sensor last updated configs
2022-07-02 Fixes max value lower than max measured for: pressure, co2 and tvoc
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2022-07-02 Adds cal log for 2 mag wind speed sensor
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2022-07-07 Adds manual removal of errors in wind data
    [database.py]
2022-07-10 Adds reset function -- sets ccs811 to 60 second measure interval -- sets ccs811 environment offsets -- changes wind speed to raw data string -- adds raw data string for wind direction string
    [mesh_node_unified.ino]
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2022-07-11 Updates camera init - no longer blocks startup if camera is not found
    [mesh_node_unified.ino]
2022-07-11 updates animated heatmap to work for multiple sensor data types
2022-07-11 Updates wind speed error removal
    [database.py]
2022-07-11 Updates sensor data method to convert wind speed and direction data on intake
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2022-07-20 Adds check if node is connected for sensor data update -- fixes wind direction raw key -- adds second check for junk data when getting sensor data
    [mesh.py]
2022-07-23 Fixes none instead of empty list when no nodes are connected -- Adds check for impossible CO2
    [mesh.py]
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2022-09-11 Adds STL files for final design prototype
    [Copy of Part1^anemometer rev2.STL, Copy of Part1^anemometer rev3.STL, Copy of Part1^anemometer rev4.STL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]
2022-09-11 Adds wind direction sensor electrical design
    [wind direction sensor.brd, wind direction sensor.sch]

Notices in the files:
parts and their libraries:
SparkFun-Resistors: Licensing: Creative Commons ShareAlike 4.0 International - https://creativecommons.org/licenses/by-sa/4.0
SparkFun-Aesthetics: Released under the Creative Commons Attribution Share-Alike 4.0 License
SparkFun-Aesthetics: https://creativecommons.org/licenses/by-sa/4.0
